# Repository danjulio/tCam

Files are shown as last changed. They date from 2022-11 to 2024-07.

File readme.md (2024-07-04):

## ESP32-based Thermal Imaging Cameras
tCam, tCam-Mini, tCam-POE and tCam-Eth are four cameras I designed around the ESP32 and Lepton 3.5.  They are designed to provide easy access to radiometric data from the Lepton.  Radiometric data is useful because it contains temperature information for each pixel in the camera's image allowing for all kinds of data analysis even if the image is stored to a file.

This repository was created on Nov 6, 2022 from the ESP32 section of my original [Lepton](https://github.com/danjulio/lepton) repository to reduce the size of the portion of that directory that most people are interested in.

### tCam
tCam is a full featured, battery powered camera with a local touchscreen display, local storage and a WiFi interface.  It is comprised of a [gCore]() and tCam-Mini.  A tCam kit can be purchased from Group Gets [here](https://store.groupgets.com/products/tcam-kit).

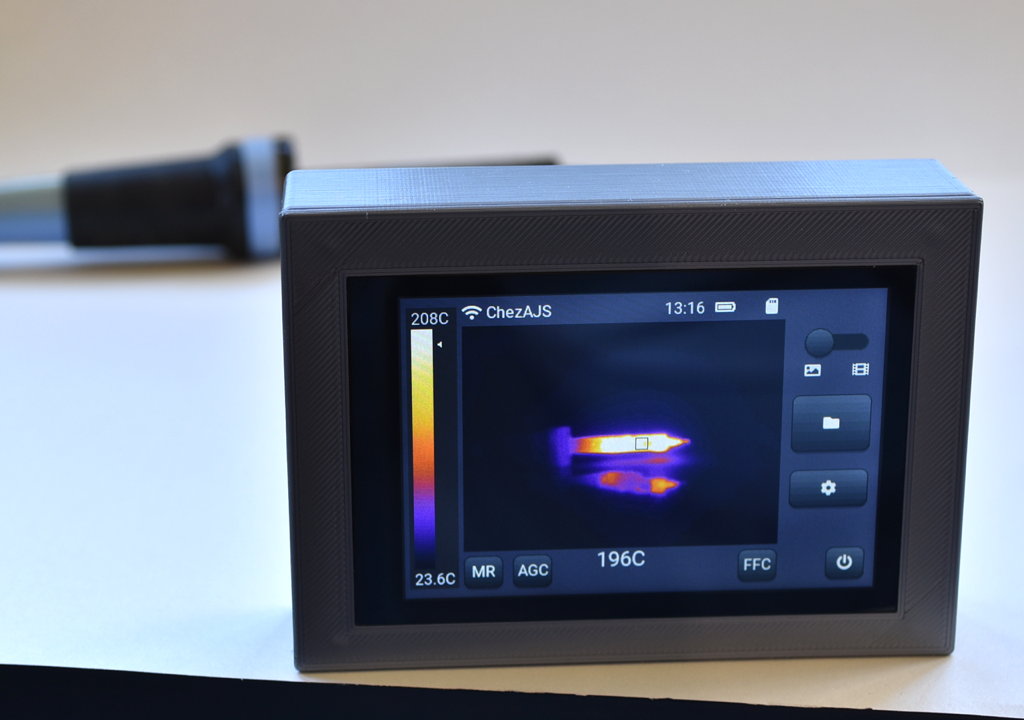
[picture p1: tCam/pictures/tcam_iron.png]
tCam


### tCam-Mini
tCam-Mini is a smaller camera designed for streaming and remote access.  It supports a Wifi or hardwired interface.  It can be built using development boards or a tested unit can be purchased from Group Gets [with built in antenna](https://store.groupgets.com/products/tcam-mini-rev4-wireless-streaming-thermal-camera-board) or [with an external antenna](https://store.groupgets.com/products/tcam-mini-rev4-external-antenna-wireless-streaming-thermal-camera-board).

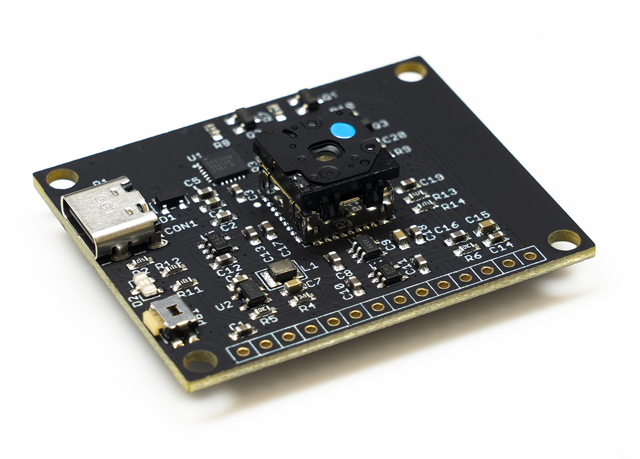
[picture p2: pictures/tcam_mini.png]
tCam-Mini

(Photo Credit: Matthew Navarro)

### tCam-POE
tCam-POE is a network only camera designed to work with hardwired POE connections (it also supports a Wifi connection).  At the moment, a grand total of six units have been built to validate the design (included here) or supply a custom order.

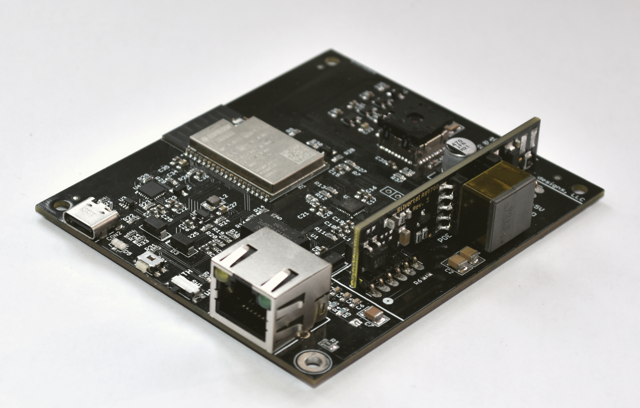
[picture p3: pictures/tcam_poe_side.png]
tCam-POE


### tCam-Eth
tCam-Eth is a ethernet connected camera designed to be incorporated with other electronics.  It was designed as part the [FireTIRS](https://github.com/jthompson2710/FireTIRS) project but is made available as an open source hardware design.

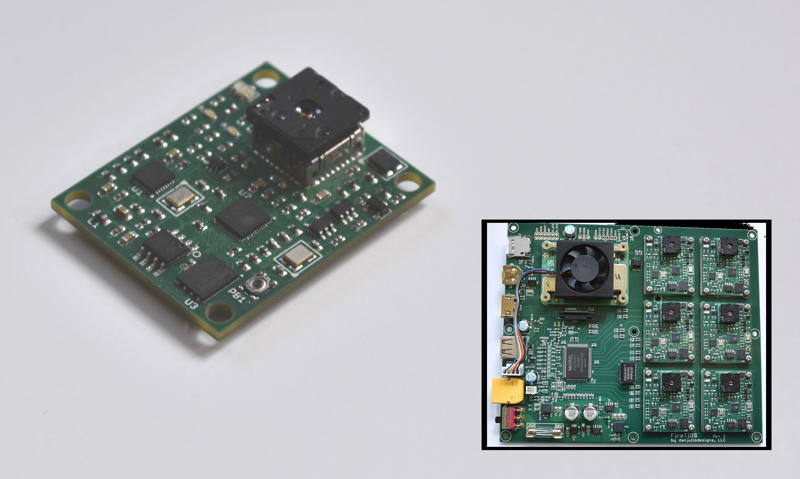
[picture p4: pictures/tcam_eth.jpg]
tCam-Eth


### Desktop Application
All three cameras share a common command set for remote access.  A companion Desktop computer application may be used to configure and access the cameras, download new firmware, as well as perform some analysis.

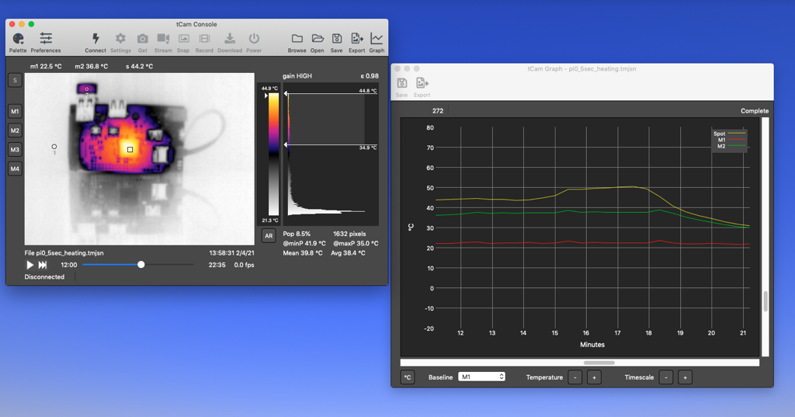
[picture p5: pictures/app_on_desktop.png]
Desktop Application


### Android Application
Connect, view and save images on an Android phone using the [Android App](https://play.google.com/store/apps/details?id=com.danjuliodesigns.tcamViewer) by Jim Turner.  The source may be found at the [repo](https://github.com/yaturner/tcamViewer-DanJulio).

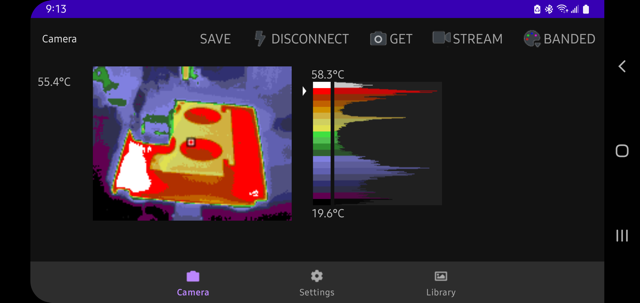
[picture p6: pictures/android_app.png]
Android App


### IOS Application
Connect, view and save images on an iPhone or iPad using the [IOS App](https://apps.apple.com/us/app/tcamview/id1610451813).  Documentation may be found on my [website](https://danjuliodesigns.com/products/tcam_app.html).

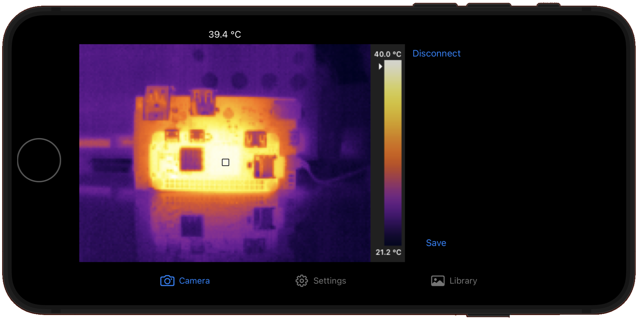
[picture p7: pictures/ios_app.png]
IOS App


### Web Server
A simple stand-alone server that can connect to multiple cameras, record images that meet certain criteria and display images from the cameras in a web browser.

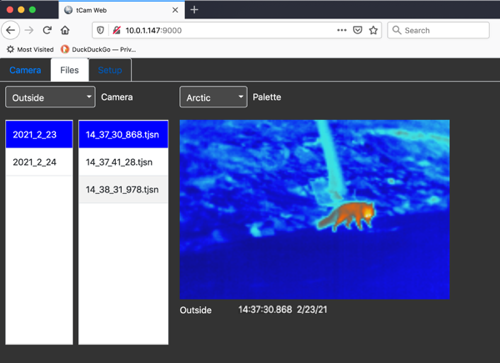
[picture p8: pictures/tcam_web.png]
Web Application


### Python Driver
A simple driver to allow access from python programs makes it easy to write your own software to access the cameras.  The python driver supports either a network connection to any camera, or a hardwired connection to tCam-Mini from a Raspberry Pi.

### R Driver
Bob Rudus wrote a R driver for tCam-Mini that can be found in his [github repository](https://github.com/hrbrmstr/tcam).

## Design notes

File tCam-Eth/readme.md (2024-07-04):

## tCam-Eth
tCam-Eth was developed for the [FireTIRS](https://github.com/jthompson2710/FireTIRS) project as a small ethernet connected thermal imaging camera.  It runs on 3.3V and exposes the TX and RX differential pairs from the ethernet PHY chip (it does not contain any magnetics), as well as a 3.3V logic serial interface.  It runs the tCam-Mini firmware, starting with version 3.0, and identifies as a tCam-POE device (configured for network operation).

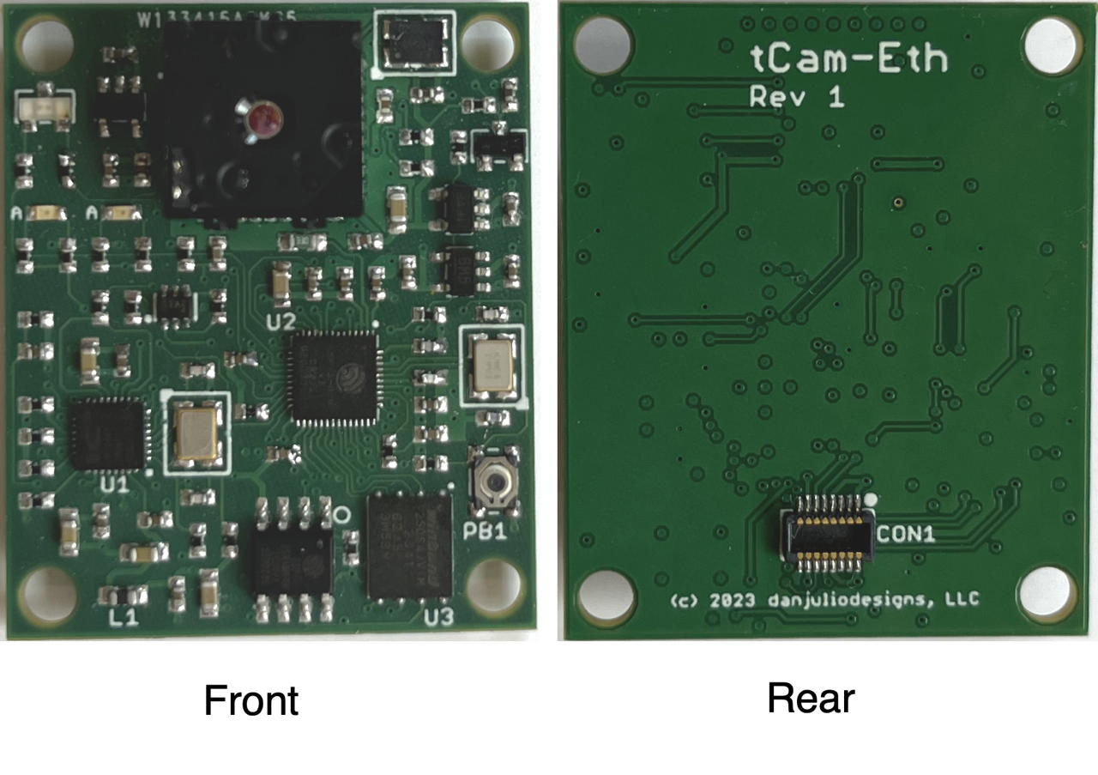
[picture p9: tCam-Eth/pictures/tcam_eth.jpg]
tCam-Eth Assembly


A baseboard containing a USB UART chip and Magjack RJ45 ethernet connector was also developed and is used for initial programming and test of tCam-Eth boards.

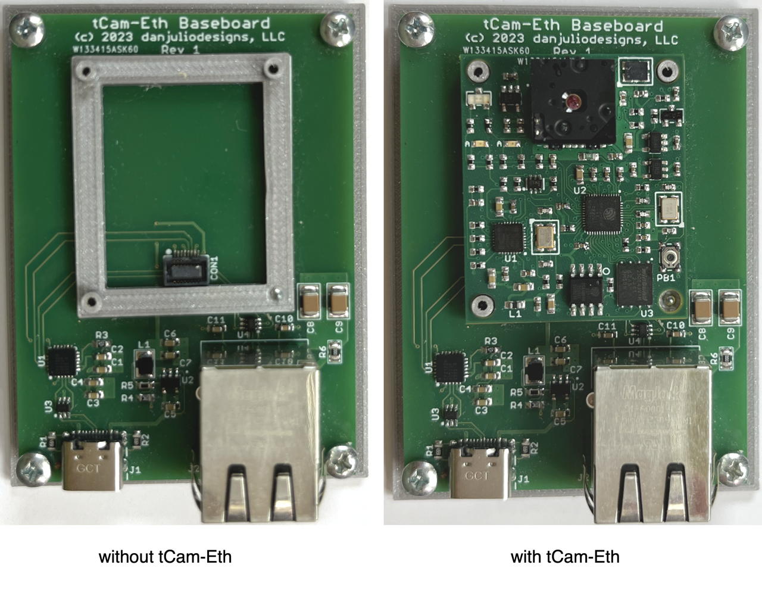
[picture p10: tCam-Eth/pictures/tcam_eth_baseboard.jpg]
tCam-Eth Baseboard Assembly


This directory contains the hardware design and documentation for both boards.

1. Eagle V7.7 design files.
2. Gerbers (including paste layer for stencils).
3. Bill-of-Material (BOM).
4. Additional electronics documentation such as printed schematics, reference designator drawings, load list, etc.
5. Supporting mechanical designs for spaces and base mounts.

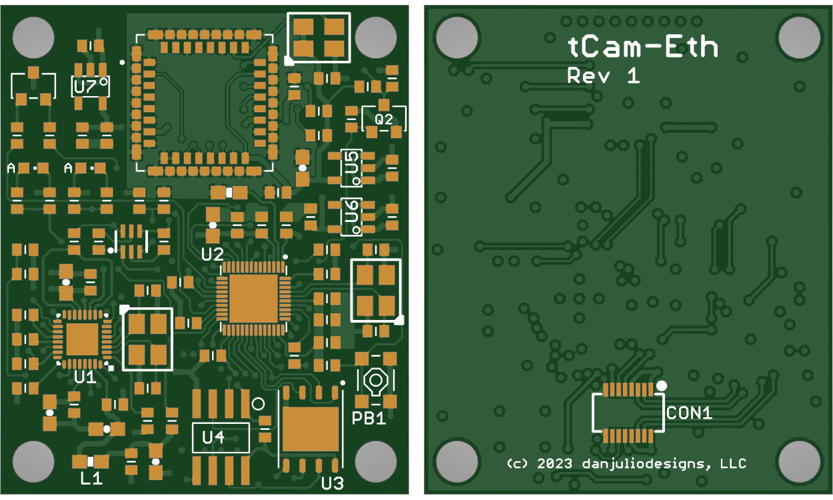
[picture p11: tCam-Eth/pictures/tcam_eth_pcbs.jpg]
tCam-Eth PCB Top


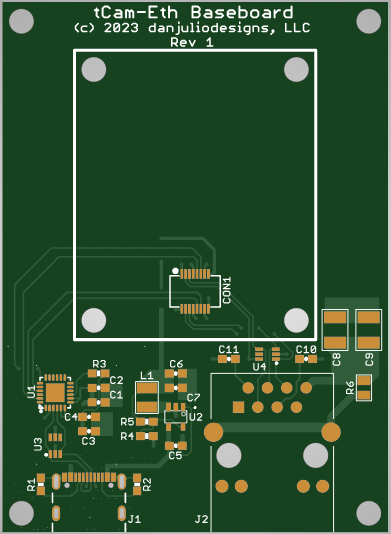
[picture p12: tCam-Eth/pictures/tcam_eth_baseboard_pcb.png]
tCam-Eth Baseboard PCB Component side


Please see the tCam-Mini directory for a detailed description of the command interface.

### Dimensions

tCam-Eth is 1.25 x 1.5" (31.75 x 38.10mm).

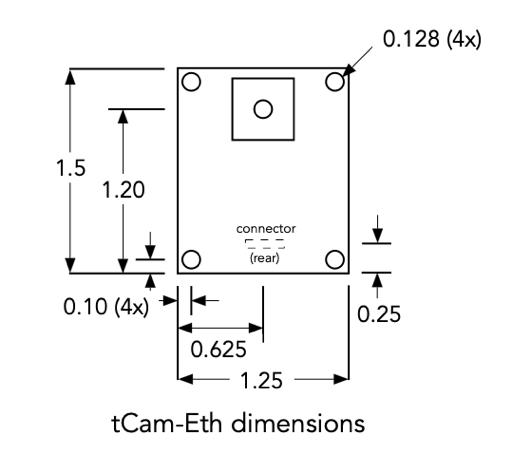
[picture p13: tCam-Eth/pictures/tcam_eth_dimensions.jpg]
tCam-Eth Dimensions


tCam-Eth Baseboard is 2 x 2.75" (50.8 x 69.85mm).

### Lepton Compatibility
tCam-Eth works with the following Lepton camera modules.

1. Lepton 3.0
2. Lepton 3.1R
3. Lepton 3.5

### Hardware Interfaces

#### tCam-Eth Hardware Interface
Connector CON1 (tCam-Eth PCB bottom) contains the following signals.

| Pin | Description |
| --- | --- |
| 1 | Ground |
| 2 | Ethernet TD+ (PHY output) |
| 3 | Ethernet TD- (PHY output) |
| 4 | Ground |
| 5 | Serial DTRN input (3.3V logic) |
| 6 | Serial RTSN input (3.3V logic) |
| 7 | Ground |
| 8 | +3.3V Power |
| 9 | +3.3V Power |
| 10 | Ground |
| 11 | Serial RX input (3.3V logic) |
| 12 | Serial TX output (3.3V logic) |
| 13 | Ground |
| 14 | Ethernet RX+ (PHY input) |
| 15 | Ethernet RX- (PHY input) |
| 16 | Ground |

The external 3.3V power supply must be regulated to +/- 5% and capable of supplying 500 mA (typical current consumption is < 200 mA).

#### tCam-Eth Baseboard Hardware Interfaces
Connector J1 is a USB-C connector used to provide power and serial communications.

Connector J2 is a RJ45 connector used to provide 10/100M bps ethernet communications.

### Operation
tCam-Eth is a command-based device.  It is designed for software running on another device to control it and receive responses and image data from it.  The command interface is described in the tCam-Mini firmware directory.

#### Ethernet Port
The ethernet port support an IEEE 803.2 10/100 Mbps ethernet interface.  tCam-Eth provides the direct TX and RX differential pairs from the on-board PHY chip.  It may be used in a direct connect fashion (as is done on the FireTIRS board) or with a traditional set of magnetics connected to an isolated RJ45 jack (as is done on the tCam-Eth Baseboard).

tCam-Eth can obtain a DHCP served address from a router on the network or may be configured with a static IP address.

#### Serial Port
tCam-Eth provides a 3.3V logic-level serial interface along with RTSN and DTRN flow-control inputs.  These are used to load firmware into the on-board ESP32 micro-controller (for example using the tCam-Eth Baseboard).  They may also be used to monitor the diagnostic serial output while the firmware is running.

#### Status Indicators
A dual-color (red/green) LED is used to communicate status (reference designator LED3).  Combinations of color and blinking patterns communicate various information.

| Status Indicator | Meaning |
| --- | --- |
| Off or Dim | Firmware did not start |
| Solid Red | Firmware is running: initializing and configuring the Lepton and Ethernet interface |
| Blinking Yellow | No ethernet network detected |
| Solid Yellow | Ethernet is connected and the camera has an IP address |
| Solid Green | Ethernet is connected and external software has connected via the socket interface |
| Fast Blink Yellow | Network Reset in progress |
| Alternating Red/Green | Over-the-air (network) FW update has been requested.  Press the button to initiate the update |
| Blinking Green | FW update in process (blinking my occur at irregular intervals as the Flash memory is written) |
| Series of Red Blinks | A fault has been detected.  The number of blinks indicate the fault type (see table below) |

| Fault Blinks | Meaning |
| --- | --- |
| 1 blink | ESP32 I2C or SPI peripheral initialization failed |
| 2 blinks | ESP32 Non-volatile storage or Network initialization failed |
| 3 blinks | ESP32 static memory buffer allocation failed (potential PSRAM issue) |
| 4 blinks | Lepton CCI communication failed (I2C interface) |
| 5 blinks | Lepton VoSPI communication failed (SPI interface) |
| 6 blinks | Internal network error occurred |
| 7 blinks | Lepton VoSPI synchronization cannot be achieved |
| 8 blinks | Over-the-air FW Update failed |

Additional start-up and fault information is available from the Serial interface.

A single-color yellow LED is used to communicate network Link/Activity (reference designator LED1).

A single-color green LED is used to communicate network 100 Mbit operation (reference designator LED2).

#### Network Reset Button
Pressing and holding the Network Reset Button for more than five seconds resets the network interface back to the default mode (requesting a DHCP served address).

Pressing the button quickly when an OTA FW update has been requested (LED alternating red/green) by the Desktop application initiates the update process.

#### mDNS Discovery
The cameras advertise themselves on the local network using mDNS (Bonjour) to make discovering their IPV4 addresses easier.

* Service Type: "\_tcam-socket._tcp."
* Host/Instance Name: Camera Name (e.g. "tCam-Mini-821F")
* TXT Records:
	1. "model": Camera model (always "tCam-POE")
	2. "interface": Communication interface (always "Ethernet")
	3. "version": Firmware version (e.g. "3.2")

### Mounting Hardware
Three supporting hardware pieces, designed using OpenSCAD, are designed to be 3D printed.  Both the OpenSCAD source and compiled STL files are included.

### Application spacer
The Application spacer is designed to mount tCam-Eth board to the application PCB via 4 M2x8mm screws, nuts and washers.  The cutout region aligns with the connector end of tCam-Eth.

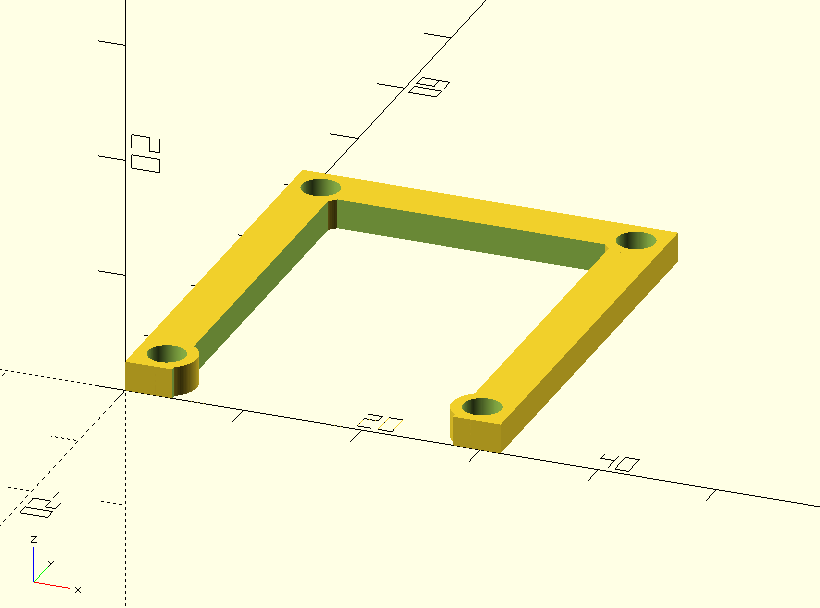
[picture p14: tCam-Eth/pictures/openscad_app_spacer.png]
Application spacer OpenSCAD design


### Baseboard spacer
The Baseboard spacer is designed to be mounted (carefully aligned) on the Baseboard using double-sticky tape or screws from the bottom.  It holds the tCam-Eth board in the correct position but makes it easy to insert and remove.

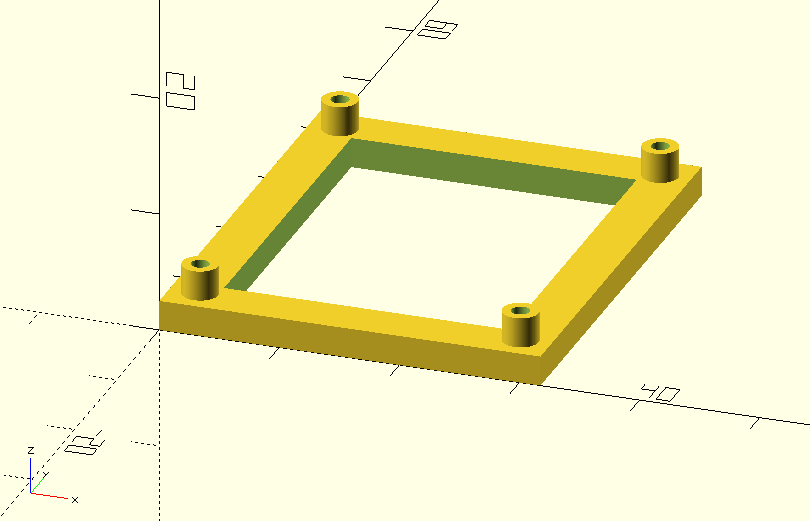
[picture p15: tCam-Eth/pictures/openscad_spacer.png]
Baseboard spacer OpenSCAD design


### Baseboard mount
The Baseboard mount is designed to hold the tCam-Eth Baseboard.  The Baseboard is screwed to the mount using #4, M3 or similar pointed screws.

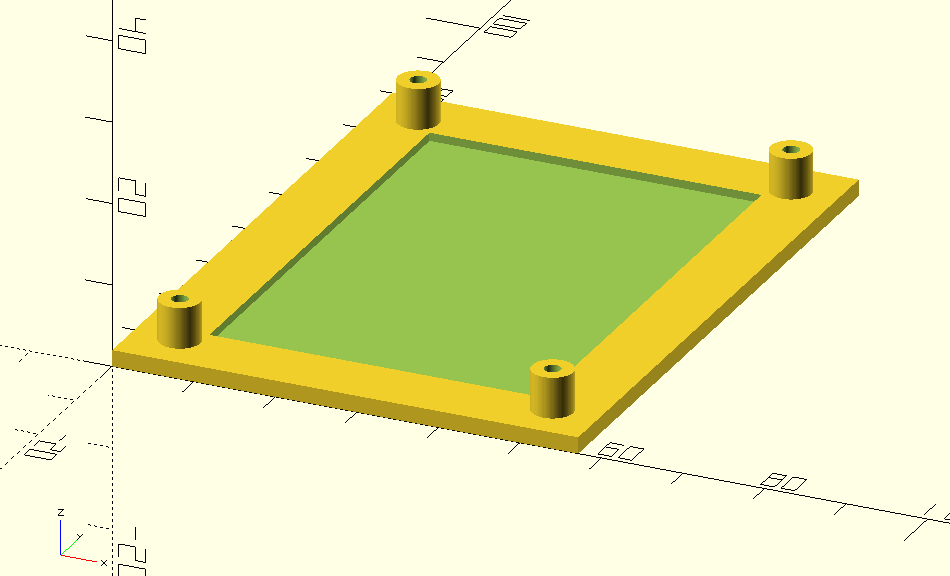
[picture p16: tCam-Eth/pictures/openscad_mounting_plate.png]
Baseboard mount OpenSCAD design


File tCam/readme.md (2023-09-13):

## tCam
tCam is a thermal imaging camera comprised of the hardware components [gCore](https://github.com/danjulio/gcore) and tCam-Mini, and the firmware in this directory.

tCam imaging a solder iron

### Firmware
The "Firmware" directory contains a V4.4.4 Espressif ESP32 IDF project for tCam. You should be able to build and load it into a camera using the IDF commands.  There are also a set of precompiled binaries in the "precompiled" sub-directory.

#### Initial firmware load
There are three ways to initially load the tCam firmware onto a gCore (which comes with different firmware loaded initially).

1. Use the ESP32 IDF ```idf.py``` tool to load the firmware if you are building it yourself.  This is described in the firmware directory.  If you know what you are doing you can also use this tool to load the precompiled binary images.
2. Use the Windows-only Espressif tool and instructions found in the "programming" directory in parallel to this one to load the precompiled binary images onto a gCore without having to build the project.
3. Use the multi-platform tCam Family Serial Updater utility I wrote also found in the "programming" directory. It automatically downloads the most current firmware binaries from my website and writes them to a gCore (it can also load tCamMini firmware into tCam-Mini or tCam-POE boards).  It runs on 64-bit  Linux x86, Mac OS X and Windows computers.  It's the easiest way.  Just select the serial port and hit program.

The tCam Family Serial Updater, precompiled firmware, and Windows-based programming application can also be downloaded individually from my [website](http://danjuliodesigns.com/products/tcam.html) as well if you don't want to clone this entire repository.

#### OTA firmware loads

Over-the-air (OTA) updates can be used to load new firmware using the Desktop application once the tCam firmware has been initially loaded on gCore.

#### tCam-Mini compatibility

The connected tCam-Mini should be running FW 3.1 or later.

### Hardware
The minimum hardware for tCam is a gCore, a Revision 4 PCB tCam-Mini, Li-Ion or LiPo battery and connecting wires or headers.  An optional micro-SD card can be used to locally store images or videos.  Depending on the enclosure it may be helpful to also connect an external push-button the the SW/GND terminals on gCore so that gCore's power button is easily accessible.  The power button serves double duty.  It is used to turn the camera on and once on it is used to take a picture or start/stop a video recording (holding it for longer than 5 seconds will turn off power).

The connections between gCore and tCam-Mini are shown below.  A jumper between the MODE connection and GND on tCam-Mini configures it to use the hardware interface.

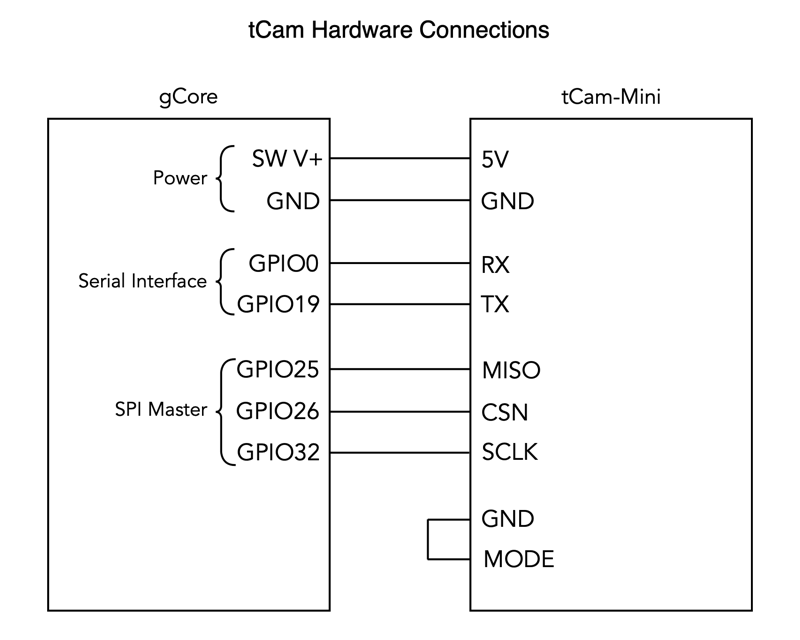
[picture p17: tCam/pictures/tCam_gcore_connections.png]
tCam wiring diagram


gCore's USB connector is used to charge the battery or power the camera from a mains connection.

The hardware interface on tCam-Mini Revision 4 was designed to mate directly with gCore GPIO pins as shown in the following images with the following headers.

1. 8-pin 0.1" (2.54mm) female header soldered on the gCore component side starting with the SW V+ connection. 
2. 10-pin 0.1" male header soldered on the ESP32 side of tCam-Mini in the Slave IF connections (the I2C expansion connections are unused).  I use 6.2 mm height pins.
3. 2-pin 0.1" jumper attached to the MODE and GND pins of the tCam-Mini header.

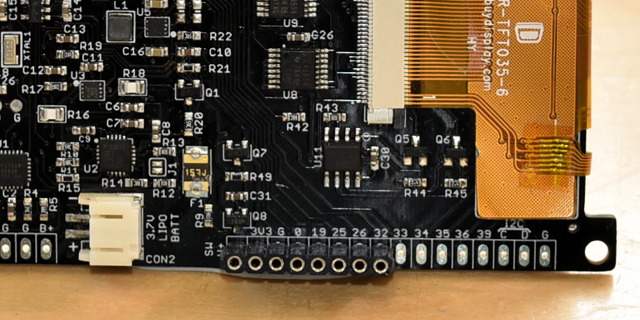
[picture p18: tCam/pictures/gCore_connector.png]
gCore connector


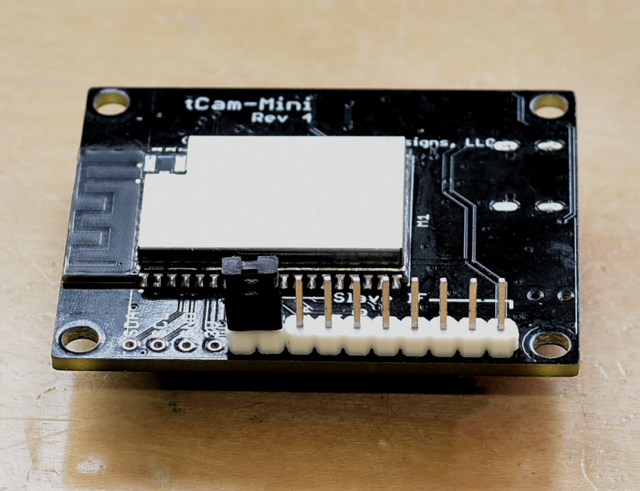
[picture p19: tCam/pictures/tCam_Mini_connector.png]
tCam-Mini connector


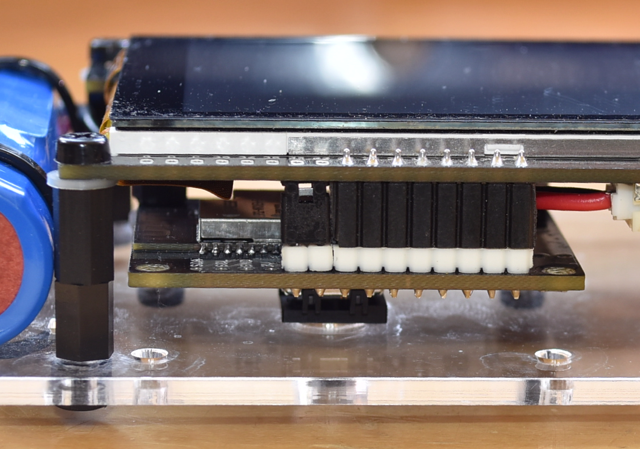
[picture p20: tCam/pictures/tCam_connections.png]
Boards connected


#### Important Notes

1. Never connect USB Power to tCam-Mini when it is attached to gCore.  Doing so will back-power gCore and will damage it and/or the battery.  Only connect USB power to gCore.
2. Be very careful with the tCam-Mini when soldering the header.  The Lepton is very fragile and it is easy to damage the shutter with too much pressure (I know...).  Probably best if you carefully remove it before soldering on the header and then carefully re-install it (making sure it is fully inserted into the socket) before installing tCam-Mini into the enclosure.
3. Remember to remove the jumper when removing tCam-Mini from gCore if you wish to use it with WiFi again and then re-install it before re-attaching to gCore (I forgot this all the time...).

### Enclosures
Two simple enclosure designs in included in this repository, one designed to be cut on a laser cutter and one designed to be 3D printed.

### Operation
tCam may be controlled locally using the graphics user interface or remotely using a command-based interface available via WiFi.  GUI operation is described below.  The command interface is described in the firmware directory.

#### gCore Power Button
The gCore power button provides multiple functions.

1. Power on
2. Shutter control (short press while camera is operating)
3. Hard power off (held longer than five seconds causes gCore to switch power off)

#### gCore Micro-SD Card
Images and video files can be stored, played back and retrieved by software over the WiFi interface.  Files are the same format (.tjsn and .tmjsn) as used by the Desktop and Mobile applications.  Filenames are created from the image timestamp and stored in directories created from the date portion of the timestamp.

#### gCore USB Connector
The gCore USB connector is used to provide power to the camera, charge the battery and as a programming/diagnostic interface for the tCam code running on gCore.

I advise closing the charge current jumper (J1) on gCore allowing 1A maximum charge current for LiPo batteries larger than 2000 mAh and leaving it open for smaller batteries.

Diagnostic information is output on the USB serial port at 115,200 baud.

#### gCore WiFi
tCam can act as either an Access Point (creating its own WiFi network) or a client (connecting to an existing WiFi network) or WiFi may be disabled.  It operates in the 2.4 GHz band.  The camera acts as an Access Point (AP) by default.  It selects an SSID based on a unique MAC ID in the ESP32 with the form "tCam-HHHH" where "HHHH" are the last four hexadecimal digits of the MAC ID.  There is no password by default.  When acting as an Access Point, each tCam always has the same default IPV4 address (192.168.4.1).

It can be reconfigured via the GUI or a command (for example, from the desktop application) to act as a WiFi Client (STAtion mode) and connect to an existing WiFi network.  When configured as a WiFi Client, it can either get a DHCP served address from the network's router or it can also be reconfigured to have a fixed (static) IPV4 address.  Using a static address makes it easier to connect to tCam because you don't have to find out what DHCP address the router gave it by logging into the router or using a utility like the Fing Android app or nmap on Linux.

Currently only one device can connect to the camera at a time.

Please see the set of instructions in the DesktopApp folder in this repository for connecting to tCam in either mode.

##### mDNS Discovery
tCam cameras advertise themselves on the local network using mDNS (Bonjour) to make discovering their IPV4 addresses easier.

* Service Type: "\_tcam-socket._tcp."
* Host/Instance Name: Camera Name (e.g. "tCam-198D")
* TXT Records:
	1. "model": Camera model (tCam returns "tCam")
	2. "interface": Communication interface (tCam returns "WiFi").
	3. "version": Firmware version (e.g. "1.0")

#### gCore NVRAM / NVFlash
tCam settings are stored in gCore's NVRAM and written to the NVFlash when the camera is switched off.

### Graphical User Interface
tCam displays several screens in order to view the stream coming from the attached tCam-Mini, configure the camera or browse stored images and videos.

#### Main Screen
The Main Screen is displayed when tCam is turned on.

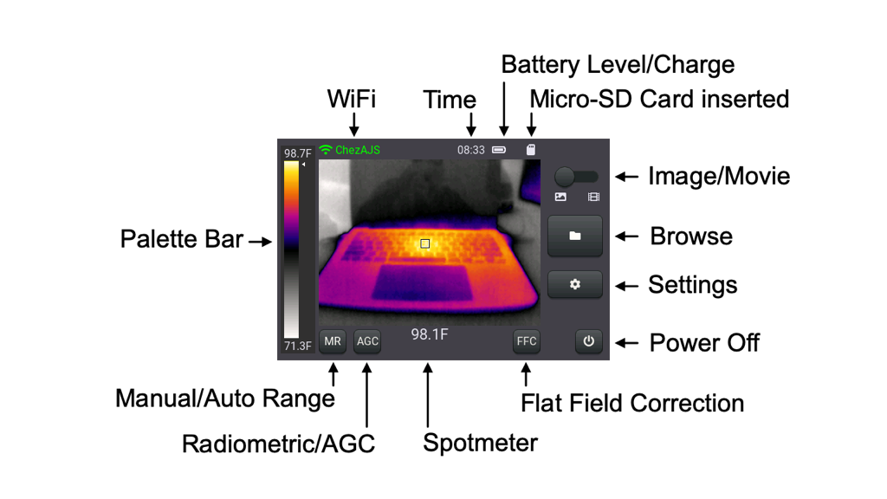
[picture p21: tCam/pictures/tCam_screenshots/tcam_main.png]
tCam Main Screen


| Control | Description |
|---|---|
| AGC/RAD | Toggles between Radiometric and AGC modes in the Lepton sensor. |
| Battery Level/Charge | A battery indicator shows the current charge level in 25% increments.  A charge indicator (not shown above) indicates when the battery is charging. |
| Browse | Displays last recorded image or movie on the Browse Screen. |
| FFC | Initiate a manual flat-field correction in the Lepton sensor. |
| Image/Movie | Toggles between recording image (.tjsn) files or movies (.tmjsn) to the Micro-SD card when Shutter button is pressed (or remote command issued). |
| Manual/Auto Range | Toggles between Manual Range and Automatic Range for image mapping to the selected palette.  Automatic Range maps the image to the palette using the minimum and maximum temperatures found in each image.  Manual Range allows establishing a set minimum and maximum temperature used to map the image to the palette.  This is helpful when recording to prevent colors from jumping all over the place or when imaging a scene with a range of temperatures you wish to exclude.  Manual Range is sometimes called Span Locking.  Clicking the MR button will set a manual range rounded up and down from the current image. |
| Micro-SD Card | The SD Card icon is shown when a Micro-SD card is inserted and the camera can record images or movies. |
| Palette Bar | Displays the current selected pseudo-color mapping palette.  Clicking either the top or bottom of the palette will select the next or previous palette in the set of palettes provided by tCam. The spotmeter temperature within the range is indicated by the marker to the right of the bar. For radiometric images the image minimum and maximum temperatures are shown at the bottom/top of the palette.  For AGC images the word "AGC" is displayed at the bottom.  If running a tCam-Mini with a Lepton 3.0 then the word "RAW" is displayed at the bottom of the bar. |
| Power Off | Turns the camera off (soft power off).  Use this instead of holding the power button for five seconds to ensure any changed settings are saved in NVFlash. |
| Settings | Displays the main Settings Screen. |
| Spotmeter | The spotmeter displays the temperature in a 2x2 pixel area of the image marked with the small square.  Tapping the spotmeter temperature will blank the spotmeter.  Tapping the image will relocate the spotmeter marker (and redisplay the spotmeter temperature if it has been blanked). |
| Time | The camera time (hours and minutes) is shown.  Important to set the time (the applications do it automatically) because it is used to timestamp images. |
| WiFi Status | The WiFi SSID is shown in white when WiFi is enabled (either the camera name for AP mode or the WiFi name for client/station mode).  The status turns green when a software program is connected to the camera. |

The spotmeter, minimum and maximum temperature points may be indicated by markers over the image.  The minimum and maximum temperature points may not be displayed when AGC is enabled.

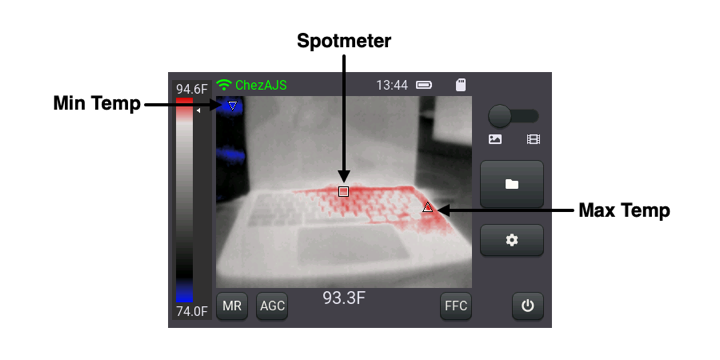
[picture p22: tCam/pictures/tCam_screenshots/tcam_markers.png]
tCam Image with spotmeter and min/max markers


The area under the spotmeter temperature is used to display temporary status messages including a new palette when one is selected or the filename of an image or video when the shutter button is pressed.  The message is displayed for about a second.

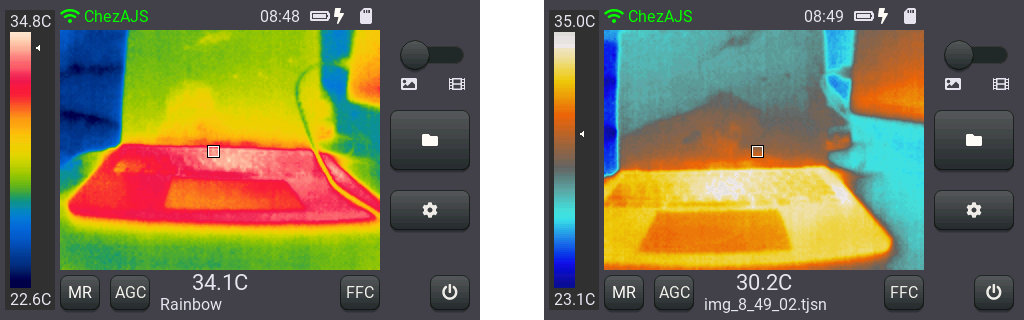
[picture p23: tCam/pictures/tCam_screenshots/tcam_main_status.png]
tCam Main Screen


#### Settings Screen
The Settings Screen is used to configure the camera.

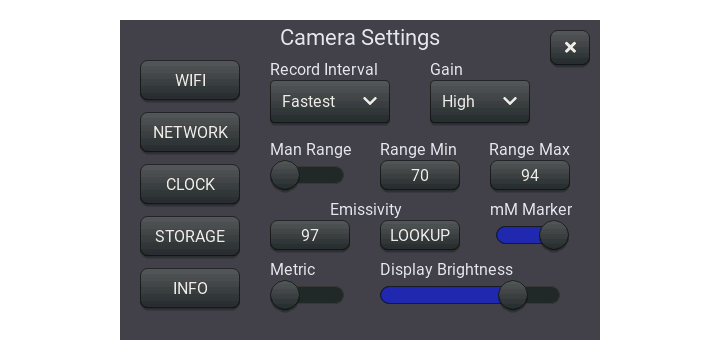
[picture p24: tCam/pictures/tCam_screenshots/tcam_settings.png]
tCam Settings Screen


| Control | Description |
| --- | --- |
| CLOCK | Displays the Clock Setup Screen. |
| Display Brightness | Sets the LCD backlight brightness. |
| Emissivity Value | Displays a numeric keypad screen to enter an emissivity value for the Lepton. |
| Emissivity LOOKUP | Displays the Emissivity Lookup Screen which contains a list of materials which can be selected to set an appropriate emissivity value. |
| Gain | Select the Lepton Gain (Auto, Low, High) using a drop-down menu. |
| INFO | Displays the Camera Information Screen. |
| Man Range | Enable or disable Manual Range. |
| Range Min | Displays a numeric keypad screen to enter a minimum temperature for Manual Range (in the current units). |
| Range Max | Displays a numeric keypad screen to enter a maximum temperature for Manual Range (in the current units). |
| mM Marker | Enable or disable Min/Max Temperature markers. |
| Metric | Toggles between Imperial and Metric units (°F or °C). |
| NETWORK | Displays the Network Setup Screen. |
| Record Interval | Select the rate to store images when recording a movie using a drop-down menu.  The rate can vary from the fastest (~8.8 FPS) to one image every five minutes. |
| STORAGE | Displays the Manage Storage Screen. |
| WIFI | Displays the WiFi Setup Screen. |
| X | Exit back to Main Screen |

Settings changed directly on this screen are applied (and saved) when the Exit button is pressed.

The numeric entry screens for Emissivity, Min and Max Range look like the following.

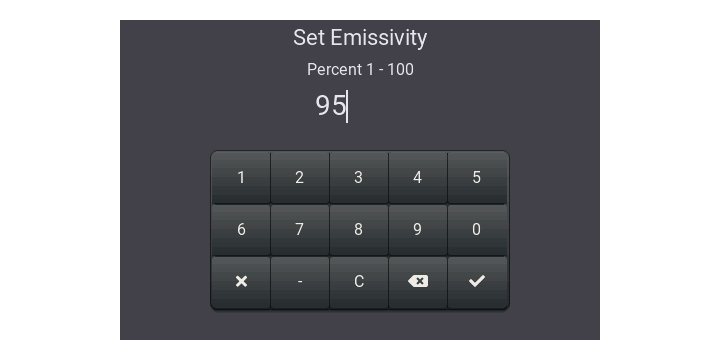
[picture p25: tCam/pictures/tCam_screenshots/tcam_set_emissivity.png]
tCam Set Emissivity Screen


The 'X' button returns to the previous screen without change.  The 'C' button clears the value.  The backspace button clears the last entered number.  The checkmark button saves the new setting and returns to the previous screen.

#### Browse Screen
The Browse Screen is used to view files on the Micro-SD card.  When displayed it shows the last recorded image or video.  The Browse Screen displaying an image file is shown below.  The Browse screen is displayed with the current palette and min/max marker settings.

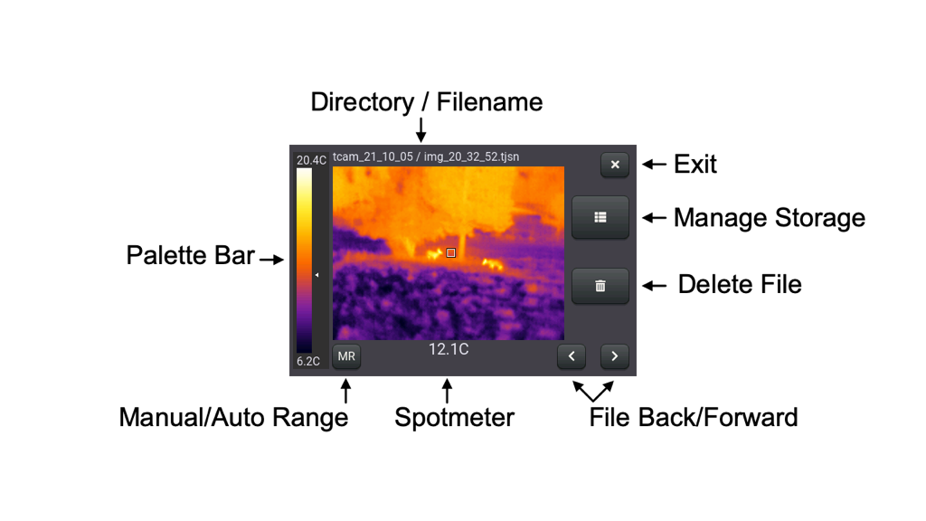
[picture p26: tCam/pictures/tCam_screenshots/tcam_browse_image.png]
tCam Browse Screen


| Control | Description |
|---|---|
| Delete File | Deletes the currently shown file.  A confirmation dialog box is displayed allowing you to cancel. |
| Directory / Filename | Displays the current image's directory (folder) and filename on the Micro-SD card. |
| File Back/Forward | Displays the previous or next file. |
| Manage Storage | Displays the Manage Storage Screen where directories and files can be seen. |
| Manual/Auto Range | As with the Main Screen, toggles between Manual Range and Automatic Range for image mapping to the selected palette.  Useful while viewing a movie to prevent changes in scene temperature range from radically changing the color mapping as the movie plays. |
| Palette Bar | As with the Main Screen, displays the current selected pseudo-color mapping palette.  Clicking either the top or bottom of the palette will select the next or previous palette in the set of palettes provided by tCam.  The current Main Screen palette is used when entering the Browse Screen. |
| Spotmeter | Displays the spotmeter value recorded in the current image.  The spotmeter location cannot be changed although tapping the spotmeter temperature readout will blank the spotmeter and touching the image will redisplay it. |
| X | Exit back to Main Screen |

An additional Play/Stop button and current timestamp is displayed when viewing a movie as shown below.

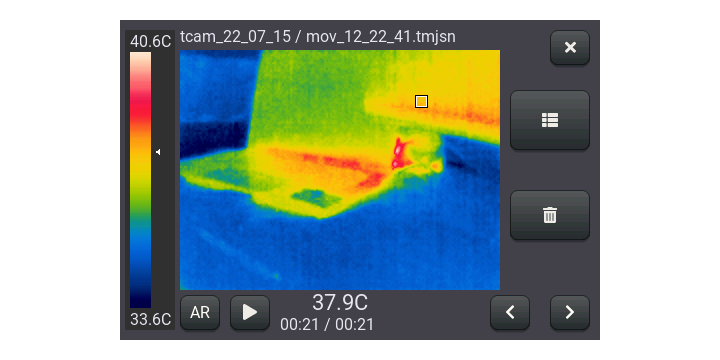
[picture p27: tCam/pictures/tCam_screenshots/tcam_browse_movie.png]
tCam Browse Movie


#### WiFi Setup Screen
The WiFi Setup Screen configures tCam's 2.4 GHz WiFi interface.  Touching the SSID or PW textfield allows changing that field using the keyboard.

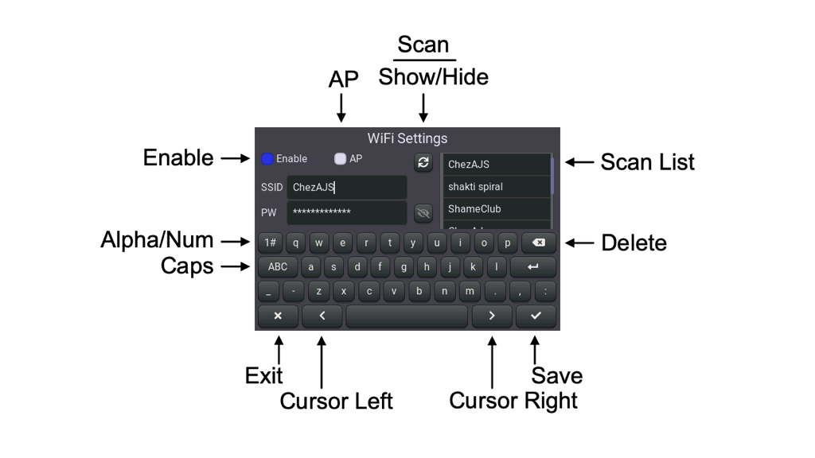
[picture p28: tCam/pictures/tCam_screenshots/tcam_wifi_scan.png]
tCam WiFi Setup Screen


| Control | Description |
|---|---|
| Alpha/Num | Toggle the keyboard between alphabetical or numeric/punctuation character sets. |
| AP | Configure the WiFi interface as an Access Point (AP) advertising its SSID as a WiFi network or as a client (STAtion mode) connecting to an existing WiFi network. |
| Caps | Toggle between alpha text in capital or lower-case mode. |
| Cursor Left/Right | Non-destructively move the cursor one position to the left or right in the selected text field. |
| Delete | Destructive backspace for the cursor in the selected SSID or PW text field. |
| Enable | Enable or disable the WiFi interface. |
| Exit | Discard any changes and return to the Settings Screen. |
| Scan | Start a scan for existing WiFi networks.  tCam displays a spinner above the Scan List while the scan is in progress and disconnects from any existing networks. Scan is only available when the camera is not in AP mode. |
| Scan List | Displays a scrollable list of SSIDs discovered during a scan.  Click an entry to load it into the SSID text field. |
| Show/Hide | Toggles visibility of the password text field. |
| Save | Save any changes and return to the Settings Screen. The WiFi subsystem is restarted with the new configuration. |

#### Network Setup Screen
The Network Setup Screen is used to configure a static IPV4 address when the WiFi is operating as a client to another network.  Decimal numbers (0-255) are entered into each of the four octets for the IP Address and Netmask.  When not enabled the camera will request a DHCP served address from the network router.

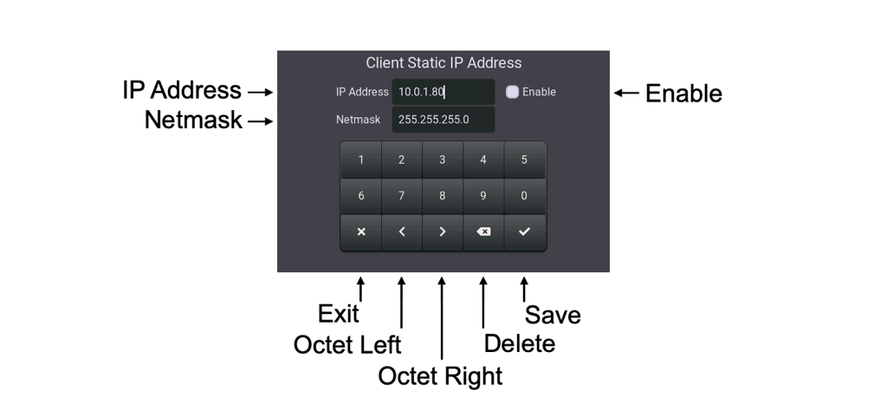
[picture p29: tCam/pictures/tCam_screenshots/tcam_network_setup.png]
tCam Network Setup Screen


| Control | Description |
|---|---|
| Delete | Destructive backspace for the cursor in the selected IP Address or Netmask text field. |
| Enable | Enable or disable a static IP address when operating in STAtion mode. |
| Exit | Discard any changes and return to the Settings Screen. |
| IP Address | The static IP address.  Make sure you pick a number outside the range the router might assign using DHCP. |
| Netmask | The network netmask.  Typically 255.255.255.0. |
| Octet Left/Right | Move the cursor to the previous or next octet. |
| Save | Save any changes and return to the Settings Screen. |

#### Clock Setup Screen
The Clock Setup Screen is used to manually set the Real Time clock.  The time and date are used to timestamp images and videos.  The numeric keypad is used to enter the time.  The current digit is highlighted.  The time is also automatically set by the Desktop and mobile apps.

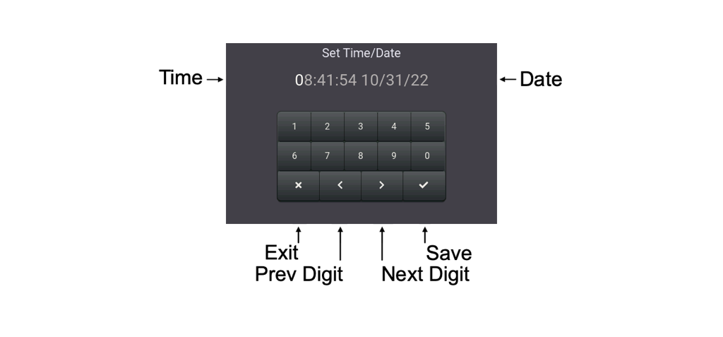
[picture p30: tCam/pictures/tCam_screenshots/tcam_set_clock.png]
tCam Clock Setup Screen


| Control | Description |
|---|---|
| Date | Camera date in the form MM:DD:YY where YY is a year in the 21st century. |
| Exit | Discard any changes and return to the Settings Screen. |
| Prev/Next Digit | Move the currently selected (highlighted) character back or forward one position. |
| Save | Save any changes and return to the Settings Screen. |
| Time | Camera time in the form HH:MM:SS where HH is in 24-hour format (0-23). |

#### Manage Storage Screen
The Manage Storage Screen lists folders and files and allows operations on those items.  The Screen displays all existing Folders.  Selecting a Folder displays the files in that folder.  Selecting a file allows that file to be viewed in the Browse Screen.

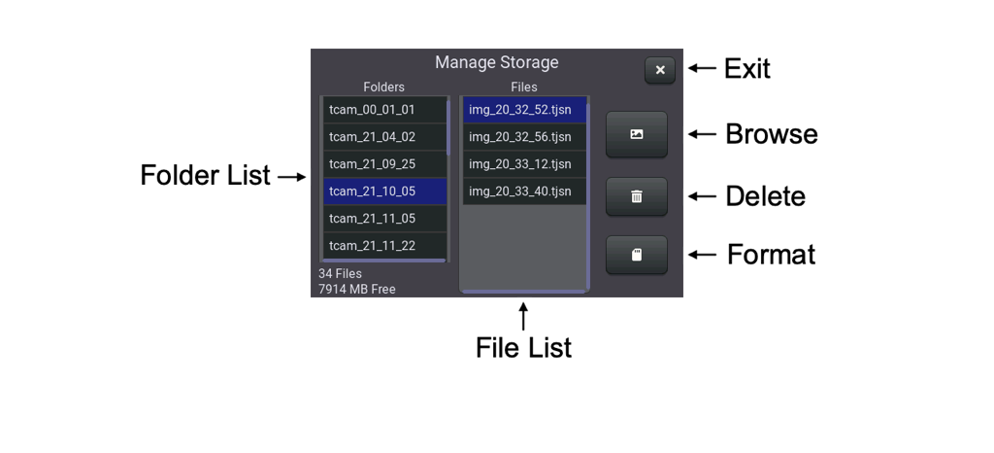
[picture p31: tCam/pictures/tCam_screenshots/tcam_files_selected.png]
tCam Manage Storage Screen


| Control | Description |
|---|---|
| Browse | Available when a file has been selected.  Displays the file in the Browse Screen. |
| Delete | Available when either a Folder or a File has been selected.  Deletes the entire Folder if only a Folder has been selected.  Deletes the file is it has been selected.  A confirmation dialog is displayed before the delete operation. |
| Exit | Returns to the Settings Screen. |
| File List | List of files in the selected Folder. |
| Folder List | List of folders on the Micro-SD card. |
| Format | Formats the Micro-SD card. A confirmation dialog is displayed before the format operation. |

#### Emissivity Lookup Screen
The Emissivity Lookup Screen displays a scrollable list of materials.  Selecting a material shows its emissivity value.  This can be saved and set as the camera's emissivity value by clicking the checkmark.  Clicking the X button exits the screen without saving the value.  The values were taken from a Fluke emissivity table and a Mikron emissivity list (but as you all know, emissivity is a complex thing).

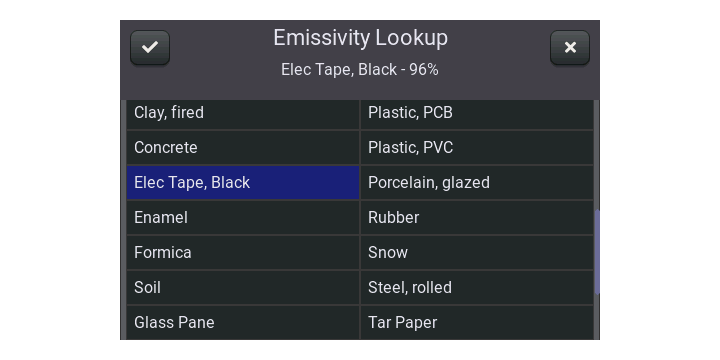
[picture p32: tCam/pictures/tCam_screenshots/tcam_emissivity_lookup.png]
tCam Emissivity Lookup Screen


#### Camera Information Screen
The Camera Information Screen displays version and some operating information about the camera.  The information on this screen is one thing I'm gonna ask for if you email me with issues :-)

tCam Information Screen

It can also be used to reset the camera to factory default values by tapping on the "Camera Information" title five times quickly.  A dialog box allows you to cancel.

tCam Factory Reset Confirmation

#### Firmware Update Confirmation
An OTA firmware update displays the following confirmation.  If confirmed then the camera shows a progress bar followed by a reboot when the new firmware has been successfully downloaded.

tCam Firmware Update Confirmation

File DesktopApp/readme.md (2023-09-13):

## tCam Desktop Application

This repository contains the companion desktop application for the tCam cameras.  It communicates with the cameras via a network connection using their json packet command set.  It provides functionality to control the cameras, download and display data from them and analyze the radiometric data.

* Get a current image.
* Stream images from a connected camera at various rates.
* Control remote picture and video recording and download images from the camera's local storage (tCam only).
* Save and load radiometric image files.
* Save and load radiometric video (stream) files.
* Export radiometric data as a common format image file.
* Export radiometric video files as mp4 movies (Mac only).
* Graph temperature at up to five points from a stream or video file.
* Update camera firmware (tCam-Mini requires FW 2.0 and beyond).
* Discover cameras on the local network (requires tCam-Mini FW 3.0 and beyond)

The application is developed using the [xojo](https://www.xojo.com) development environment.  64-bit binary images are provided for Mac OS X, Windows and x86 Linux systems.  A 32-bit binary image is provided for Raspbian or other ARM7HF Linux SBCs.  Download the zip file for your platform.  The application can be run directly from the unzipped directory by double clicking the application binary icon.

Note: Zip files for each application platform can be downloaded directly from my [website](http://danjuliodesigns.com/products/tcam_mini.html) as well if you don't want to clone this entire repository.

#### Version History
The latest version release notes are shown here.  Please see the ```release_notes.pdf``` file for notes from previous versions.

Version 3.2.0

1.	Min/Max Markers for radiometric cameras (may be included in graphs)
2. Export mp4 video [Mac platform only] from tmjsn files
3. Fixed bugs in export picture that would misplace markers for image size other than 320x240 pixels
4. Reformat export picture format to include marker temperatures
5. Improved rendering performance

#### Platform Caveats

1. The Mac version should now be signed and is delivered as a Universal installer package.  Let me know if you have any trouble.
2. You may need to make the Linux application file executable.
3. You may also have to authorize the application on the Windows platform since I don't yet package it for distribution in their online stores.
4. Windows users may need to install support for Bonjour (mDNS) using the ```bonjoursdksetup.exe``` installer from Apple found here.
5. Different Linux desktop systems render the toolbar differently and all toolbar items aren't visible since Linux renders the text next to the icon instead of beneath it.  You can make the window wider to expose some important controls like Stream that has sub-menus or you can use the pull-down menus at the top of the window.
6. Linux users may need to install ```libwebkit2gtk``` to view the built-in documentation.
7. The Raspberry Pi versions basically require a Pi 4 to display a stream at the full rate.  On slower Pi models the application may not be able to keep up and the controls may become unresponsive when streaming at the full ~9 FPS rate.

An advance apology - I develop on my Mac and do quick tests on Windows 7 and 10, and Ubuntu, Kubuntu and Raspbian.  Although Xojo provides pretty good cross-platform compatibility for OS X and Windows, sometimes there are issues with Linux.  If you find some other issue, please let me know and I'll try to fix it.

### Main Window
Main Window

Main window operation is described below.

### Preferences
Preferences Window

The preferences window is used to configure the application.  Preferences are stored on the computer and loaded each time the application starts.

* Camera IP Address - Set the camera's IP address.  Clicking the refresh button sets the computer's current network IP4 address with the lowest octet set to "1".  If the camera is acting as an AP then this address will be the camera address "192.168.4.1".  If the camera and computer are both connected to an external AP then replace the lowest octet with the address associated with the camera.
* Discover - Displays the Camera Discovery window which is used to display the IP addresses of cameras on the same network (tCam-Mini cameras must be running FW 3.0 and beyond).
* Manual Range - Allows setting a specific manual temperature range for the display of radiometric images.
* Display Units - Allows setting the unit display used throughout the main window.
* Stream Rate - Allows setting the requested stream rate from the camera when streaming is enabled (fastest possible rate down to one image every five minutes)
* Update Camera Clock - Causes the application to set the camera's built-in clock to the current computer time on each connection.  The clock is used to timestamp images.
* Scale Display using Bilinear interpolation - Uses an algorithm that results in a slightly smoother image as it is increased from the camera's native 160x120 pixel resolution.  De-selecting this uses a much faster algorithm that will work better on slower computers and when resizing the image at the cost of some smoothness.
* Export Resolution - Sets the size of an exported image (160x120 pixels to 640x480 pixels) and specifies if only the image or the image plus additional information is rendered to the exported file.
* Download Folder - Sets the default folder for downloaded/saved images.
* Automatically check for updates - Selecting this enables the program to check for an updated version every time it is launched.  It is always possible to check for an update using the ```Applications->Check for updates...``` menu item if this is de-elected.  No information is transmitted during the check.

### Connecting to an Ethernet Camera
The tCam-POE camera using its Ethernet interface has either a DHCP-served or statically assigned IPV4 address.  This address is entered into the application preference's Camera IP Address field.  A statically assigned address may be set using the Settings button as described below (Camera Settings Window).

### Connecting to a WiFi Camera
The tCam cameras operate in one of two WiFi modes.  By default they act as an Access Point (AP) and create their own WiFi network with the SSID "tCam-XXXX" or "tCam-Mini-XXXX" where XXXX are four hexadecimal digits.  This makes it easy to connect to a camera right away.  Once connected the camera may be reconfigured using the application to connect to an existing WiFi network, either getting a DHCP served IPV4 address from the network's router or with a statically assigned IPV4 address.  This makes it possible for the computer running the application to talk to both the camera and the internet at large.

#### Connecting to a camera as Access Point
Configure the computer to connect to the camera's SSID.  The camera always has a IPV4 address of "192.168.4.1" when it is acting as an Access Point so this number should be entered into the application preference's Camera IP Address field (this is the application's default value).  Press the Connect button after configuring or verifying the preference IP address field.

#### Configuring the camera to connect to another WiFi network
Once connected the application can be used to reconfigure the camera to connect to an existing WiFi network using the Settings button as described below (Camera Settings Window).  The camera may be configured to either get a DHCP served IPV4 address from the router or given a static IPV4 address on the network.

#### Connecting to a camera connected to another WiFi network
Connecting to a camera on an existing WiFi network requires the camera's IPV4 address to be entered into the application preference's Camera IP Address field before pressing Connect.  For cameras running firmware prior to version 3.0, it may be necessary to log into the WiFi router or use a utility program (for example Fing on Android or nmap on Linux) to obtain the camera's IPV4 address if it has been assigned automatically using DHCP.

#### Discovering Cameras
tCam-Mini cameras running version 3.0 firmware or later, and all tCam and tCam-POE cameras implement mDNS (bonjour) for discovery.  The Discover Cameras window displays all cameras on the local network.  Selecting a camera and clicking Apply sets the Camera IP Address with the IP Address of the selected camera.

Discovery Window

### Application Operation
The application is oriented around radiometric image files.  It always displays the last image it processed.  This may be a static image loaded from a file or taken by an attached camera.  It may also be a series of images from a video file or streamed from the camera.  Each image is displayed using a selected Palette to provide a false color image.  The 16-bit radiometric data is linearly scaled to 8-bits and the selected palette used to generate 24-bit RGB pixel colors.  When the camera is configured into AGC mode the 8-bit data from the camera is used directly with the selected palette.

Note that while the application is designed primarily for use with radiometric image files, it is also capable of displaying images taken when the camera's Lepton sensor has been configured into AGC mode.  In this case, since the data from the camera no longer contains radiometric information, several functions (such as radiometric markers or histogram analysis) are not available.

#### Camera Controls
Camera controls are available when the application is connected to a camera.  The main camera controls are displayed at the top of the main window.  These controls and additional controls are displayed under the ```Camera``` pull-down menu.

* Connect - Toggles the connection state with the camera.  The connection state is shown in the Connection Status area.  When first connected, and then periodically, the application requests the camera status and displays it in the Camera Status area.
* Settings - Requests the current Lepton configuration and WiFi setup from the camera and displays the settings window. 
* Get - Get a single image from the camera.
* Stream - Start (or Stop) the camera streaming images at the rate set in the Preferences Window.  The stream may optionally be stored to a video file.  Clicking the Stream button brings up a submenu.
	* Stream - Only display the stream.
	* Record - Select a video file to record the stream into and display the stream.
	* Stop - End a stream (close the video file if recording).
* Snap - Take a picture and store it in the camera's local storage (tCam only).  Equivalent to pressing the shutter button with the camera set to Image mode.
* Record - Start or stop the camera recording a stream in its local storage (tCam only).  Equivalent to pressing the shutter button with the camera set to Video mode.
* Download - Download a selected set of image or video files from the camera's local storage (tCam only).
* Power - Switch the camera off (tCam only).
* Check for new Firmware - Checks to see if a newer version of the firmware for the connected camera is available to download from ```danjuliodesigns.com```.
* Update Firmware - Initiate a FW update process with cameras that can support it.
* Camera Info - Display a pop-up (shown below) with information about the currently connected camera.

Camera Information Window

#### Camera Settings Window
The Camera Settings Window allows configuring the camera operation.  Items with the associated "Update Camera" checkbox set will be updated in the camera if Apply is pressed.

##### Configuration Tab

Camera Configuration Window

Configuration items affect the Lepton's operation.

* AGC Button - Selects between Radiometric operation or the Lepton's AGC mode which uses a built-in algorithm to improve visual image quality at the expense of outputting radiometric data.  When AGC is selected the output data is 8-bits/pixel designed to be displayed through the color palette with improved visual characteristics and is useful to see differences in temperature in an image.
* Gain Pulldown - Selects the Lepton's Gain mode.  High gain is useful for images with similar temperatures.  Low gain is useful for images with widely varying and high temperatures (for example when looking at fire).  Automatic gain mode allows the Lepton to switch from High to Low gain as necessary based on the image.
* Emissivity - Sets the Lepton's applied emissivity and is a value of 1-100%.  Should be set based on the characteristics of the materials being imaged.  Some useful materials are listed in the scroll-box.  Selecting one of them automatically updates the emissivity value.

##### WiFi / Network Tab

Camera Network Window

The WiFi / Network tab configures the camera network interface.

##### Ethernet Interface

For cameras using an Ethernet interface (tCam-POE configured to use Ethernet) the tab displays Network items.  Network items include the camera name and if a static IP should be set.

* Camera Name - Configure the name of the camera as displayed in the Discover Cameras Window.
* Camera Client Static Address - Selecting this checkbox and filling in the associated IPV4 address field allows configuring the camera with a static IPV4 address.  The address must be on the same network and should not be in a range the network's router might assign automatically using DHCP.  De-selecting the checkbox will enable the camera to request a DHCP served IPV4 address from the router.
* Netmask - The netmask to use when using a static IPV4 address.  Usually this will be "255.255.255.0".

##### WiFi Interface

For cameras using WiFi (tCam, tCam-Mini and tCam-POE configured to use WiFi) the tab displays WiFi items.  WiFi items include whether the camera is acting as an Access Point (AP) or connecting to an AP (Client mode), the associated SSID and password and if a static IP should be set (in Client mode only - the camera always has the IP address of 192.168.4.1 in AP mode).

* Camera is Access Point checkbox - Configure the camera's Wifi Mode as either Access Point (it creates a Wifi Network) or Client (it connects to another Wifi Network).
* SSID - The Wifi Network SSID.  This is the name of the WiFi Network the camera will create if it is in AP mode or the name of the WiFi Network it will attempt to connect too in Client mode.  The maximum length is 32 characters.
* Password - The Wifi Network WPA password.  This is the password that is necessary to connect to the camera's WiFi Network if it is in AP mode or the password it will use to connect the another WiFi Network in Client mode.  Leave the field blank if there is no password, otherwise the password must be between 8 - 32 characters long.
* Camera Client Static Address - Selecting this checkbox and filling in the associated IPV4 address field allows configuring the camera with a static IPV4 address.  This only applies to the camera when it is operating in Client mode.  The address must be on the client network and should not be in a range the network's router might assign automatically using DHCP.  De-selecting the checkbox will enable the camera to request a DHCP served IPV4 address from the router.
* Netmask - The netmask to use when using a static IPV4 address.  Usually this will be "255.255.255.0".

The application will be disconnected after changes to the Wifi / Network configuration are made.  The application Camera IP Address field preference may need to be updated to reconnect.

#### Download Window
Selecting ```Download``` queries the connected camera for all files stored in its local storage.  The files and their parent directories are displayed in the download window.

Download Window

The window allows selecting either entire folders for download or individual files within a folder for download to the destination parent folder.  Click the associated Download checkbox next to either the folder name or file name and click ```Download``` to start downloading files.  Selecting the ```Delete after download``` checkbox will delete the file or folder on the camera after it is downloaded.

#### Range/Palette Display
The Range/Palette display shows the currently selected palette with a marker showing the spotmeter temperature location within the range of temperatures.  It also displays the minimum and maximum temperatures used to scale the image when the Lepton is operating in Radiometric output mode.  These temperatures are simply the minimum and maximum temperature in the image's radiometric data when Auto Range Selection is enabled.  They are the manual temperature range (set by the user in the Preferences window or automatically when the AR button is pressed) when Manual Range Selection is enabled.

#### Image Management
Image Management controls are available based on the type of operation occurring or image being displayed.

* Browse - Allows opening a directory (Folder) of image and video files and displays forward and backward buttons in the Current Activity area.
* Open - Allows opening a single image or video file.
* Save - Allows saving the current image in a file.
* Export - Allows saving the current image as a jpeg, png or tiff image, with or without additional metadata rendered to the image.  On the Mac platform an additional option of mp4 video is available when the current activity is displaying a tmjsn video file.  Note that exporting a video can take some time.
* Graph - Allows graphing either a stream or video file.  At least one of the spotmeter or four radiometric markers must be enabled to graph.

An example of a 320x240 pixel exported image (with metadata) is shown below.  The spotmeter temperature is displayed in the center.  The enabled Marker 1 temperature is displayed to the left.

Exported Image

#### Image Palette
A pull-down menu allowing selection between a set of false color maps.  Different palettes are useful in visualizing various attributes of an image.  For example the ```Rainbow HC``` palette, with its rapidly changing colors is good for showing temperature gradients while the ```Ironblack``` palette is good for emphasizing only the hotter areas in a scene.

#### Spot/Marker Temps
Displays the current enabled SpotMeter ("s") or Radiometric Marker temperatures ("m1" - "m4").

The SpotMeter temperature is taken from the telemetry data in the last image.  It is based on a 4-pixel average.

The Radiometric Marker temperatures are computed based on the Radiometric data in the last image.  They are also computed using a 4-pixel average.

#### Spotmeter Select
Clicking the Spotmeter Select button enables setting the spot meter position in the Lepton by clicking on a location in the image.  Note that changing the spotmeter position causes a command to be sent to the camera setting the location.  However the spotmeter display in the image and the temperature displayed above are not changed until a new image is loaded from the camera.

#### Min/Max Enable
Clicking the Min/Max Enable button displays the current minimum and maximum temperature points as markers on the image.  The minimum temperature is indicated by a lower-case 'm' character.  The maximum temperature is indicated by a upper-case 'M' character. 

#### Radiometric Marker Selects
The Radiometric Markers are only enabled if the displayed image contains radiometric data (they are disabled if the image was generated by the Lepton while AGC is enabled).

Clicking on a Radiometric Marker Select button enables setting the associated marker position in the displayed image.  The marker is displayed immediately since it is calculating the temperature at the location based on the existing image radiometric data.

Double clicking a Radiometric Marker Select button disables the marker if it is currently displayed.

#### Flat Field Correction
Clicking on the FFC button causes the connected camera to initiate a Lepton flat field correction.

#### Current Activity
The Current Activity area displays the source of the last loaded image and its timestamp.  It also displays a pair of forward and backward buttons when browsing a folder.

Browse Controls

#### Video Playback
The Video Playback area displays controls and timestamp information when a video file has been opened.  It also displays the frames-per-second of a playing video or stream.

A play/pause button, denoted by a single right-facing triangle, controls video playback.  A position slider allows setting the video position.

Video files with a frame-rate of below 1 frame-per-second cause a second fast forward button, denoted by a double right-facing triangle, to appear.  Pressing this button plays the video at a fixed rate of one frame-per-second instead of the video's normal rate (which could be as slow as one frame every five minutes!).

Video Fast Forward

#### Connection Status
Connection Status shows the current connection state, either Connected or Disconnected.  While connected the application periodically sends a request for status.  If the camera does not respond with a status response the application will assume the camera has been disconnected.

#### Camera Status
Information from the camera status responses are displayed in the Camera Status area including the camera name, and optionally battery level and charge status for tCam.

#### Auto/Manual Range Selection
The Auto/Manual Range Selection button toggles between Automatic and Manual Range modes when the Lepton is configured in Radiometric mode (the button is disabled if AGC is enabled).

In Automatic Range mode the minimum and maximum temperatures present in each image are used to linearly scale the radiometric data.

Manual Range mode uses a preset minimum and maximum temperature to scale the radiometric data.  This mode is useful to eliminate radical image changes while streaming or playing back a video and the scene dynamic range changes from image to image resulting in very different false color mappings.  Typically a manual range is set to be slightly greater than the largest expected scene range.

The Range mode can also be controlled via Preferences.

When the Auto/Manual Range Selection button is used to enter Manual mode, the minimum and maximum temperatures are set by rounding the existing scene minimum temperature down to next whole number value and the existing scene maximum temperature up to the next whole number value.

#### Lepton Configuration
Displays the Lepton's gain and emissivity settings for the current image.

The gain setting is either HIGH or LOW.  When the camera's Lepton is allowed to automatically select the gain setting (via the Camera Settings) then it will use a High gain setting for scenes with a low dynamic range (-10°C to 140°C) for improved accuracy and resolution.  It will switch to Low gain setting for scenes with a higher dynamic range.

The emissivity setting is a percent, from 1-100, that the Lepton uses to improve accuracy when computing the radiometric temperature of each pixel.  It should be set to match the emissivity of objects in the scene.

#### Histogram Analysis
The Histogram Analysis area displays a histogram showing the relative number of pixels for each of the 256 values (bins) that result from the linear transformation of the radiometric data or are direct from the camera when AGC is enabled.

A pair of markers can be dragged onto the histogram.  The markers display the temperature of the bin they are over when the image contains radiometric data.

Additional information is displayed about the region between the two markers when both are dragged onto the display.

* Population - Percent (and number) of pixels out of the Lepton's 19200 total pixels between the markers.
* @minP (radiometric data only) - The temperature of the bin with the least number of pixels in the region between the two markers.
* @maxP (radiometric data only) - The temperature of the bin with the highest number of pixels in the region between the two markers.
* Mean (radiometric data only) - The mean temperature in the region between the two markers.
* Average (radiometric data only) - The average temperature in the region between the two markers.

### Graphing
Temperature data from a streaming session or video file may be graphed over time for further analysis.  If enabled the spotmeter temperature is included in the graph.  Any enabled Radiometric Markers (radiometric data only) are also included allowing a total of up to five locations in the image to be plotted.

Graph Window Identified

To graph from a stream

1. Start streaming at the desire rate.
2. Select Spot and Radiometric Marker positions.
3. Click Graph to start plotting data.
4. Stop streaming to complete the graph.

To graph from a video file

1. Open the video file.
2. Select any additional Radiometric Marker positions (the spotmeter location is set in the file's image data).
3. Click Graph to plot the data.

Multiple graph windows may be opened.  The data may be saved in a text file or an image of the graph exported once the graph is complete.

#### Save
Saves the temperature data in a text file comprised of one or more temperature values following a timestamp, separated by spaces with one set per line.

	<timestamp> <spot> <m1> <m2> <m3> <m4> <min> <max> <CR><LF>

* \<timestamp\> is the number of milliseconds from the start of Unix Epoch time (Thursday, January 1, 1970 12:00:00 AM GMT).
* \<spot\> is the spotmeter temperature (°C) if available or the character "-" if not available.
* \<m1\> - \<m4\> are the Radiometric Marker temperatures (°C) if available or the character "-" if not available.
* \<min\>, \<max\> are the Minimum and Maximum temperatures (°C) if available or the characters "- -" if not available.
* \<CR\>\<LR\> are the Carriage Return and Linefeed characters.

#### Export
Saves the contents of the graph window as a jpg, png or tiff formatted file.

Selecting "Copy" from the Graph Window Edit pull-down menu copies the contents of the graph window to the computer's clipboard.

#### Complete
The graph is marked Complete when all data has been plotted.  This occurs when streaming is stopped or after all video file data is processed.  No further data will be added to the graph.

#### Graph Controls
Graph Controls control how the data is displayed.

* Units Button - Toggles unit display between °C and °F.
* Baseline - Allows selecting one of the traces to be used as a Baseline temperature when displaying sample data (see below).
* Temperature - Controls the zoom factor of the temperature axis.  The graph displays a total temperature range of 500°C (900°F).  The temperature zoom factor allows display of temperature data from 0.5°C (1°F) to 30°C (50°F) per horizontal rule line.
* Timescale - Controls the zoom factor of the time axis.  The time zoom factor allows display of time data from 1 second to 30 minutes per vertical rule line.

The position of the data graphed is controlled by the horizontal and vertical sliders.  It may also be controlled, when the cursor is over the graph, by horizontal and vertical mouse controls.

#### Viewing Sample Data
Positioning the cursor over the graph displays the sample points on each trace.  Positioning the cursor over a sample point displays the sample data in the Sample Information area.  Sample data includes the sample source, its time relative to the start of the graph, the sample's original timestamp and its temperature.

Sample Information

#### Using a Baseline
Selecting a baseline allows comparing temperatures on traces with the temperature on the baseline trace.  This is often useful for comparing a temperature of something with the temperature of an object with a precisely known temperature for improved accuracy.

In the image below the temperature of a point on the M2 trace is compared with the temperature of the point on the Spotmeter trace.

Sample Information with Baseline

### Application Menu Items
All functions available through controls on the Main Window are also available from the pull-down menus at the top of the window (or OS X main menu bar).

The ```Application``` menu item contains two items not accessible elsewhere that provide additional functionality.

1. CCI Access - Provides direct access to the Lepton Command and Control interface.
2. Log Window - Displays a log of program status and transmitted and received packets.
3. Check for updates - Checks to see if a newer version of the application is available to download from ```danjuliodesigns.com```.

#### CCI Access
The CCI Access window allows direct access to the Lepton's I2C interface as described in the Flir Lepton Software Interface Description Document.  It allows access to the Lepton CCI registers and Block Data Buffer 0 for data lengths greater than 16 DWORDs.

CCI Access

You should be familiar with the Lepton CCI Interface.  It is possible to misconfigure and/or crash the Lepton or tCam camera using this interface.

Operation is straight-forward.  The Command, Length and Data fields correspond directly with the associated Lepton registers.  The first sixteen Data values are associated with Data 0 - 15 for Length's of 16 DWORDs or less.  The up to 512 Data values are associated with Block Data Buffer 0 for Length's of 16 DWORDs or more.

To read the Lepton configure the Command and Length and click ```READ```.  The Data fields are updated.  The Last Status field is updated with the STATUS register value after the read.

To write the Lepton configure the Command, Length and Data values and click ```WRITE```.  The Last Status field is updated with the STATUS register value after the write.

To run a command sequence configure the Command value and click ```RUN```.  The Last Status field is updated with the STATUS register value after the run command.

The ```LOAD``` and ```SAVE``` buttons save or load values to or from a simple text file with one value per line.  The file layout is as follows.

```
	Command
	Length
	Data 0
	...
	Data <Length - 1>
```

#### Log Window
The Log Window displays connection/disconnection status messages and logs the transmitted and received json packets to the camera.  It can be useful to understand the packet contents.

Log Window

It provides a simple set of controls.

* Enable - Enable or disable logging.
* Shorten Json - Shortens long json strings (helpful when displaying image and FW update packets.
* Filter Status - Filters out the ```get_status``` and ```status``` response packets which are sent periodically while the application is connected to the camera to verify connectivity.
* Auto Scroll - Configures the window to automatically scroll when text reaches the bottom.
* Clear - Clears all text.

#### Check for Updates

Updates for either the application or firmware are displayed in the Update Available window.  It displays a description of the changes in the new version. Clicking ```Download``` will download a zip file with the new application (for the current platform) or firmware (for the connected camera).

Update Available Window

### Help Menu Items
The ```Help``` menu items contains the following selections.

1. About tcam - Displays version and copyright information.  Click in the window to dismiss.
2. Documentation - Displays documentation like this readme file in a window.

### File Formats
The application supports two native file formats.

* Image files (ending with the .tjsn suffix) - An image file is simply the json text from the camera's image json packet.
* Movie (video) files (ending with the .tmjsn suffix) - A movie file consists of multiple image json text strings, one for each camera image json packet followed by a special "video_info" json text string.  Each json text string is separated by a character with the value 0x03 (the same as the END\_OF\_JSON delimiter used when an image is sent over a network interface).

The "video_info" json text string contains the starting and ending timestamps and number of frames.  It is used by the application to validate the file and also determine if it should show the "Fast Forward" control for videos with long delays between frames.

```
{
	"video_info": {
		"end_date": "2/2/21",
		"end_time": "21:53:10.8",
		"num_frames" 143,
		"start_date": "2/2/21",
		"start_time": "21:52:46.8",
		"version": 1
	}
}
```

Example files are found in the "sample_files" subdirectory here.

### Firmware Updates
The ```Update Firmware``` menu selection is available for cameras that support over-the-air FW updates.  Selecting it opens a file selection dialog box.  Open a FW binary file appropriate for the camera.

* tCam-Mini / tCam-POE - Open a ```tCamMini.bin``` binary file.
* tCam - Open a ```tCam.bin``` binary file.

An error message is displayed if the selected file is not the appropriate binary file for the connected camera.  A warning message is displayed if the selected file has a version that is equal to or less than the version the camera is currently running.

Once a binary file has been loaded the camera will indicate that a firmware update has been requested.  The user must perform an action on the camera to initiate the update.

* tCam-Mini / tCam-POE - LED alternating green/red blinking pattern.  Press the Wifi Reset button to initiate the update.
* tCam - Pop-up message appears on the LCD.  Select ```Confirm``` to initiate the update.

A progress bar is displayed in a dialogue box during the firmware update.  The camera will reboot once the firmware update is completed successfully.  An error message is displayed if the update is unsuccessful.

### A Note about AGC
This application is designed primarily for use with the Camera's Lepton outputting radiometric data because that data allow analysis of scene temperature, even from a stored image or video file.  A linear transformation is performed on the data to generate a visual image.  This image may not be as good, visually, as an image generated when the Lepton AGC is enabled so this mode is also supported for the cases where the user prefers a better image at the expense of being able to access the temperature of each pixel.  The Spotmeter is still functional in AGC mode so the temperature at one point can still be displayed.

Read the Flir Lepton 3.5 datasheet for a better description of AGC mode (and why Flir is clearly so proud of it...).

### A Note about the Lepton 3.0
Since the Lepton 3.0 does not support Radiometric data output the application suppresses all temperature related controls and displays.

### Fin

If you've read all the way down here you must be somewhat serious about this program that I've put a lot of work into.  It represents the functionality I find useful in a thermal imaging camera and I hope you do too.  Try it, let me know what you think and what you think I could do better.  I might be able to add your suggestion.

I am also available for hire to modify the application for custom applications.

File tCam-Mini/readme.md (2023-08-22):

## tCam-Mini
tCam-Mini was created using code from the tCam project and ended up being finished first.  It is a simple device, hardware-wise, consisting of an ESP32 WROVER module, USB UART for programming and debug, Lepton 3.0, 3.1R or 3.5 and supporting voltage regulators and oscillator.

tCam-Mini Front and Back

(image courtesy of Group Gets)

Revision 4 of the PCB, along with FW 2.0 and beyond, introduces a new hardware expansion port that can be used by an external micro-controller or single-board computer to communicate with tCam-Mini directly instead of using WiFi.  It also has an I2C expansion port that is currently unused, a USB-C connector and surface-mount LED.

### Firmware
The "Firmware" directory contains a V4.4.4 Espressif ESP32 IDF project for tCam-Mini. You should be able to build and load it into a camera using the IDF commands.  There are also a set of precompiled binaries in the "precompiled" sub-directory.  You can use the Espressif tool and instructions found in the "programming" directory in parallel to this one to load those into a camera without having to build the project.  You can also use the tCam Family Serial Updater tool to load current files from my website.

The precompiled firmware and Windows-based programming application can be downloaded directly from my [website](http://danjuliodesigns.com/products/tcam_mini.html) as well if you don't want to clone this entire repository.  The tCam Family Serial Updater tool can also be [downloaded](https://danjuliodesigns.com/products/tcam.html).

Cameras running FW 2.0 and beyond can also use the over-the-air update capability in the Desktop application to load new firmware files.

This firmware also provides support for an ethernet interface using the built-in ESP32 MAC and an external PHY chip implemented with the tCam-POE PCB.  A GPIO pin is pulled low to indicate the firmware is running on the tCam-POE PCB.

### Hardware
The "Hardware" directory contains PCB and stencil Gerber files, a BOM and a schematic PDF.  These can be used to build a tCam-Mini on the PCB I designed.  Of course you can also buy a pre-assembled unit from [Group Gets](https://store.groupgets.com/products/tcam-mini) with or without the Lepton.  See below for instructions on building one from commonly available development boards.

Note: My interests are in radiometric thermography so I have focused primarily on the Lepton 3.5.  The Lepton 3.0 is supported starting with FW 2.0.  It should be possible for someone to modify my firmware source to work with the Lepton 2 and 2.5 models by modifying the task that reads the lepton (probably easiest to modify the code that reads the data and then just pixel-double it before handing it off to other tasks).  I will be happy to include a link to anyone else's clone of my code that supports these older Leptons.

### Enclosures
Three simple enclosure designs in included in this repository, One designed to be cut on a laser cutter and two designed to be 3D printed.

Github user [zharijs](https://github.com/zharijs) created a set of fantastic 3D printed enclosure designs, with and without GoPro™ mounts, that you can find in his [repo](https://github.com/zharijs/Enclosures/tree/main/tCam%20enclosure). He helpfully includes a BOM for extra hardware you'll need too.  Honestly, his enclosures are better than mine!

Zharijs Enclosure Body

### Operation
tCam-Mini is a command-based device.  It is designed for software running on another device to control it and receive responses and image data from it.  The software communicates with tCam-Mini via one of two ways depending on the polarity of the Mode input at boot.

1. Mode bit left disconnected (pulled high) configures communication via WiFi using a socket interface with commands, responses and images encoded as json packets.  Data is not encrypted so appropriate care should be taken.
2. Mode bit low (grounded) configures communication via the Hardware Interface using a serial interface and a slave SPI interface.  Commands and responses are sent as json packets over the serial interface.  A new "image_ready" packet indicates that the controller can read an image from the SPI interface.

The command interface is described in the firmware directory.

#### USB Port
The USB Port provides a USB Serial interface supporting automatic ESP32 reset and boot-mode entry for programming.  It is also used for serial logging output by the ESP32 firmware (115,200 baud).

#### Status Indicator
A dual-color (red/green) LED is used to communicate status.  Combinations of color and blinking patterns communicate various information.

| Status Indicator | Meaning |
| --- | --- |
| Off or Dim | Firmware did not start |
| Solid Red | Firmware is running: initializing and configuring the Lepton and WiFi (when configured to use WiFi) |
| Blinking Yellow | WiFi AP Mode : No client connected to camera's WiFi |
|  | WiFi Client Mode : Not connected to an AP |
| Solid Yellow | WiFi AP Mode : Client connected to camera's WiFi |
|  | WiFi Client Mode : Connected to an AP |
| Solid Green | Wifi Mode : WiFi is connected and external software has connected via the socket interface |
|  | Hardware Interface Mode : Camera is ready for operation |
| Fast Blink Yellow | WiFi Reset in progress |
| Alternating Red/Green | Over-the-air FW update has been requested.  Press the button to initiate the update |
| Blinking Green | FW update in process (blinking my occur at irregular intervals as the Flash memory is written) |
| Series of Red Blinks | A fault has been detected.  The number of blinks indicate the fault type (see table below) |

| Fault Blinks | Meaning |
| --- | --- |
| 1 blink | ESP32 I2C or SPI peripheral initialization failed |
| 2 blinks | ESP32 Non-volatile storage or WiFi initialization failed |
| 3 blinks | ESP32 static memory buffer allocation failed (potential PSRAM issue) |
| 4 blinks | Lepton CCI communication failed (I2C interface) |
| 5 blinks | Lepton VoSPI communication failed (SPI interface) |
| 6 blinks | Internal network error occurred |
| 7 blinks | Lepton VoSPI synchronization cannot be achieved |
| 8 blinks | Over-the-air FW Update failed |

Additional start-up and fault information is available from the USB Serial interface.

#### WiFi
tCam-Mini can act as either an Access Point (creating its own WiFi network) or a client (connecting to an existing WiFi network).  WiFi is enabled when the Mode input is high (left floating) when tCam-Mini boots and operates in the 2.4 GHz band.  The camera acts as an Access Point (AP) by default.  It selects an SSID based on a unique MAC ID in the ESP32 with the form "tCam-Mini-HHHH" where "HHHH" are the last four hexadecimal digits of the MAC ID.  There is no password by default.  When acting as an Access Point, each tCam-Mini always has the same default IPV4 address (192.168.4.1).

It can be reconfigured via a command (for example, from the desktop application) to act as a WiFi Client (STAtion mode) and connect to an existing WiFi network.  When configured as a WiFi Client, it can either get a DHCP served address from the network's router or it can also be reconfigured to have a fixed (static) IPV4 address.  Using a static address makes it easier to connect to tCam-Mini because you don't have to find out what DHCP address the router gave it.

Currently only one device can connect to the camera at a time.

Please see the set of instructions in the DesktopApp folder in this repository for connecting to tCam-Mini in either mode.

#### WiFi Reset Button
Pressing and holding the WiFi Reset Button for more than five seconds resets the WiFi interface back to the default AP mode.  The status indicator will blink a pattern indicating the reset has occurred (see below).

Pressing the button quickly when an OTA FW update has been requested (LED alternating red/green) by the Desktop application initiates the update process.

#### Hardware Interface
The hardware interface is enabled when the Mode input is low (grounded) when tCam-Mini boots.

tCam-Mini Hardware Interface

The serial port (running at 230,400 baud) is used to send and receive commands and responses as described below.  Instead of sending an "image" response over the relatively slow serial port, the firmware sends an "image_ready" response to notify software running on the external system that it can read the image from the slave SPI port using a master SPI peripheral.

The slave SPI port is partially handled by a driver running on the ESP32.  For this reason the highest supported clock rate is 8 MHz.  Too fast and the ESP32 slave SPI driver can't keep up.  I found success running the interface at 7 MHz.

#### mDNS Discovery
The cameras advertise themselves on the local network using mDNS (Bonjour) starting with firmware revision 3.0 to make discovering their IPV4 addresses easier.

* Service Type: "\_tcam-socket._tcp."
* Host/Instance Name: Camera Name (e.g. "tCam-Mini-87E9")
* TXT Records:
	1. "model": Camera model (e.g. "tCam", "tCam-Mini", "tCam-POE")
	2. "interface": Communication interface (e.g. "Ethernet", "WiFi")
	3. "version": Firmware version (e.g. "3.0")

### Previous version
tCam-Mini Front and Back

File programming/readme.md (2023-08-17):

# tCam/tCamMini Firmware Serial Upload
There are four ways to load firmware into tCam.

1. Using the Espressif build process after compiling the firmware (or by using the Espressif ```idf.py``` command with the precompiled binaries).
2. Using a windows-only download tool from Espressif to load the pre-compiled firmware from this repository.
3. Using the tCam Family Serial Updater tool that runs on Linux, Mac and Windows and downloads the current firmware from my website.
4. Using the Desktop application and the over-the-air (OTA) capability in tCam-Mini (FW Revision 2.0 and beyond) and all tCam FW revisions.

Options 2 and 3 are discussed here.

## Using the tCam Family Serial Updater tool

### Install the tool
Download the appropriate zip file for your platform from my [website](http://danjuliodesigns.com/products/tcam.html).  Look for the section called tCam Family Serial Updater.  Unzip it in a known location.

### Start the tool

1. Linux : Run the ```tcam_serial_programmer``` executable file.  It is possible you may need to give it executable permissions (```chmod +x tcam_serial_programmer```).
2. OS X : Double click the icon.  Although the file is signed, OS X security might complain and you'll have to go to the Security & Privacy Preference panel to allow it to run.
3. Windows : Double click the file ```tcam_serial_programmer.exe``` in the folder that is created when by the unzipping process.  Windows security may ask you if you want to run it.

Your computer will need to have internet access for the program to work.

### Programming
Plug the board (gCore, tCam-Mini, tCam-POE) into a USB port on your computer.  gCore needs to be powered on by pressing the power button.

Your computer should enumerate a serial port associated with the board.  You'll need to find this and select it from the pull-down on the utility.  On Linux this might be "/dev/ttyUSB0".  On OS X it might be something like "/dev/tty.usbserial-XXXXX" where "XXXXX" is a unique number for the port.  And on Windows it will be a "COM" port (use the Device Manager if necessary to find the COM port associated with a Silicon Labs CP2102N USB UART chip).

Press "Program".  You should see the program executing the steps shown below.  The entire process should require less than a minute.  The board will reboot and should be running the new firmware after the programming is complete.

tCam Family Serial Updater tool

### Note about serial device driver
You may need to install the Silicon Labs USB Serial device driver on your computer if, after plugging in and turning on gCore, you don't see its associated serial port.  You should be able to find the driver for the CP210X at the Silicon Labs website ([here](https://www.silabs.com/developers/usb-to-uart-bridge-vcp-drivers?tab=downloads) at the time of this comment).

## Using the Espressif download tool
This option requires a Microsoft Windows computer.

### Install the tool
Download the `flash_download_tools_v3.9.3.zip` file to a Windows computer.  Unzip it in a known location.  It will unzip a directory named `flash_download_tools_v3.9.3`.  You will execute the ```flash_download_tools_v3.9.3``` binary from within that directory.

### Download firmware files
The firmware is comprised of four binary files which are found in the specific camera firmware/precompiled directories.

tCam files:

```
	firmware/precompiled/bootloader.bin
	firmware/precompiled/ota_data_initial.bin
	firmware/precompiled/tCam.bin
	firmware/precompiled/partition-table.bin
```

tCam-Mini files:

```
	firmware/precompiled/bootloader.bin
	firmware/precompiled/ota_data_initial.bin
	firmware/precompiled/tCamMini.bin
	firmware/precompiled/partition-table.bin
```

Download the four binary files from this repository to a known location.  All are required by the Espressif download tool and are loaded at the following locations in flash memory.

| File | Location |
| --- | --- |
| bootloader.bin | 0x1000 |
| partition-table.bin | 0x8000 |
| ota\_data_initial.bin | 0xd000 |
| tCam.bin / tCamMini.bin | 0x10000 |

### Connect Camera
Connect the camera to the Windows Computer to allow it to load a device driver for the camera's Silicon Labs USB-Serial chip.  tCam must be switched on for the USB-Serial chip to be visible.  After a few minutes the computer should load a driver and associate a COM port with the camera.  Make a note of this port.  You can find it in the Windows Device Manager.

### Start the tool
Double-click the ```flash_download_tools_v3.9.3``` binary from within the installation directory.

A shell window will appear and then after a few seconds a selection window will appear.

Espressif Tool Selection

Click the `ESP32 Download Tool` button.  The ESP32 Download Tool program runs and displays a new window.

#### Programmer Setup

Espressif ESP32 Download Tool

1. Load the four firmware files from the location you stored them by clicking on the `...` buttons as shown above under the `SPIDownload` tab.  Select the appropriate tCam or tCamMini file depending on your camera (tCam shown in the image above).
2. Set the location in ESP32 memory for each file as shown above by clicking in the text fields to the right of each filename.
3. Configure the programming parameters in the `SpiFlashConfig` area.  Select SPI SPEED: 40 MHz, SPI MODE: DIO.
4. Select the COM port associated with the camera.
5. Set a fast baud rate of 921600 baud to reduce programming time.

#### Programming

1. Make sure the camera is on (tCam-Mini is on whenever connected to USB).  It will boot up but this does not matter (the programming software will reset it).
2. Press `START` to initiate programming.  A green progress bar will progress along the bottom of the window.  Programming should take 15-20 seconds.  The program will display `FINISH` upon a successful programming.
3. Reboot the camera.  For tCam turn the camera off by holding the power button for more than five seconds and then turn it back on by pressing the power button again.  For tCam-Mini, disconnect the camera and then reconnect it.  The camera should boot into the new firmware.

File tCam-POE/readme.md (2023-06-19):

## tCam-POE
tCam-POE was created by extending the tCam-Mini base code to support an ethernet connection using the ESP32 ethernet interface and an external PHY chip.  It is essentially a tCam-Mini extended with the PHY chip, ethernet magnetics and connector, and support for a common footprint IEEE802.3af POE 5V converter module.

tCam-POE with two different POE modules

### Firmware
tCam-POE runs the same firmware as tCam-Mini starting with the version 3.0 release. The firmware identifies the type of hardware platform it is running on by detecting a GPIO pin pulled low on the tCam-POE PCB.  The pin is pulled high by an ESP32 internal pull-up on the tCam-Mini boards.

Please see the tCam-Mini Firmware section for a full description of the firmware functionality and command set.

### Hardware
The "Hardware" directory contains PCB and stencil Gerber files, a BOM and a schematic PDF.  These can be used to build a tCam-POE on the PCB I designed.  It is possible to build this camera using the Espressif ESP32 POE development board and a Lepton breakout board.  See the firmware ```system_config.h``` file for the GPIO assignments to use when connecting the breakout board and configuring the camera. 

### Operation
tCam-Mini is a command-based device.  It is designed for software running on another device to control it and receive responses and image data from it.  The software communicates with tCam-Mini via one of two ways determined by the position of switch SW1 at power on (as the ESP32 boots).

1. ETH position enables the ethernet interface.
2. WIFI position enables the Wifi interface.

The command interface is described in the tCam-Mini firmware directory.

#### Ethernet Port
The ethernet port support an IEEE 803.2 10/100 Mbps ethernet interface.  An optional IEEE802.3af compliant isolated DC-DC converter may be installed enabling power-over-ethernet functionality. Without the DC-DC converter, the board must be powered via the USB port.

#### USB Port
The USB C Port provides a USB Serial interface supporting automatic ESP32 reset and boot-mode entry for programming.  It is also used for serial logging output by the ESP32 firmware (115,200 baud).

#### Status Indicator
A dual-color (red/green) LED is used to communicate status.  Combinations of color and blinking patterns communicate various information.

| Status Indicator | Meaning |
| --- | --- |
| Off or Dim | Firmware did not start |
| Solid Red | Firmware is running: initializing and configuring the Lepton and Ethernet or WiFi interfaces |
| Blinking Yellow | Ethernet Mode : No ethernet network detected |
|  | WiFi AP Mode : No client connected to camera's WiFi |
|  | WiFi Client Mode : Not connected to an AP |
| Solid Yellow | Ethernet Mode : Ethernet is connected and the camera has an IP address |
|  | WiFi AP Mode : Client connected to camera's WiFi |
|  | WiFi Client Mode : Connected to an AP |
| Solid Green | Ethernet Mode : Ethernet is connected and external software has connected via the socket interface |
|  | Wifi Mode : WiFi is connected and external software has connected via the socket interface |
| Fast Blink Yellow | Network Reset in progress |
| Alternating Red/Green | Over-the-air FW update has been requested.  Press the button to initiate the update |
| Blinking Green | FW update in process (blinking my occur at irregular intervals as the Flash memory is written) |
| Series of Red Blinks | A fault has been detected.  The number of blinks indicate the fault type (see table below) |

| Fault Blinks | Meaning |
| --- | --- |
| 1 blink | ESP32 I2C or SPI peripheral initialization failed |
| 2 blinks | ESP32 Non-volatile storage or Network initialization failed |
| 3 blinks | ESP32 static memory buffer allocation failed (potential PSRAM issue) |
| 4 blinks | Lepton CCI communication failed (I2C interface) |
| 5 blinks | Lepton VoSPI communication failed (SPI interface) |
| 6 blinks | Internal network error occurred |
| 7 blinks | Lepton VoSPI synchronization cannot be achieved |
| 8 blinks | Over-the-air FW Update failed |

Additional start-up and fault information is available from the USB Serial interface.

#### Ethernet
tCam-POE can obtain a DHCP served address from a router on the network or may be configured with a static IP address.

#### WiFi
tCam-POE can act as either an Access Point (creating its own WiFi network) or a client (connecting to an existing WiFi network).  It operates in the 2.4 GHz band. The camera acts as an Access Point (AP) by default.  It selects an SSID based on a unique MAC ID in the ESP32 with the form "tCam-Mini-HHHH" where "HHHH" are the last four hexadecimal digits of the MAC ID.  There is no password by default.  When acting as an Access Point, each tCam-POE always has the same default IPV4 address (192.168.4.1).

It can be reconfigured via a command (for example, from the desktop application) to act as a WiFi Client (STAtion mode) and connect to an existing WiFi network.  When configured as a WiFi Client, it can either get a DHCP served address from the network's router or it can also be reconfigured to have a fixed (static) IPV4 address.  Using a static address makes it easier to connect to tCam-POE because you don't have to find out what DHCP address the router gave it.

Currently only one device can connect to the camera at a time.

#### Network Reset Button
Pressing and holding the Network Reset Button for more than five seconds resets the network interface back to the default mode.  For ethernet mode this means the camera will request a DHCP served address.  For Wifi mode this means the camera will act as Access Point.  The status indicator will blink a pattern indicating the reset has occurred (see below).

Pressing the button quickly when an OTA FW update has been requested (LED alternating red/green) by the Desktop application initiates the update process.

#### mDNS Discovery
The cameras advertise themselves on the local network using mDNS (Bonjour) starting with firmware revision 3.0 to make discovering their IPV4 addresses easier.

* Service Type: "\_tcam-socket._tcp."
* Host/Instance Name: Camera Name (e.g. "tCam-Mini-87E9")
* TXT Records:
	1. "model": Camera model (e.g. "tCam", "tCam-Mini", "tCam-POE")
	2. "interface": Communication interface (e.g. "Ethernet", "WiFi")
	3. "version": Firmware version (e.g. "3.0")

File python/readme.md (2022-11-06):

## tCam-Mini Python Driver
Todd LaWall (bitreaper) wrote a python 3 driver to allow access to tCam and tCam-Mini from python programs.  The driver supports accessing tCam and tCam-Mini via the network socket interface and also supports accessing tCam-Mini via the hardware Slave Interface on a Raspberry Pi.

### tcam.py
The ```tcam.py``` file contains an object ```TCam``` used to connect to and communicate with a camera.  It manages the network socket or direct hardware connection and provides an API for sending commands to the camera and for receiving responses back from the camera.  It uses three queues to handle the asynchronous nature of the interface.  A command queue is used for outgoing commands to the camera.  Responses from the camera are pushed into two incoming queues.  Image responses are stored in a special image queue.  All other responses are stored in a response queue.  The API hides queue operation.  API operations are single threaded and do not return until a response is returned or a timeout expires.  All response packets are presented as a python dictionary built from the json response string.

### ioctl\_numbers.py
The ```ioctl_numbers.py``` includes helpers for use when communicating with tCam-Mini via the hardware interface.  It must be included with ```tcamp.py```.

#### Network Usage
Include the TCam object from ```tcam.py``` file in your program.

	from tcam import TCam

Create a reference.

	cam = TCam()

Open a connection to the camera.

	cam.connect(<ip_address>)

where ```<ip_address>``` is the camera's IP address as a string.  The connect method returns a response indicating of the connection was successful or not.

	{"status": "timeout"}
	{"status": "connected"}

#### Hardware Interface Usage
See below for a diagram showing how to connect the tCam-Mini hardware Slave Interface to the Raspberry Pi default serial and SPI ports.

Use the Raspberry Pi Configuration tool to enable the serial interface (make sure the console on that port is disabled) and the SPI port.  Increase the maximum SPI transfer the Pi can perform by editing the ```/boot/cmdline.txt``` file and add the following string to the end of the line in that file.  Reboot the Pi after making this change.

	spidev.bufsiz=65536
	
Include the TCam object from ```tcam.py``` file in your program.

	from tcam import TCam

Create a reference.

	cam = TCam(is_hw=True)

Open a connection to the camera using the default serial (```/dev/serial0```) and SPI master (```/dev/spidev0.0```).

	cam.connect()

To use alternate Pi hardware, specify the device files in the connect method.

	cam.connect(spiFile='/dev/spidev0.1', serialFile='/dev/serial1')
	
### Common API
A common API is used to access and control the attached camera.

Many API calls take an optional timeout value which specify the number of seconds to wait for a response when using the socket interface.  By default the timeout value is 10 seconds.

#### start\_stream(self, delay\_msec=0, num\_frames=0, timeout=None)

	rsp = cam.start_stream()

Sends a ```stream_on``` command to the attached camera.

| Argument | Description |
| --- | --- |
| delay_msec | Delay, in mSec, between frames.  A value of 0 specifies fastest stream.  Non-zero values should be greater than 250 mSec. |
| num_frames | Number of frames to send.  A value of 0 specifies to stream until stopped. |

Returns the ```cam_info``` json response to the command, typically 

	{"cam_info":{"info_value":1,"info_string":"stream_on success"}}

#### stop\_stream(self, timeout=None)

	rsp = cam.stop_stream()

Sends a ```stream_off``` command to the attached camera.

Returns the ```cam_info``` json response to the command.

#### get\_image(self, timeout=None)

	img = cam.get_image()

Sends a ```get_image``` command to the attached camera.

Returns the ```image``` json response.  See the demo code for examples how to process the response into an image using the radiometric and telemetry data.

#### get\_frame(self)

	img = cam.get_frame()

Used to get images from the internal queue when streaming.

Returns an ```image``` json response or None if there are no images available.

#### frame\_count(self)

	num = cam.frame_count()

Returns the number of pending images in the internal queue.  Useful while streaming to determine if there are images to process.

#### run\_ffc(self, timeout=None)
	
	rsp = cam.run_ffc()

Sends a ```run_ffc``` command to the attached camera to initiate a Flat Field Correction.

Returns the ```cam_info``` json response to the command.

#### get\_status(self, timeout=None)

	rsp = cam.get_status()

Sends a ```get_status``` command to the attached camera.

Returns the ```status``` json response.  For example

	{"status":{"Camera":"tCam-Mini-87E9","Model":262402,"Version":"3.0","Time":"9:55:48.149","Date":"8/7/22"}}

#### set\_time(self, hour=None, minute=None, second=None, dow=None, day=None, month=None, year=None, timeout=None)

	rsp = cam.set_time(9, 45, 00, 1, 7, 8, 52)

Sends a ```set_time``` command to the attached camera.  The above example sets the time 09:45:00 on Sunday Aug 7, 2022.

| Argument | Description |
| --- | --- |
| hour | Hour 0 - 23 |
| minute | Minute 0 - 59 |
| second | Second 0 - 59 |
| dow | Day of Week starting with Sunday 1-7 |
| day | Day of Month 1-28 to 1-31 depending |
| month | Month 1-12 |
| year | Year offset from 1970 |

All arguments are required.

Returns the ```cam_info``` json response to the command.

#### get\_config(self, timeout=None)

	rsp = cam.get_config()

Sends a ```get_config``` command to the attached camera.

Returns the ```config``` json response.  For example

	{"config":{"agc_enabled":0,"emissivity":98,"gain_mode":2}}

#### set\_config(self, agc\_enabled=1, emissivity=98, gain\_mode=2, timeout=None)

	rsp = cam.set_config(0, 96, 0)

Sends a ```set_config``` command to the attached camera.  The above example sets AGC off, the emissivity to 96% and gain mode too High.

| Argument | Description |
| --- | --- |
| agc_enabled | Lepton AGC Mode: 1: Enabled, 0: Disabled (Radiometric output) |
| emissivity | Lepton Emissivity: 1 - 100 (integer percent) |
| gain_mode | Lepton Gain Mode: 0: High, 1: Low, 2: Auto |

All arguments are required.

Returns the ```cam_info``` json response to the command.

#### set\_config\_agc(self, agc\_enabled=1, timeout=None)

	rsp = cam.set_config_agc(0)

Sends a ```set_config``` command to the attached camera with only the agc_enabled argument.  The above example sets AGC off.

| Argument | Description |
| --- | --- |
| agc_enabled | Lepton AGC Mode: 1: Enabled, 0: Disabled (Radiometric output) |

Returns the ```cam_info``` json response to the command.

#### set\_config\_emissivity(self, emissivity=98, timeout=None)

	rsp = cam.set_config_emissivity(96)

Sends a ```set_config``` command to the attached camera with only the emissivity argument.  The above example sets the emissivity to 96%.

| Argument | Description |
| --- | --- |
| emissivity | Lepton Emissivity: 1 - 100 (integer percent) |

Returns the ```cam_info``` json response to the command.

#### set\_config\_gain\_mode(self, gain\_mode=2, timeout=None)

	rsp = cam.set_config(0)

Sends a ```set_config``` command to the attached camera with only the gain_mode argument.  The above example sets the gain mode too High.

| Argument | Description |
| --- | --- |
| gain_mode | Lepton Gain Mode: 0: High, 1: Low, 2: Auto |

Returns the ```cam_info``` json response to the command.

#### get\_lep\_cci(self, command=0x4ECC, length=4, timeout=None)

	cci_data = cam.get_lep_cci(0x4EBC, 8)

Sends a ```get_lep_cci``` command to the attached camera.  The above example gets the RAD Flux Linear Parameters.  The command default arguments get the RAD Spotmeter Region of Interest (ROI).

| Argument | Description |
| --- | --- |
| command | 16-bit Lepton COMMAND register value.  Issuing RAD commands requires setting the OEM Bit (Bit 14, value = 0x4000) in the command word in addition to setting the rest of the command word bits. |
| length | Number of 16-bit words to read (1-512) |

All arguments are required.

Returns the ```cci_reg``` json response to the command.  The example will return

	{"command":20156,"length":8,"status":63750,"data":"BQAAADA3MjYtMDEAAAAAAA=="}}

Refer to the Flir document "Software Interface Description Document (IDD)" Document Number: 110-0144-04 Rev 200 for a complete description of the CCI interface including commands, command lengths and data format.

#### set\_lep\_cci(self, command, data, timeout=None)

	reg_array = array.array('H', [20, 20, 21, 21])
	enc_data = reg_array.tobytes()
	rsp = cam.set_lep_cci(0x4ECD, enc_data)

Sends a ```set_lep_cci``` command to the attached camera.  The above example sets the spot meter region of interest to (20, 20) - (21, 21).

| Argument | Description |
| --- | --- |
| command | 16-bit Lepton COMMAND register value.  Issuing RAD commands requires setting the OEM Bit (Bit 14, value = 0x4000) in the command word in addition to setting the rest of the command word bits. |
| data | Data to write to the camera.  Must be a multiple of 16-bit words. |

All arguments are required.

Returns the ```cci_reg``` json response to the command.  The example will return

	{"cci_reg":{"command":20173,"length":0,"status":6}}

Take care using this command. It is possible to crash the Lepton or tCam camera (a power-cycle should restore normal operation).

#### set\_spotmeter(self, c1=79, c2=80, r1=59, r2=60, timeout=None)

	rsp = cam.set_spotmeter(90, 92, 70, 72)

Sends a ```set_spotmeter``` command to the attached camera.  The above example sets the spot meter region of interest to (90, 70) - (92, 72).

| Argument | Description |
| --- | --- |
| c1 | Spotmeter column 1: Left X-axis spotmeter box coordinate (0-159) |
| c2 | Spotmeter column 2: Right X-axis spotmeter box coordinate (0-159) |
| r1 | Spotmeter row 1: Top Y-axis spotmeter box coordinate (0-119) |
| r2 | Spotmeter row 2: Bottom Y-axis spotmeter box coordinate (0-119) |

All arguments are required.

Returns the ```cam_info``` json response to the command.

#### get\_wifi(self, timeout=None)

	rsp = cam.get_wifi()

Sends a ```get_wifi``` command to the attached camera.

Returns the ```wifi``` response.  For example

	{"wifi":{"ap_ssid":"tCam-Mini-289B","sta_ssid":"","flags":15,"ap_ip_addr":"192.168.4.1","sta_ip_addr":"192.168.4.2","sta_netmask":"255.255.255.0","cur_ip_addr":"10.0.1.123"}}

#### set\_wifi\_ap(self, ap\_ssid, ap\_pw, timeout=None)

	cam.set_wifi_ap("AP_SSID", "AP_PASSWORD")

Sends a ```set_wifi``` command to the attached camera to configure it as an Access Point with the specified SSID and password.

| Argument | Description |
| --- | --- |
| ap_ssid | Access Point SSID (1-32 characters).  Also becomes the camera name. |
| ap_pw | Access Point WPA password (8-32 characters). |

All arguments are required.

There is no return value.  You must call ```cam.disconnect()``` following this call since the camera will have disconnected the socket.

#### set\_wifi\_sta(self, sta\_ssid, sta\_pw, is\_static=False, sta\_ip\_addr="192.168.0.2", sta\_ip\_netmask="255.255.255.0", timeout=None)

	cam.set_wifi_sta("STA_SSID", "STA_PW")

Sends a ```set_wifi``` command to the attached camera to configure it as a client to an existing WiFi network obtaining a DHCP-served IP address.

	cam.set_wifi_sta("TA_SSID", "STA_PW", True, "10.0.1.73", "255.255.255.0")

Sends a ```set_wifi``` command to the attached camera to configure it as a client to an existing WiFi network with the specified static IP address.

| Argument | Description |
| --- | --- |
| sta_ssid | Existing WiFi network SSID (1-32 characters) |
| sta_pw | Existing WiFi network password (8-32 characters) |
| is_static | Set True to configure a static IP address, False for a DHCP-served address |
| sta_ip_addr | Static IP address string |
| sta_ip_netmask | Static IP address netmask string |

Only ```sta_ssid``` and ```sta_pw``` are required. 

There is no return value.  You must call ```cam.disconnect()``` following this call since the camera will have disconnected the socket.

#### set\_static\_ip(self, is\_static=False, sta\_ip\_addr="192.168.0.2", sta\_ip\_netmask="255.255.255.0", timeout=None)

	cam.set_static_ip()
	
Sends a ```set_wifi``` command to the attached camera to configure it to receive a DHCP-served IP address.

	cam.set_static_ip(True, "10.0.1.73", "255.255.255.0")
	
Sends a ```set_wifi``` command to the attached camera to configure it with a static IP address (10.0.1.73 in this example).

| Argument | Description |
| --- | --- |
| is_static | Set True to configure a static IP address, False for a DHCP-served address |
| sta_ip_addr | Static IP address string |
| sta_ip_netmask | Static IP address netmask string |

This command should only be run for a WiFi connected camera in STA mode or for an ethernet connected tCam-POE.  It will have no effect for a WiFi connected camera acting as an Access Point.

There is no return value.  You must call ```cam.disconnect()``` following this call since the camera will have disconnected the socket.

#### disconnect(self)

	cam.disconnect()
	
Disconnect the driver from the camera.

#### shutdown(self)

	cam.shutdown()
	
Shut down the driver before finishing your program to close the socket or hardware connection and terminate an internal manager thread.

### Demos
The ```examples``` directory contains several example python programs using the TCam driver.

The example programs take command line arguments.  Look at the source code for example-specific arguments but all socket examples allow specifying the camera IP address as shown.  By default the TCam driver attempts to connect to the default tCam-as-AP address of ```192.168.4.1```.

	disp_image.py -i 10.0.1.71

Some of the demo programs like ```disp_file.py``` and ```dump_image.py``` must be run in the same directory as the ```palettes``` directory.

The ```streamtest_hw.py``` program demonstrates how to use the driver with the hardware interface on a Raspberry Pi.  A tCam-Mini must be connected as shown below.

### tCam-Mini Hardware Interface Connections

tCam-Mini with Pi 3

The tCam-Mini hardware Slave Interface is enabled on power-up when the tCam-Mini detects a jumper from the MODE pin to GND.  Seven wires interface the Slave Interface to the Pi and provide power as shown below.  Be sure to make all the connections before applying power to the Pi.

tCam-Mini Wiring Diagram

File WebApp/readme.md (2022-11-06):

## Simple tCam Web Server

This repository contains a simple web server application for the tCam cameras.  It communicates with one or more cameras via a network connection and acts as web server for viewing images and configuring the system.

tcam_web architecture

It can display an image from a camera or be configured to record images that meet certain detection criteria.  To do this it enables the cameras into streaming mode and analyzes the images it receives.  Right now the detection criteria are very simple.  It will record an image if at least certain percentage of pixels are within a specified temperature range. The image file format is the same as used by the tcam desktop application (containing he image json packet from the camera).

The detection criteria, along with some parameters limiting how many images can be stored based on a detection event, the streaming interval and camera configuration may be setup through the web interface.

tcam_web image view

The application is developed using the [xojo](https://www.xojo.com) development environment.  Sixty-four bit binary images are provided for Mac OS X, Windows and x86 Linux systems.  A 32-bit binary image is provided for Raspbian.  Download the zip file for your platform.  The application can be run directly from the unzipped directory by double clicking the application binary icon but is primarily designed to be executed from a command line or shell program.

#### Platform Caveats

1. You may need to make the Linux application file executable.
2. You will have to authorize the application to operate through the built-in firewall on OS X or Windows platforms.  Normally those systems will prompt you when the application is started.
3. I haven't tested beyond a handful of cameras and web sessions but the application is probably fairly limited in how many cameras and concurrent web sessions it can support.
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

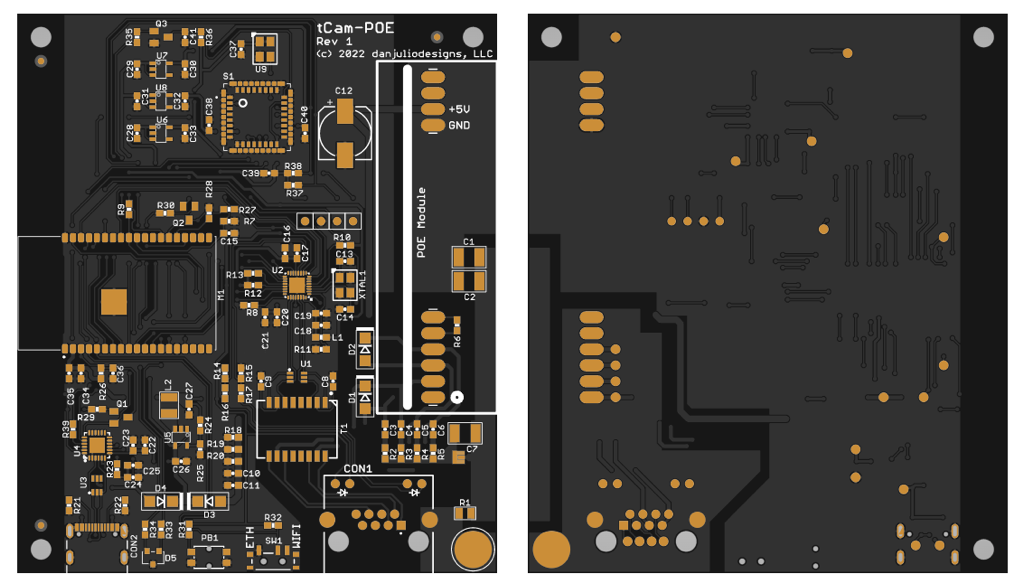
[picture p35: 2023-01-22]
tCam-POE/hardware/pictures/tcam_poe_pcb_r1_render.png

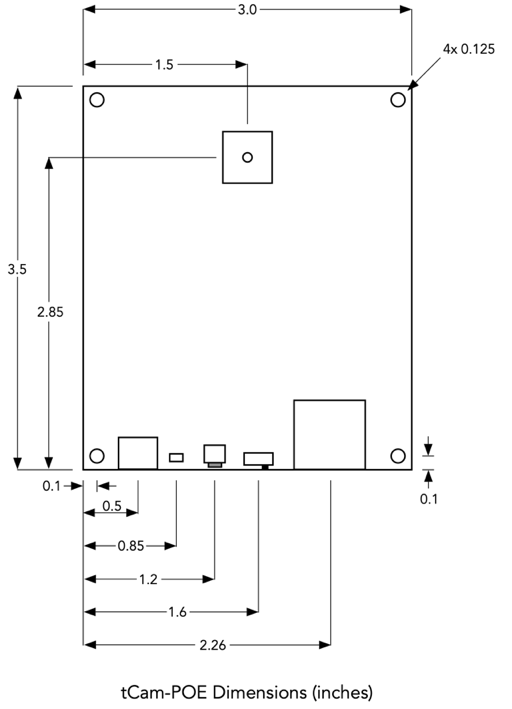
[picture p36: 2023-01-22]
tCam-POE/hardware/pictures/tcam_poe_dimensions.png

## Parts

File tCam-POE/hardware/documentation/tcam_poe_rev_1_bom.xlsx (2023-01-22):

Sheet: tCam-POE Rev 1 PCB
tCam-POE Rev 1 PCB Specifications
Material | FR4
Layers | 2
Thickness | 1.6 mm
Copper Thickness | 1 oz
Soldermask | Black
Silkscreen | White
Finish | LF HASL
Outer Dimensions | 88.9 x 76.2mm (3.5 x 3”)
Drills | 375

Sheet: tCam-POE Rev 1 BOM
tCam-POE Rev 1 PCB Assembly BOM
Line No | Qty | Ref Desg | Part Number | Manuf | Package/Type | Desc | Distributor Part Number | Alternate Part | Notes
1 | 2 | C1, C2 | 202S41W472KV4E | Johanson Dielectrics | SMT/1210 | Multilayer Ceramic Capacitors MLCC - SMD/SMT 2Kvolts 4700pF 10% X7R | Mouser 605-202S41W472KV4E | Kemet C1210C472KGRACTU | May substitute with equal or better
2 | 4 | C3, C4, C5, C6 | CL10B103KC8NHNC | Samsung Electro-Mechanics | SMT/0603 | Multilayer Ceramic Capacitors MLCC - SMD/SMT 10nF+/-10% 100V X7R | Mouser 187-CL10B103KC8NHNC | Murata Electronics GCM188R72A103KA37D | May substitute with equal or better
3 | 1 | C7 | C1210C102KGRACTU | Kemet | SMT/1210 | Multilayer Ceramic Capacitors MLCC - SMD/SMT 2kV 1000pF X7R 1210 10% | Mouser 80-C1210C102KGR | Johanson Dielectrics 202S41W102KV4E | May substitute with equal or better
4 | 14 | C8, C9, C15, C17, C19, C20, C23, C25, C35, C37, C38, C39, C40, C41 | EMK107B7104KAHT | Taiyo Yuden | SMT/0603 | Multilayer Ceramic Capacitors MLCC - SMD/SMT 0603 16VDC 0.1uF 10% X7R AEC-Q200 | Mouser 963-EMK107B7104KAHT | Samsung Electro-Mechanics CL10B104KO8NNWC | May substitute with equal or better
5 | 8 | C10, C11, C16, C18, C21, C22, C24, C26 | JMK107ABJ106KA-T | Taiyo Yuden | SMT/0603 | Multilayer Ceramic Capacitors MLCC - SMD/SMT 0603 6.3VDC 10uF 10% X5R | Mouser 963-JMK107ABJ106KA-T | Samsung Electro-Mechanics CL10A106KQ8NNNC | May substitute with equal or better
6 | 1 | C12 | EDH477M6R3A9MAA | Kemet | SMT | Aluminum Electrolytic Capacitors - SMD 6.3V 470uF 20% 8mm diameter | Mouser 80-EDH477M6R3A9MAA | United Chemi-Con EMVE6R3ADA471MHA0G, Nichicon UWT0J471MNL1GS , Kemet EDH477M6R3A9MAA | May substitute with equal or better
7 | 2 | C13, C14 | CL10C200JB8NNNC | Samsung Electro-Mechanics | SMT/0603 | Multilayer Ceramic Capacitors MLCC - SMD/SMT 20pF+/-5% 50V C0G | Mouser 187-CL10C200JB8NNNC | Walsin 0603N200J500CT | May substitute with equal or better
8 | 3 | C27, C33, C34 | GRM188R60J226MEA0D | Murata | SMT/0603 | Multilayer Ceramic Capacitors MLCC - SMD/SMT 22UF 6.3V 20% 0603 | Mouser 81-GRM188R60J226ME0D | TDK C1608X5R0J226M080AC | May substitute with equal or better
9 | 6 | C28, C29, C30, C31, C32, C36 | TMK107B7105KA-T | Taiyo Yuden | SMT/0603 | Multilayer Ceramic Capacitors MLCC - SMD/SMT 0603 25VDC 1uF 10% X7R | Mouser 963-TMK107B7105KA-T | TDK CGA3E1X7R1E105K080AC | May substitute with equal or better
10 | 1 | CON1 | 615008137421 | Wurth Elektronik | TH | Modular Connectors / Ethernet Connectors WR-MJ Feml Shld Hztl 8P8C Tab Up LED&EMI | Newark 19P1286 (Mouser 710-615008137421) | Pulse Electronics E5J88-14L0D2-L, TE Connectivity 2-406549-1 | May substitute with equal or better
11 | 1 | CON2 | USB4105-GF-A | Global Connector Technology (GCT) | SMT | USB Connectors USB Type C,2.0, Rec,SMT, 0.95mmTH Shell Stakes,G/F,RA,Top Mnt,T&R | Mouser 640-USB4105-GF-A | GCT USB4105-GF-A-120 | May substitute with equal or better
12 | 2 | D1, D2 | SMAJ58CA | Littlefuse | SMT/SMA | ESD Suppressors / TVS Diodes 400W 58V Clamp 93.6V 5% Bi-Directional | Mouser 576-SMAJ58CA | Panjit P4SMAJ58CA_R1_00001, Microchip SMAJ58CAe3/TR13, Yageo SMAJ58CA/TR13, Diodes SMAJ58CA-13-F | May substitute with equal or better
13 | 2 | D3, D4 | SS12_R1_00001 | Panjit | SMT/SMA | Schottky Diodes & Rectifiers 20V Schottky 1A | Mouser 241-SS12_R1_00001 | Diodes B120AF-13, Vishay B120-E3/5AT | May substitute with equal or better
14 | 1 | D5 | AM23ESGW | Kingbright | SMT/SOT23-3 | Standard LEDs - SMD Red/Green Diffused, Common Cathode | Mouser 604-AM23ESGW
15 | 1 | L1 | MFBM1V1608-101-R | Bussmann / Eaton | SMT/0603 | Ferrite Beads Multi H Cur, Impedance 100Ohm 2.5A SMT | Mouser 704-MFBM1V1608-101-R | Bourns MH1608-101Y, TDK MPZ1608Y101BTA00 | May substitute with equal or better
16 | 1 | L2 | MBMK2520T2R2M | Taiyo Yuden | SMT/1008 | Fixed Inductors 0805 2.2uH 159mOhms +/-20% 1250mA | Mouser 963-MBMK2520T2R2M | Murata LQM2HPN2R2MGSL, TDK MLP2520S2R2MT0S1 | May substitute with equal or better
17 | 1 | M1 | ESP32-WROVER-E-N8R8 | Espressif | SMT | WiFi Modules - 802.11 SMD Module ESP32-WROVER-E, ESP32-D0WD-V3, 3.3V 64Mbit PSRAM, 8 MB SPI flash, PCB Antenna | Mouser 356-ESP32WRVE26464PC
18 | 1 | PB1 | 436351045816 | Wurth Elektronik | SMT | Tactile Switches Tact Switch SMT 1.65mm White Act. | Mouser 710-436351045816 | Wurth Elektronik 434331045822 | May substitute with equal or better
19 | 3 | Q1, Q2, Q3 | MMBT3904,215 | Nexperia | SMT/SOT23-3 | Bipolar Transistors - BJT 40V NPN SS Trans 60Vceo 6Vebo 200mA | Mouser 771-MMBT3904T/R | Nexperia Panjit PMBT3904,235, MMBT3904_R1_00001, Diodes MMBT3904-7-F | May substitute with equal or better
20 | 1 | R1 | RK73Z2ATTD | KOA Speer | SMT/0805 | Thick Film Resistors - SMD 0 Ohms 125mW (1/8 W) | Mouser 660-RK73Z2ATTD | Yageo AC0805FR-070RL, Vishay/Dale CRCW08050000Z0EAC | May substitute with equal or better
21 | 5 | R2, R3, R4, R5, R27 | RK73H1JTTDD75R0F | KOA Speer | SMT/0603 | Thick Film Resistors - SMD 1/10W 75 Ohms 0603 1% | Mouser 660-RK73H1JTTDD75R0F | Vishay/Dale CRCW060375R0FKEA, Panasonic ERJ-3EKF75R0V | May substitute with equal or better
22 | 10 | R7, R9, R25, R26, R29, R30, R31, R32, R35, R36 | RC0603FR-0710KL | Yageo | SMT/0603 | Thick Film Resistors - SMD 10 kOhms 100mW 0603 1% | Mouser 603-RC0603FR-0710KL | Panasonic ERJ-3EKF1002V | May substitute with equal or better
23 | 1 | R8 | RC0603FR-076K19L | Yageo | SMT/0603 | Thick Film Resistors - SMD 6.19 kOhms 100 mW 0603 1% | Mouser 603-RC0603FR-076K19L | Panasonic ERJ-3EKF619V | May substitute with equal or better
24 | 13 | R10, R11, R12, R13, R14, R15, R21, R22, R23, R28, R37, R38, R39 | RC0603FR-075K1L | Yageo | SMT/0603 | Thick Film Resistors - SMD 5.1 kOhms 100mW 0603 1% | Mouser 603-RC0603FR-075K1L | Panasonic ERJ-3EKF5101V | May substitute with equal or better
25 | 7 | R16, R17, R18, R19, R20, R33, R34 | RC0603FR-07330RL | Yageo | SMT/0603 | Thick Film Resistors - SMD 330 Ohms 100mW 0603 1% | Mouser 603-RC0603FR-07330RL | Panasonic ERJ-3EKF3300V | May substitute with equal or better
26 | 1 | R24 | RC0603FR-0745K3L | Yageo | SMT/0603 | Thick Film Resistors - SMD 45.3K Ohms 100 mW 0603 1% | Mouser 603-RC0603FR-0745K3L | Panasonic ERJ-3EKF4532V | May substitute with equal or better
27 | 1 | S1 | 105028-1001 | Molex | SMT | IC & Component Sockets 8.5*8.5 AUTO FOCUS C AMERA SOCKET ASSY | Mouser 538-105028-1001
28 | 1 | SW1 | PCM12SMTR | C&K | SMT | Slide Switches 0.3A SPDT ON-ON | Mouser 611-PCM12SMTR | Alps Alpine SSSS810701 | May substitute with equal or better
29 | 1 | T1 | SM13126PEL | Bourns | SMT | Audio Transformers / Signal Transformers LAN 10/100 BASE-T XFMR | Mouser 652-SM13126PEL | Link-PP LP2019ANL, Suotek S16-2019 | May substitute with equal or better
30 | 2 | U1, U3 | SP3002-04JTG | Littlefuse | SMT/SC70-3 | ESD Suppressors / TVS Diodes 4 channels 1.1pF 15kV | Mouser SP3002-04JTG | Littlefuse SP3001-04JTG, On Semi CM1213A-04S7 | May substitute with equal or better
31 | 1 | U2 | IP101GR | IC Plus Corp | SMT/QFN32 | Single Port 10/100 MII/RMII/TP/Fiber Fast Ethernet Transceiver | See Notes | IC Plus Corp IP101GRI | Search octopart.com for IP101GR (Also possibly available from Ali Express)
32 | 1 | U4 | CP2102N-A02-GQFN24 | Silicon Laboratories | SMT/QFN24 | USB Interface IC USBXpress - USB to UART Bridge QFN24 | Mouser 634-CP2102NA02GQFN24
33 | 1 | U5 | TLV62568DBVR | Texas Instruments | SMT/SOT23-5 | Switching Voltage Regulators | Mouser 595-TLV62568DBVR | Diodes Incorporated AP3418KTR-G1 | Search octopart.com for foreign distribution
34 | 1 | U6 | TLV75530PDBVR | Texas Instruments | SMT/SOT23-5 | LDO Voltage Regulators 3V 500-mA low-IQ small-size low-dropout (LDO) regulator | Mouser 595-TLV75530PDBVR | MaxLinear SPX3819M5-L-3-0/TR, On Semi NCP161ASN300T1G | May substitute with equal or better
35 | 1 | U7 | MIC5365-2.8YD5-TR | Microchip | SMT/SOT23-5 | LDO Voltage Regulators Ultra Small Single 2.8V 150mA LDO | Mouser 998-MIC5365-2.8YD5TR | Microchip MIC5317-2.8YM5-TR, Texas Instruments TLV74128PDBVR | May substitute with equal or better
36 | 1 | U8 | MIC5365-1.2YD5-TR | Microchip | SMT/SOT23-5 | LDO Voltage Regulators Ultra Small Single 1.2V 150mA LDO | Mouser 998-MIC5365-1.2YD5TR | Microchip MIC5317-1.2YM5-TR, Texas Instruments TLV71312PDBVR | May substitute with equal or better
37 | 1 | U9 | DSC1001CI1-025.0000 | Microchip | SMT/3225 | Standard Clock Oscillators 3225 pkg -40-85C 50ppm 025.0000MHz | Mouser 998-1001CI1-025.0000 | ECS ECS-3225MVLC-250-BN-TR, Kyocera/AVX KC3225Z25.0000C1GX00, ECS ECS-3225MV-250-BN-TR3 | May substitute with equal or better
38 | 1 | XTAL1 | ECS-250-20-33-TR3 | ECS | SMT/3225 | Crystals 25MHz,CL 20,TOL +/-50 ppm,STAB +/-50 ppm,-20 +70 C,ESR 40Ohm | Mouser 520-250-20-33-TR3 | CTS Electronic Components 403C35E25M00000 | May substitute with equal or better
39 | 1 | POE Module | WC-PD13C050S | Winchen Electronics | TH | DC-DC Converter module, POE IEEE802.3AF 13W 5V | See Notes | Ring&Tone RT9460-5V, Ring&Tone RT9400-5V, Silvertel AG9705-2BR | Search octopart.com. WC-PD13C050S available from Adafruit

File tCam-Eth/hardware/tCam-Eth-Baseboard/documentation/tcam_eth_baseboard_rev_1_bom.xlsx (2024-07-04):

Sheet: tCam-Eth Baseboard Rev 1 PCB
tCam-Eth Baseboard Rev 1 PCB Specifications
Material | FR4
Layers | 2
Thickness | 1.6 mm
Copper Thickness | 1 oz
Soldermask | Green
Silkscreen | White
Finish | LF HASL
Outer Dimensions | 50.8 x 69.85mm (2.0 x 2.75”)
Drills | 74

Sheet: tCam-Eth Baseboard Rev 1 BOM
tCam-Eth Baseboard Rev 1 PCB Assembly BOM
Line No | Qty | Ref Desg | Part Number | Manuf | Package/Type | Desc | Distributor Part Number | Alternate Part | Notes
1 | 5 | C1, C3, C5, C6, C7 | JMK107ABJ106KA-T | Taiyo Yuden | SMT/0603 | Multilayer Ceramic Capacitors MLCC - SMD/SMT 0603 6.3VDC 10uF 10% X5R | Mouser 963-JMK107ABJ106KA-T | Samsung Electro-Mechanics CL10A106KQ8NNNC, Murata GRM188R60J106KE47J | May substitute with equal or better
2 | 4 | C2, C4, C10, C11 | EMK107B7104KAHT | Taiyo Yuden | SMT/0603 | Multilayer Ceramic Capacitors MLCC - SMD/SMT 0603 16VDC 0.1uF 10% X7R AEC-Q200 | Mouser 963-EMK107B7104KAHT | Samsung Electro-Mechanics CL10B104KO8NNWC | May substitute with equal or better
3 | 2 | C8, C9 | 202S41W472KV4E | Johanson Dielectrics | SMT/1210 | Multilayer Ceramic Capacitors MLCC - SMD/SMT 2Kvolts 4700pF 10% X7R | Mouser 605-202S41W472KV4E | Kemet C1210C472KGRACTU | May substitute with equal or better
4 | 1 | CON1 | 54102-0164 | Molex | SMT | Board to Board & Mezzanine Connectors 0.5 BtB Rec Hsg Assy ssy 16Ckt EmbsTp Pkg | Mouser 538-54102-0164
5 | 1 | J1 | USB4105-GF-A | Global Connector Technology (GCT) | SMT | USB Connectors USB Type C,2.0, Rec,SMT, 0.95mmTH Shell Stakes,G/F,RA,Top Mnt,T&R | Mouser 640-USB4105-GF-A | GCT USB4105-GF-A-120 | May substitute with equal or better
6 | 1 | J2 | SI-60001-F | Bel Magnetic Solutions | TH | Modular Connectors / Ethernet Connectors RJ45 Connector | Mouser 530-SI-60001-F | Abracon ARJM11A1-009-AB-EW2 or ARJM11A1-009-NN-EW2 | May substitute with equal or better
7 | 1 | L1 | MBMK2520T2R2M | Taiyo Yuden | SMT/1008 | Fixed Inductors 0805 2.2uH 159mOhms +/-20% 1250mA | Mouser 963-MBMK2520T2R2M | Murata LQM2HPN2R2MGSL, TDK MLP2520S2R2MT0S1, Bourns SRP2510A-2R2M | May substitute with equal or better
8 | 3 | R1, R2, R3 | RC0603FR-075K1L | Yageo | SMT/0603 | Thick Film Resistors - SMD 5.1 kOhms 100mW 0603 1% | Mouser 603-RC0603FR-075K1L | Panasonic ERJ-3EKF5101V | May substitute with equal or better
9 | 1 | R4 | RC0603FR-0710KL | Yageo | SMT/0603 | Thick Film Resistors - SMD 10 kOhms 100mW 0603 1% | Mouser 603-RC0603FR-0710KL | Panasonic ERJ-3EKF1002V | May substitute with equal or better
10 | 1 | R5 | RC0603FR-0745K3L | Yageo | SMT/0603 | Thick Film Resistors - SMD 45.3K Ohms 100 mW 0603 1% | Mouser 603-RC0603FR-0745K3L | Panasonic ERJ-3EKF4532V | May substitute with equal or better
11 | 1 | R6 | RK73Z2ATTD | KOA Speer | SMT/0805 | Thick Film Resistors - SMD 0 Ohms 125mW (1/8 W) | Mouser 660-RK73Z2ATTD | Yageo AC0805FR-070RL, Vishay/Dale CRCW08050000Z0EAC | May substitute with equal or better
12 | 1 | U1 | CP2102N-A02-GQFN24 | Silicon Laboratories | SMT/QFN24 | USB Interface IC USBXpress - USB to UART Bridge QFN24 | Mouser 634-CP2102NA02GQFN24
13 | 1 | U2 | TLV62568DBVR | Texas Instruments | SMT/SOT23-5 | Switching Voltage Regulators | Mouser 595-TLV62568DBVR | Diodes Incorporated AP3418KTR-G1 | Search octopart.com for foreign distribution
14 | 2 | U3, U4 | SP3002-04JTG | Littlefuse | SMT/SC70-3 | ESD Suppressors / TVS Diodes 4 channels 1.1pF 15kV | Mouser SP3002-04JTG | Littlefuse SP3001-04JTG, On Semi CM1213A-04S7 | May substitute with equal or better

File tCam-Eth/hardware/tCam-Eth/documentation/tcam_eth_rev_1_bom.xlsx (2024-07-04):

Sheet: tCam-Eth Rev 1 PCB
tCam-Eth Rev 1 PCB Specifications
Material | FR4
Layers | 4 | See the file “4_layer_pcb_stackup.pdf”
Thickness | 1.6 mm
Copper Thickness | 1 oz
Soldermask | Black
Silkscreen | White
Finish | LF HASL or ENIG
Outer Dimensions | 31.75 x 38.1mm (1.25 x 1.5”)
Drills | 167

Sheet: tCam-Eth Rev 1 Top BOM
tCam-Eth Rev 1 PCB Top Assembly BOM
Line No | Qty | Ref Desg | Part Number | Manuf | Package/Type | Desc | Distributor Part Number | Notes
1 | 3 | C1, C12, C26 | GRM188R60J226MEA0D | Murata | SMT/0603 | Multilayer Ceramic Capacitors MLCC - SMD/SMT 22 uF 6.3 VDC 20% 0603 X5R | Mouser 81-GRM188R60J226ME0D | May substitute with equal or better
2 | 14 | C2, C4, C5, C7, C8, C14, C16, C19, C20, C31, C32, C33, C34, C35 | C0402C104K9RACTU | KEMET | SMT/0402 | Multilayer Ceramic Capacitors MLCC - SMD/SMT 6.3V 0.1uF X7R 0402 10% | Mouser 80-C0402C104K9R | May substitute with equal or better
3 | 3 | C3, C6, C9 | GRM188R60J106KE47J | Murata | SMT/0603 | Multilayer Ceramic Capacitors MLCC - SMD/SMT 10 uF 6.3 VDC 10% 0603 X5R | Mouser 81-GRM188R60J106KE7J | May substitute with equal or better
4 | 2 | C10, C11 | GCM1555C1H330FA16J | Murata | SMT/0402 | Multilayer Ceramic Capacitors MLCC - SMD/SMT 33 pF 50 VDC 1% 0402 C0G (NP0) AEC-Q200 | Mouser 81-GCM1555C1H330FA6J | May substitute with equal or better
5 | 9 | C13, C15, C18, C24, C25, C27, C28, C29, C30 | GRM155R70J105KA12J | Murata | SMT/0402 | Multilayer Ceramic Capacitors MLCC - SMD/SMT 1 uF 6.3 VDC 10% 0402 X7R | Mouser 81-GRM155R70J105KA2J | May substitute with equal or better
6 | 1 | C17 | C0402C101K4GACTU | KEMET | SMT/0402 | Multilayer Ceramic Capacitors MLCC - SMD/SMT 16V 100pF C0G 0402 10% | Mouser 80-C0402C101K4G | May substitute with equal or better
7 | 1 | C21 | C0402C103K8RAC7411 | KEMET | SMT/0402 | Multilayer Ceramic Capacitors MLCC - SMD/SMT 10V 0.01uF X7R 0402 10% | Mouser 80-C0402C103K8RLR | May substitute with equal or better
8 | 2 | C22, C23 | 0402N100D500CT | Walsin | SMT/0402 | Multilayer Ceramic Capacitors MLCC - SMD/SMT 0402 MLCC NPO 10 pF, +/- 0.5pF 50 V T&R GP | Mouser 791-0402N100D500CT | May substitute with equal or better
9 | 1 | J1 | 105028-1001 | Molex | SMT | IC & Component Sockets 8.5*8.5 AUTO FOCUS C AMERA SOCKET ASSY | Mouser 538-105028-1001
10 | 1 | L1 | MFBM1V1608-101-R | Bussmann / Eaton | SMT/0603 | Ferrite Beads Multi H Cur, Impedance 100Ohm 2.5A SMT | Mouser 704-MFBM1V1608-101-R | May substitute with equal or better
11 | 1 | LED1 | 150060YS55040 | Wurth Elektronik | SMT/0603 | Standard LEDs - SMD WL-SMCD SMD MonoChip 0603 Yllw 591nm | Mouser 710-150060YS55040 | May substitute with equal or better
12 | 1 | LED2 | 150060VS55040 | Wurth Elektronik | SMT/0603 | Standard LEDs - SMD WL-SMCD SMD MonoChip 0603 BrtGrn 575nm | Mouser 710-150060VS55040 | May substitute with equal or better
13 | 1 | LED3 | AM23ESGW | Kingbright | SMT/SOT23-3 | Standard LEDs - SMD Red/Green Diffused, Common Cathode | Mouser 604-AM23ESGW | May substitute with equal or better
14 | 1 | PB1 | KMT221NGHFLFS | C&K Switches | SMT | Tactile Switches .5V 1.6N SPST NO SMT Top Actuated | Mouser 611-KMT221NGHFLFS | May substitute with equal or better
15 | 1 | Q1 | MMDT3904_R1_00001 | Panjit | SMT/SOT363 | Bipolar Transistors - BJT DUALNPNGENERALPURPOSESWITCHINGTRANSISTOR VCE40V IC200mA SOT-363 | Mouser 241-MMDT3904R100001 | May substitute with equal or better
16 | 1 | Q2 | NX7002AKVL | Nexperia | SMT/SOT23-3 | MOSFET NX7002AK/SOT23/TO-236AB | Mouser 771-NX7002AKVL | May substitute with equal or better
17 | 10 | R1, R3, R6, R7, R8, R10, R15, R17, R25, R26 | ERJ-2RKF5101X | Panasonic | SMT/0402 | Thick Film Resistors - SMD 0402 5.1Kohms 1% AEC-Q200 | Mouser 667-ERJ-2RKF5101X | May substitute with equal or better
18 | 9 | R2, R5, R13, R16, R20, R21, R23, R24, R27 | ERJ-2RKF1002X | Panasonic | SMT/0402 | Thick Film Resistors - SMD 0402 10Kohms 1% AEC-Q200 | Mouser 667-ERJ-2RKF1002X | May substitute with equal or better
19 | 1 | R4 | ERJ-2RKF6191X | Panasonic | SMT/0402 | Thick Film Resistors - SMD 0402 6.19Kohms 1% AEC-Q200 | Mouser 667-ERJ-2RKF6191X | May substitute with equal or better
20 | 4 | R9, R11, R18, R19 | ERJ-2RKF3300X | Panasonic | SMT/0402 | Thick Film Resistors - SMD 0402 330ohms 1% AEC-Q200 | Mouser 667-ERJ-2RKF3300X | May substitute with equal or better
21 | 1 | R12 | SG73P1JTTD33R0F | KOA Speer | SMT/0603 | Thick Film Resistors - SMD 0.33W 33ohm 1% AEC-Q200 | Mouser 660-SG73P1JTTD33R0F | May substitute with equal or better
22 | 1 | R14 | ERJ-2RKF4990X | Panasonic | SMT/0402 | Thick Film Resistors - SMD 0402 499ohms 1% AEC-Q200 | Mouser 667-ERJ-2RKF4990X | May substitute with equal or better
23 | 1 | R22 | ERJ-2RKF75R0X | Panasonic | SMT/0402 | Thick Film Resistors - SMD 0402 75.0ohms 1% Tol AEC-Q200 | Mouser 667-ERJ-2RKF75R0X | May substitute with equal or better
24 | 1 | U1 | IP101GR | IC Plus Corp | SMT/QFN32 | Single Port 10/100 MII/RMII/TP/Fiber Fast Ethernet Transceiver | LCSC C5454490
25 | 1 | U2 | ESP32-D0WD-V3 | Espressif | SMT/QFN48 | RF System on a Chip - SoC SMD IC WiFi Dual Core BT Combo | Mouser 356-ESP32-D0WD-V3
26 | 1 | U3 | W25Q64JVZPIM | Winbond | SMT/SON8 | NOR Flash spiFlash, 3V, 64M-bit, 4Kb Uniform Sector, DTR | Mouser 454-W25Q64JVZPIM
27 | 1 | U4 | 4677 | Adafruit | SMT/SO8 | Adafruit Accessories Generic 64 Mbit Serial Pseudo SRAM - PSRAM - 3.3V 133 MHz | Mouser 485-4677 | May substitute with equal or better
28 | 1 | U5 | TLV75530PDBVR | Texas Instruments | SMT/SOT23-5 | LDO Voltage Regulators 3V 500-mA low-IQ small-size low-dropout (LDO) regulator | Mouser 595-TLV75530PDBVR | May substitute with equal or better
29 | 1 | U6 | MIC5365-2.8YD5-TR | Microchip | SMT/SOT23-5 | LDO Voltage Regulators Ultra Small Single 2.8V 150mA LDO | Mouser 998-MIC5365-2.8YD5TR | May substitute with equal or better
30 | 1 | U7 | MIC5365-1.2YD5-TR | Microchip | SMT/SOT23-5 | LDO Voltage Regulators Ultra Small Single 1.2V 150mA LDO | Mouser 998-MIC5365-1.2YD5TR | May substitute with equal or better
31 | 1 | U8 | DSC1001CI1-025.0000 | Microchip | SMT/3225 | Standard Clock Oscillators 3225 pkg -40-85C 50ppm 025.0000MHz | Mouser 998-1001CI1-025.0000 | May substitute with equal or better
32 | 1 | XTAL1 | ECS-250-20-33-TR3 | ECS | SMT/3225 | Crystals 25MHz,CL 20,TOL +/-50 ppm,STAB +/-50 ppm,-20 +70 C,ESR 40Ohm | Mouser 520-250-20-33-TR3 | May substitute with equal or better
33 | 1 | XTAL2 | ECS-400-10-33B-CKM-TR | ECS | SMT/3225 | Crystals 40MHz 10ppm 10pF -20C +70C | Mouser 520-400-10-33B-CKMT | May substitute with equal or better

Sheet: tCam-Eth Rev 1 Btm BOM
tCam-Eth Rev 1 PCB Bottom Assembly BOM
Line No | Qty | Ref Desg | Part Number | Manuf | Package/Type | Desc | Distributor Part Number | Notes
1 | 1 | CON1 | 500334-0160 | Molex | SMT | Board to Board & Mezzanine Connectors 0.5 BtB Plg Assy 16C ssy 16Ckt EmbsTp Pkg | Mouser 538-500334-0160

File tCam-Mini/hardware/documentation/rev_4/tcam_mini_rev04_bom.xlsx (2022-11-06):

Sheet: tCam-Mini - Rev 04 - Top PCB As
tCam-Mini PCB Assembly - Top Side - Rev 04
Line No | Qty | Ref Desg | Part Number | Manuf | Package/Type | Desc | Distributor Part Number | Notes
1 | 4 | C1, C2, C4, C6 | JMK107BJ475KA-T | Taiyo Yuden | SMD/0603 | Multilayer Ceramic Capacitors MLCC - 6.3VDC 4.7uF 10% X5R | Mouser 963-JMK107BJ475KA-T | May substitute equal or better
2 | 8 | C3, C5, C14, C17, C18, C19, C20, C21 | EMK107B7104KAHT | Taiyo Yuden | SMD/0603 | Multilayer Ceramic Capacitors MLCC - 16VDC 0.1uF 10% X7R | Mouser 963-EMK107B7104KAHT | May substitute equal or better
3 | 3 | C7, C9, C15 | GRM188R60J226MEA0D | Murata | SMD/0603 | Multilayer Ceramic Capacitors MLCC - SMD/SMT 0603 22uF 6.3volts | Mouser 81-GRM188R60J226ME0D | May substitute equal or better
4 | 6 | C8, C10, C11, C12, C13, C16 | TMK107B7105KA-T | Taiyo Yuden | SMD/0603 | Multilayer Ceramic Capacitors MLCC - 25VDC 1uF 10% X7R | Mouser 963-TMK107B7105KA-T | May substitute equal or better
5 | 1 | CON1 | USB4105-GF-A | Global Connector Technology | SMD | USB Connectors USB Type C,2.0, Rec,SMT,TH Shell Stakes,G/F,RA,Top Mnt | Mouser 640-USB4105-GF-A | May substitute equal or better
6 | 1 | D1 | SP0503BAHTG | Littlefuse | SMD/SOT-143-4 | ESD Suppressors / TVS Diodes | Mouser 576-SP0503BAHTG
7 | 1 | D2 | AM23ESGW | Kingbright | SMT/SOT23 | Standard LEDs - SMD Red/Green Diffused, Common Cathode | Mouser 604-AM23ESGW
7 | 1 | L1 | MBMK2520T2R2M | Taiyo Yuden | SMD/0805 | Fixed Inductors 0805 2.2uH 159mOhms +/-20% 1250mA | Mouser 963-MBMK2520T2R2M | May substitute equal or better
8 | 1 | PB1 | 436351045816 | Wurth Elektronik | SMD | Tactile Switches Tact Switch SMT 1.65mm White Act. | Mouser 710-436351045816 | May substitute equal or better
9 | 3 | Q1, Q2, Q3 | MMBT3904-7-F | Diodes Incorporated | SMD/SOT23-3 | Bipolar Transistors - BJT 40V NPN SS Trans 60Vceo 6Vebo 200mA | Mouser 621-MMBT3904-F | May substitute equal or better
10 | 4 | R1, R2, R13, R14 | RC0603FR-075K1L | Yageo | SMD/0603 | Thick Film Resistors - SMD 5.1 kOhms 100mW 0603 1% | Mouser 603-RC0603FR-075K1L | May substitute equal or better
10 | 1 | R3 | RC0603FR-071KL | Yageo | SMD/0603 | Thick Film Resistors - SMD 1K OHM 1% | Mouser 603-RC0603FR-071KL | May substitute equal or better
11 | 1 | R4 | RC0603FR-0745K3L | Yageo | SMD/0603 | Thick Film Resistors - SMD 45.3K OHM 1% | Mouser 603-RC0603FR-0745K3L | May substitute equal or better
12 | 6 | R5, R6, R7, R8, R9, R10 | RC0603FR-0710KL | Yageo | SMD/0603 | Thick Film Resistors - SMD 10K OHM 1% | Mouser 603-RC0603FR-0710KL | May substitute equal or better
13 | 2 | R11, R12 | RC0603FR-07330RL | Yageo | SMD/0603 | Thick Film Resistors - SMD 330 OHM 1% | Mouser 603-RC0603FR-07330RL | May substitute equal or better
14 | 1 | S1 | 105028-1001 | Molex | SMD | IC & Component Sockets 8.5*8.5 AUTO FOCUS C AMERA SOCKET ASSY | Mouser 538-105028-1001
15 | 1 | U1 | CP2102N-A02-GQFN24R | Silicon Laboratories | SMD/QFN24 | USB Interface IC USBXpress - USB to UART Bridge | Mouser 634-CP2102NA02QFN24R
16 | 1 | U2 | TLV62568DBVR | Texas Instruments | SMD/SOT23-5 | Switching Voltage Regulators | Mouser 595-TLV62568DBVR
17 | 1 | U3 | TLV75530PDBVR | Texas Instruments | SMD/SOT23-5 | LDO Voltage Regulators 500-mA low-IQ small-size low-dropout (LDO) regulator | Mouser 595-TLV75530PDBVR | May substitute equal or better
18 | 1 | U4 | MIC5365-2.8YD5-TR | Microchip | SMD/SOT23-5 | LDO Voltage Regulators Ultra Small Single 150mA LDO | Mouser 998-MIC5365-2.8YD5TR | May substitute equal or better
19 | 1 | U5 | MIC5365-1.2YD5-TR | Microchip | SMD/SOT23-5 | LDO Voltage Regulators Ultra Small Single 150mA LDO | Mouser 998-MIC5365-1.2YD5TR | May substitute equal or better
20 | 1 | U6 | DSC1001CI1-025.0000 | Microchip | SMD/3225 | Standard Clock Oscillators 3225 pkg -40-85C 50ppm 025.0000MHz | Mouser 998-1001CI1-025.0000 | May substitute equal or better
21 | 1 | PCB |  |  |  | 2-layer FR-4, 1.6mm, 1 oz copper, ENIG finish, Black solder mask, White Silkscreen (rev 4) |  | Panelization at discretion of CM
22 | 1 |  | 500-0771-01 | Flir |  | Thermal Image Sensor 160Hx120V | Group Gets Lepton 3.5 or DigiKey 500-0771-01-ND | Installed in S1 after PCB Assy

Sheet: tCam-Mini - Rev 04 - Bot PCB As
tCam-Mini PCB Assembly - Bottom Side - Rev 04
Line No | Qty | Ref Desg | Part Number | Manuf | Package/Type | Desc | Distributor Part Number | Notes
1 | 1 | M1 | ESP32-WROVER-E(M213EH6464PH3Q0) | Espressif | SMD | WiFi Modules (802.11) SMD Module ESP32-WROVER-E, ESP32-D0WD-V3, 3.3V 64Mbit PSRAM, 8 MB SPI flash, PCB Antenna | Mouser 356-ESP32WRVE26464PC | Use this part if you desire a built-in antenna
2 | 1 | M1 | ESP32-WROVER-IE(M213EH6464UH3Q0) | Espressif | SMD | WiFi Modules (802.11) SMD Module ESP32-WROVER-IE, ESP32-D0WD-V3, 3.3V 64Mbit PSRAM, 8 MB SPI flash, IPEX connector | Mouser 356-ESP32WRVIE6464UC | Use this part if you desire an external antenna
3 | 1 |  | 080-0001 | Laird Connectivity | Cable | RF Cable assembly U.FL to RP-SMA Bulkhead cable 105 mm | Mouser 741-080-0001 | User this part if you desire an external antenna
4 | 1 |  | RN-SMA-S-RP | Microchip | Antenna | Antenna 2.4 GHz 1” Stubby Rev Pol SMA | Mouser 765-RN-SMA-S-RP | Use this part if you desire an external antenna

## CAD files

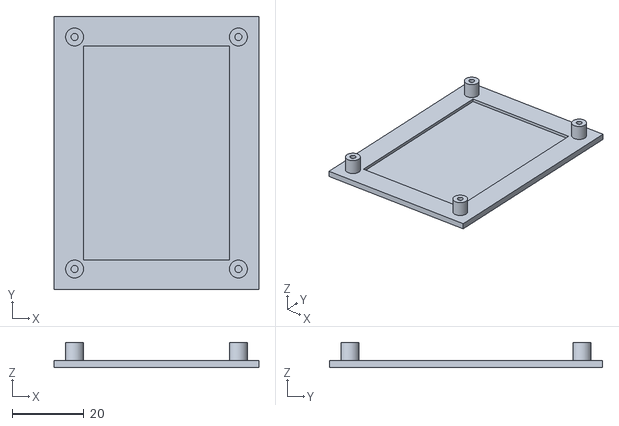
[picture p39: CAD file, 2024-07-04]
tCam-Eth/hardware/tCam-Eth-Baseboard/mounting_plate/tcam_eth_baseboard_base.stl
57.1 x 76.2 x 7.00

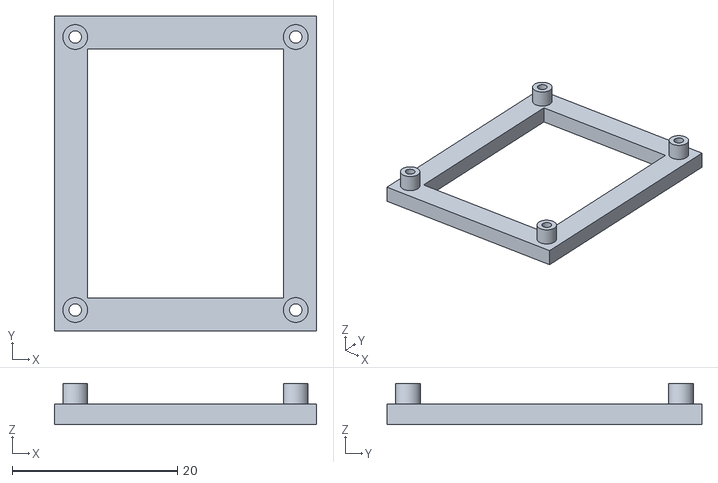
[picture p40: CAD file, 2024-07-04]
tCam-Eth/hardware/tCam-Eth-Baseboard/spacer/tcam_eth_base_mount.stl
31.8 x 38.1 x 5.00

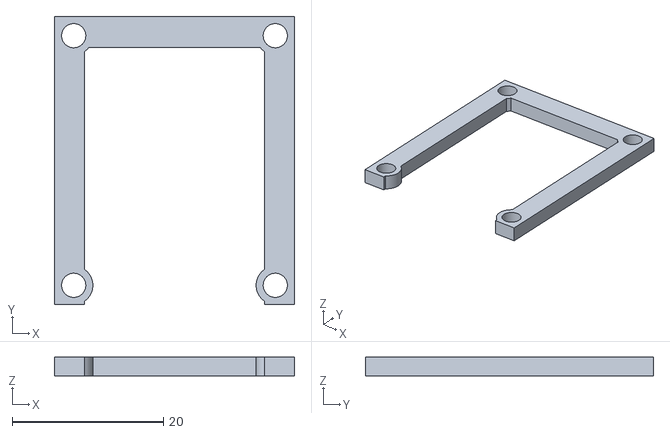
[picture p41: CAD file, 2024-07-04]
tCam-Eth/hardware/tCam-Eth/spacer/tcam_eth_mount.stl
31.8 x 38.1 x 2.50

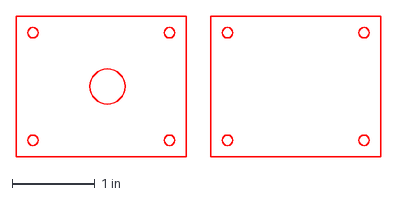
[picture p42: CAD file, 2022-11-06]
tCam-Mini/enclosure/laser/tcam_mini_cutout.dxf
4.40 x 1.70 in

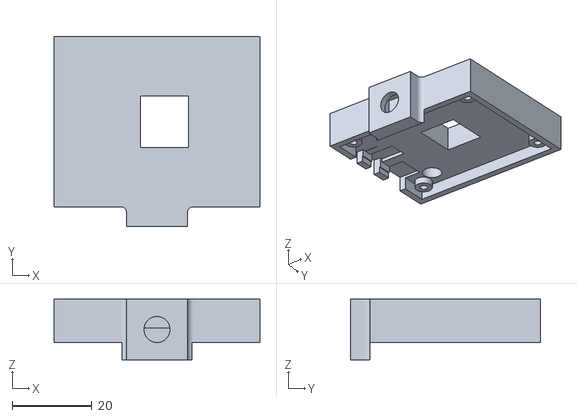
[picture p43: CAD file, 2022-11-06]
tCam-Mini/enclosure/zeke_gustafson/Enclosure Front.stl
51.6 x 47.7 x 15.2

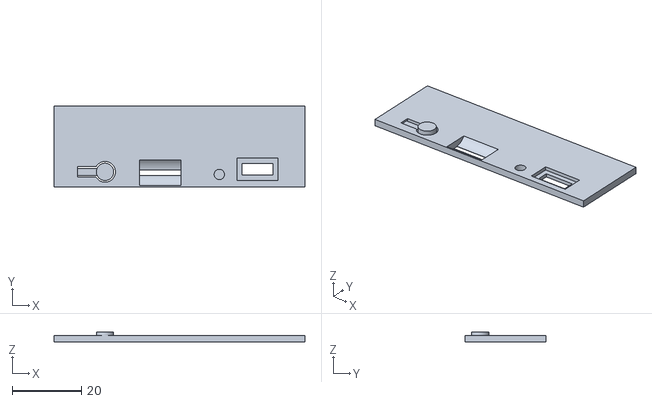
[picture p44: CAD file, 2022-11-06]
tCam/enclosure/tcam_fdm/tcam_flat_batt_io.stl
72.5 x 23.4 x 3.00

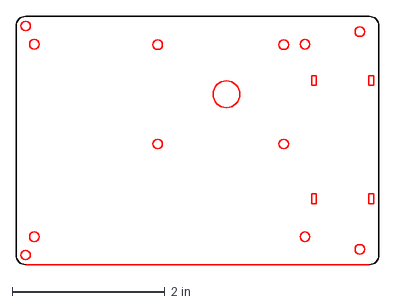
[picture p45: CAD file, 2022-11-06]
tCam/enclosure/tcam_laser/tcam_laser_rear.dxf
4.75 x 3.25 in

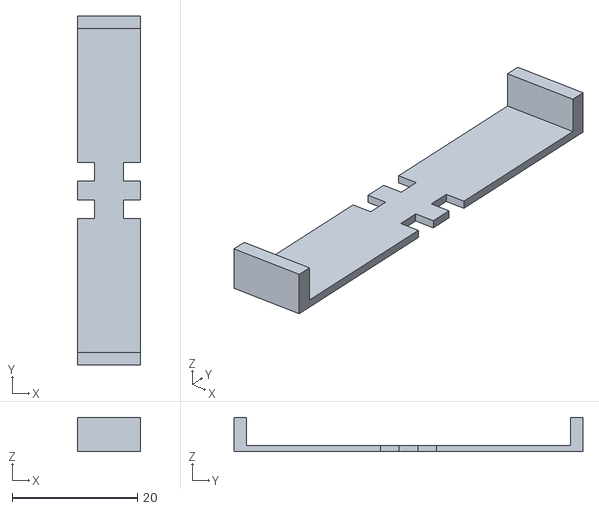
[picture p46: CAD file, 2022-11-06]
tCam-Mini/enclosure/tcam_mini_basic/tcam_mini_basic/tcam_mini_gp_mount_h.stl
10.0 x 55.7 x 5.50

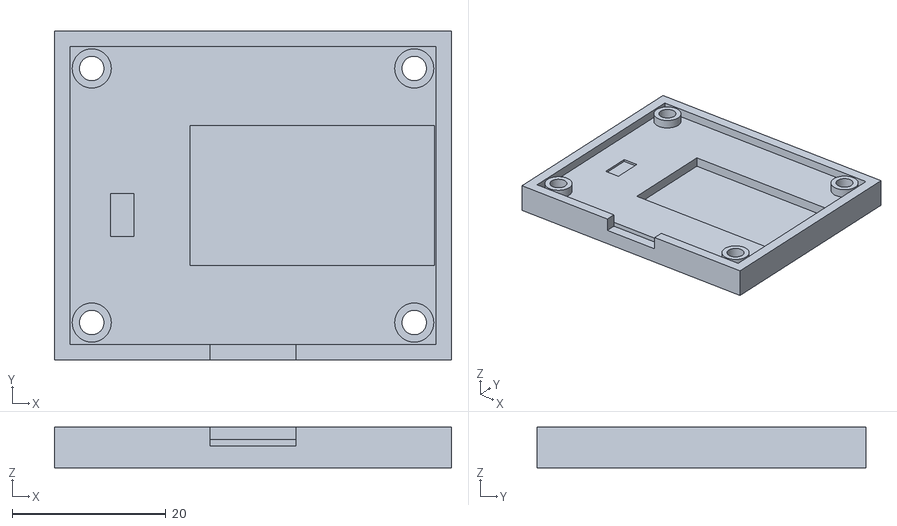
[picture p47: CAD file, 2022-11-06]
tCam-Mini/enclosure/zeke_gustafson/Enclosure Back.stl
51.6 x 42.7 x 5.30

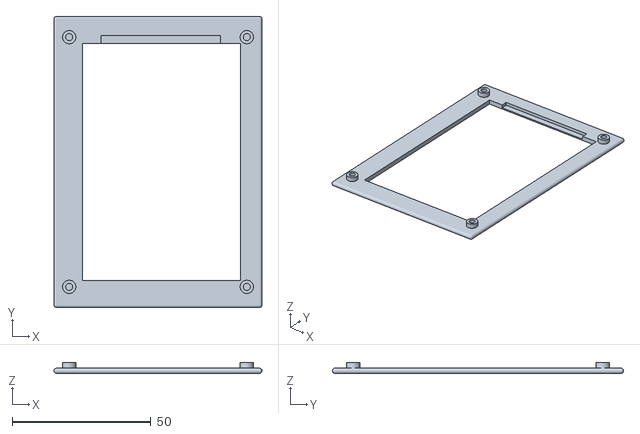
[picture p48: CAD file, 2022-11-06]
tCam/enclosure/tcam_fdm/tcam_flat_batt_bezel.stl
75.0 x 105.0 x 3.98

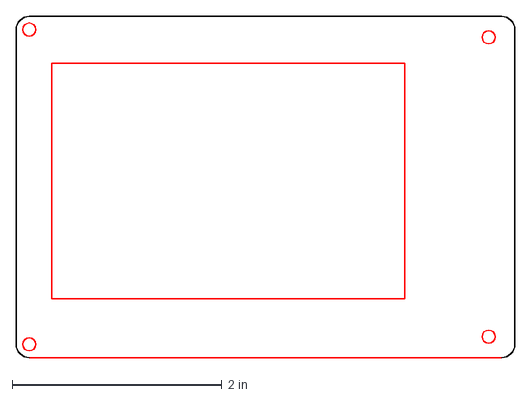
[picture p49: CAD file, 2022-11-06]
tCam/enclosure/tcam_laser/tcam_laser_front.dxf
4.75 x 3.25 in

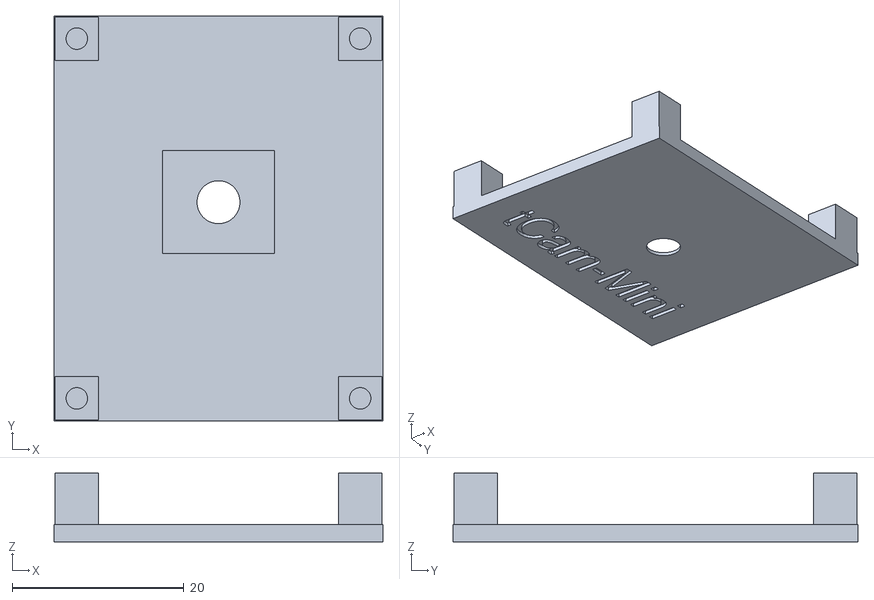
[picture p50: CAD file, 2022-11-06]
tCam-Mini/enclosure/tcam_mini_basic/tcam_mini_basic/tcam_mini_bezel.stl
38.3 x 47.2 x 8.00

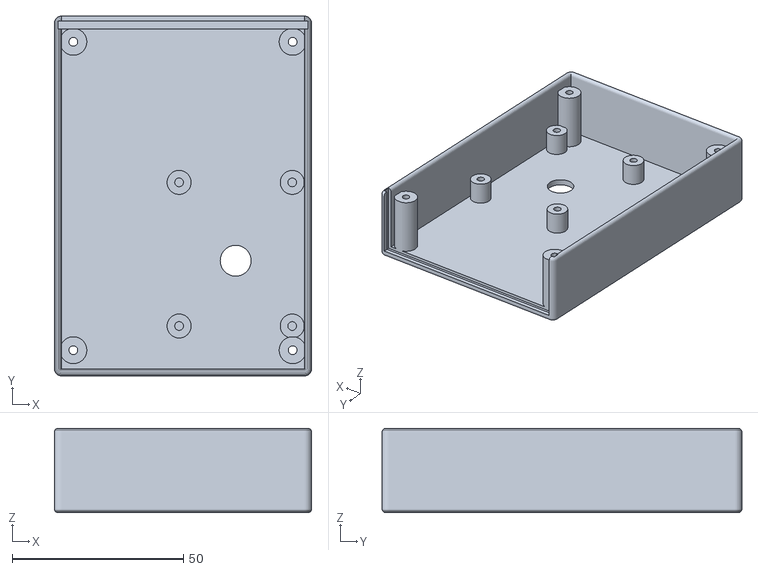
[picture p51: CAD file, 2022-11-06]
tCam/enclosure/tcam_fdm/tcam_flat_batt_base.stl
75.0 x 105.0 x 24.6

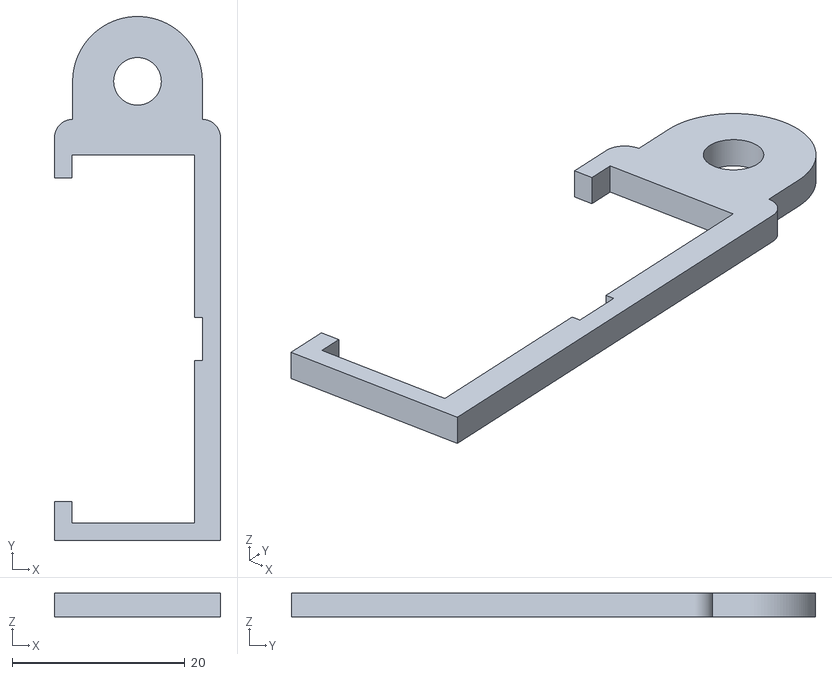
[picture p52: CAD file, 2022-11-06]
tCam-Mini/enclosure/tcam_mini_basic/tcam_mini_basic/tcam_mini_gp_mount_v.stl
19.2 x 60.6 x 2.75

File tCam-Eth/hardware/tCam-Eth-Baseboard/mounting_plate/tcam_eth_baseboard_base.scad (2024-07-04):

//
// tCam-Eth baseboard base
//

// Baseboard dimensions
bb_w = 2.0 * 25.4;
bb_l = 2.75 * 25.4;
bb_mnt_offset_x = 0.1 * 25.4;
bb_mnt_offset_y = 0.1 * 25.4;
bb_mnt_delta_x = bb_w - (2 * bb_mnt_offset_x);
bb_mnt_delta_y = bb_l - (2 * bb_mnt_offset_y);

// Outer dimensions
base_w = bb_w + (0.25 * 25.4);
base_l = bb_l + (0.25 * 25.4);
base_h = 2.0;
base_mnt_x0 = ((base_w - bb_w) / 2) + bb_mnt_offset_x;
base_mnt_y0 = ((base_l - bb_l) / 2) + bb_mnt_offset_y;

// Mount post (above base plate)
base_mnt_d = 5;
base_mnt_h = 5;

// Mount post screw hole diameter (should be smaller than the screw)
base_mnt_screw_hole_d = 2.0;


module mnt_post(x, y)
{
    translate([x, y, base_h - 0.1]) {
        difference() {
            cylinder(d = base_mnt_d, h = base_mnt_h + 0.1, $fn=120);
            
            cylinder(d = base_mnt_screw_hole_d, h = base_mnt_h + 0.2, $fn=120);
        }
    }
}



union()
{
    // Base plate with some cutout in the middle to reduce print time
    difference() {
        cube([base_w, base_l, base_h]);
        
        translate([base_mnt_x0 + base_mnt_d/2, base_mnt_y0 + base_mnt_d/2, 1]) {
            cube([bb_mnt_delta_x - base_mnt_d, bb_mnt_delta_y - base_mnt_d, base_h]);
        }
    }
    
    mnt_post(base_mnt_x0, base_mnt_y0);
    mnt_post(base_mnt_x0 + bb_mnt_delta_x, base_mnt_y0);
    mnt_post(base_mnt_x0, base_mnt_y0 + bb_mnt_delta_y);
    mnt_post(base_mnt_x0 + bb_mnt_delta_x, base_mnt_y0 + bb_mnt_delta_y);
}

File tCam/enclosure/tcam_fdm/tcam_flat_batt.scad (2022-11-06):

//
// Standalone enclosure for a tCam with gCore, tCam-Mini and a flat battery.
//
// Copyright 2022 (c) Dan Julio
//
// Apologies as I'm not a mechanical engineer and this is a bit of a hack...  But
// it gets the job done.
//
// Dimensions are mm.
//
// Version 1.0 - Initial release
//
// standalone_enclosure is free software: you can redistribute it and/or modify
// it under the terms of the GNU General Public License as published by
// the Free Software Foundation, either version 3 of the License, or
// (at your option) any later version.
//
// standalone_enclosure is distributed in the hope that it will be useful,
// but WITHOUT ANY WARRANTY; without even the implied warranty of
// MERCHANTABILITY or FITNESS FOR A PARTICULAR PURPOSE.  See the
// GNU General Public License for more details.
//
// You should have received a copy of the GNU General Public License
// along with standalone_enclosure.  If not, see <https://www.gnu.org/licenses/>.
//
//
use <openscad_libraries/smooth_prim.scad>
use <openscad_libraries/gcore.scad>

//
// Render control
//   1 - Draw Base for STL export
//   2 - Draw IO Assembly for STL export
//   3 - Draw Bezel for STL export
//   4 - Draw Base and IO Assembly for debug
//   5 - Draw all parts for debug
render_mode = 3;

//
// Definitions
//

// Mounting screw dimensions - 4/40 x 0.25"
screw_length = 6.35;
screw_diameter = 2.8;
screw_head_diameter = 5.6;

// gCore PCB Dimensions (taken from gCore)
gcore_width = 69;
gcore_depth = 95;
gcore_height = 1.6;
gcore_lcd_width = 56.5;
gcore_lcd_depth = 85;
gcore_lcd_height = 4;
gcore_lcd_offset_x = 7.5;
gcore_lcd_offset_y = 5;
gcore_mnt_hole_d = 2.8;
gcore_mnt_hole_inset = 2.5;

// tCam-Mini hole dimensions
mini_height = 1.6;
mini_x1_from_gcore_x1 = 30.86 ;
mini_y1_from_gcore_y1 = 7.06;
mini_x_delta = 33.02;
mini_y_delta = 41.91;
mini_lep_from_gcore_x1 = 47.37;
mini_lep_from_gcore_y1 = 26.11;
mini_standoff_h = 7.4;
mini_lep_hole_d = 9;

// Base Dimensions
top_wall_thickness = 2;
wall_thickness = 2;
encl_open_space_height = 10 + 1.6 + 7 + 0.4;
encl_offset_x = 3;
encl_offset_y = 5;

encl_width = gcore_width + 2*encl_offset_x;
encl_depth = gcore_depth + 2*encl_offset_y;
encl_height = encl_open_space_height + gcore_height + wall_thickness + (gcore_lcd_height - top_wall_thickness);

// Base Mounting posts
encl_mnt_hole_d = screw_diameter - 0.25;
encl_mnt_screw_d = screw_head_diameter + 0.25;
encl_mnt_base_d = encl_mnt_screw_d + 2;
encl_mnt_inset_x = (encl_width - gcore_width)/2 + gcore_mnt_hole_inset;
encl_mnt_inset_y = (encl_depth - gcore_depth)/2 + gcore_mnt_hole_inset;
encl_mnt_x = [encl_mnt_inset_x, encl_width - encl_mnt_inset_x, encl_mnt_inset_x, encl_width - encl_mnt_inset_x];
encl_mnt_y = [encl_mnt_inset_y, encl_mnt_inset_y, encl_depth - encl_mnt_inset_y, encl_depth - encl_mnt_inset_y];
encl_mnt_base_h = wall_thickness + encl_open_space_height;
encl_mnt_screw_cutout_h = encl_mnt_base_h - (screw_length - gcore_height - (gcore_lcd_height - top_wall_thickness));

// tCam-Mini Mounting posts
mini_x1 = encl_mnt_inset_x + mini_x1_from_gcore_x1;
mini_y1 = encl_mnt_inset_y + mini_y1_from_gcore_y1;
encl_mnt_mini_x = [mini_x1, mini_x1, mini_x1 + mini_x_delta, mini_x1 + mini_x_delta];
encl_mnt_mini_y = [mini_y1, mini_y1 + mini_y_delta, mini_y1, mini_y1 + mini_y_delta];
encl_mnt_mini_h = wall_thickness + mini_standoff_h;
encl_mnt_mini_screw_cutout_h = screw_length - mini_height;
encl_mnt_mini_base_d = 7;
encl_mnt_lep_x = encl_mnt_inset_x + mini_lep_from_gcore_x1;
encl_mnt_lep_y = encl_mnt_inset_y + mini_lep_from_gcore_y1;


// tCam-Mini Lepton hole

// Base IO Assy mounting dimensions
encl_io_assy_tolerance = 0.25;
encl_io_assy_thickness = 2 + 2 * encl_io_assy_tolerance;
encl_io_assy_x_offset = 1;
encl_io_assy_y_offset = encl_depth - encl_io_assy_thickness - 1 - encl_io_assy_tolerance;
encl_io_assy_z_offset = 1;

// IO Assembly Dimensions (taken from gCore)
// This is a block extending the depth of gCore, above
// and below the PCB with cutouts for the USB connector,
// Micro-SD card and power button cap/cutout.  In addition it
// provides a very thin wall for the charge LED to light
// through.  A cutout should be made in the outside
// enclosure starting at the top of the wall to access
// this assembly.
io_assy_x_offset = encl_io_assy_x_offset + encl_io_assy_tolerance;
io_assy_y_offset = encl_io_assy_y_offset + encl_io_assy_tolerance;
io_assy_z_offset = 1;
io_assy_width = encl_width - 2 * encl_io_assy_x_offset - 2 * encl_io_assy_tolerance;
io_assy_height = encl_height - io_assy_z_offset - encl_io_assy_tolerance;
io_assy_depth = encl_io_assy_thickness - 2 * encl_io_assy_tolerance;
io_assy_btn_center_x = 13 + (encl_width - gcore_width)/2 - io_assy_x_offset;
io_assy_btn_center_y = 0;
io_assy_btn_center_z = encl_open_space_height + (wall_thickness - encl_io_assy_x_offset) - 1;
io_assy_btn_d = 5;
io_assy_btn_h = 1; // Height above surface
io_assy_btn_gap = 0.5;
io_assy_btn_hole_d = io_assy_btn_d + 2*io_assy_btn_gap;
io_assy_btn_cutout_w = 3;
io_assy_btn_cutout_l = 8;
io_assy_btn_lever_depth = io_assy_depth - 0.5;
io_assy_sd_height = 1.5;
io_assy_sd_width = 12;
io_assy_sd_cyl_d = 9;
io_assy_sd_center_x = 29 + (encl_width - gcore_width)/2 - io_assy_x_offset;
io_assy_sd_center_y = -1;
io_assy_sd_center_z = encl_open_space_height + (wall_thickness - encl_io_assy_x_offset) - 0.75;
io_assy_led_center_x = 46 + (encl_width - gcore_width)/2 - io_assy_x_offset;
io_assy_led_center_y = 0.25; // Window thickness
io_assy_led_center_z = encl_open_space_height + (wall_thickness - encl_io_assy_x_offset) - 0.25;
io_assy_led_hole_d = 3;
io_assy_usb_height = 3.4;
io_assy_usb_width = 9;
io_assy_usb_center_x = 57 + (encl_width - gcore_width)/2 - io_assy_x_offset;
io_assy_usb_center_y = -1;
io_assy_usb_center_z = encl_open_space_height + (wall_thickness - encl_io_assy_x_offset) - 1.75;
io_assy_usb_wall_thick = 1;
io_assy_usb_cutout_height = io_assy_usb_height + 3;
io_assy_usb_cutout_width = io_assy_usb_width + 2.8;

// Small button cutout on bottom
btn_cutout_width = 2.4;
btn_cutout_height = 1.6;
btn_cutout_depth = 0.75;
btn_cutout_offset_x = -(btn_cutout_width/2);
btn_cutout_offset_z = -(btn_cutout_height/2);


// Bezel Dimensions
bezel_width = encl_width;
bezel_depth = encl_depth;
bezel_height = top_wall_thickness;

bezel_cutout_tolerance = 0.25;
bezel_cutout_offset_x = encl_offset_x + gcore_lcd_offset_x - bezel_cutout_tolerance;
bezel_cutout_offset_y = encl_offset_y + gcore_lcd_offset_y - bezel_cutout_tolerance;

// Bezel LCD flex wiring cutout
bezel_flex_offset_x = encl_offset_x + 14;
bezel_flex_offset_y = encl_offset_y + gcore_lcd_offset_y - 3;
bezel_flex_offset_depth = 3;
bezel_flex_offset_width = 43;
bezel_flex_offset_height = bezel_height - 0.6;

// Bezel Mounting posts
bezel_mnt_post_d = gcore_mnt_hole_d + 2;
bezel_mnt_drill_d = screw_diameter - 0.25; //gcore_mnt_hole_d;
bezel_mnt_post_h = gcore_lcd_height - bezel_height;
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

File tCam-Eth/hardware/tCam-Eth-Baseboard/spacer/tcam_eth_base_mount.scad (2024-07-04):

//
// tCam-Eth baseboard mounting bracket
//

// Outer dimensions
mnt_w = 1.25 * 25.4;
mnt_l = 1.5 * 25.4;
mnt_h = 2.5;

// Wall width
wall_w = 4;

// Mounting hole locations
hole_center_x = 0.1 * 25.4;
hole_center_y = 0.1 * 25.4;
post_d = 3;
hole_d = 1.5;

difference() {
    union() {
        difference() {
            cube([mnt_w, mnt_l, mnt_h]);
            
            translate([wall_w, wall_w, -0.1]) {
                cube([mnt_w - 2*wall_w, mnt_l - 2*wall_w, mnt_h + 0.2]);
            }
        }
        
        // Mount posts
        translate([hole_center_x, hole_center_y, 0]) {
            cylinder(d = post_d, h = 2*mnt_h, $fn=120);
        }

        translate([mnt_w - hole_center_x, hole_center_y, 0]) {
            cylinder(d = post_d, h = 2*mnt_h, $fn=120);
        }
        
        translate([hole_center_x, mnt_l - hole_center_y, 0]) {
            cylinder(d = post_d, h = 2*mnt_h, $fn=120);
        }
        
        translate([mnt_w - hole_center_x, mnt_l - hole_center_y, 0]) {
            cylinder(d = post_d, h = 2*mnt_h, $fn=120);
        }
    }
    
    // Mounting screw guides
    translate([hole_center_x, hole_center_y, -0.1]) {
        cylinder(d = hole_d, h = 2*mnt_h + 0.2, $fn=120);
    }
    
    translate([mnt_w - hole_center_x, hole_center_y, -0.1]) {
        cylinder(d = hole_d, h = 2*mnt_h + 0.2, $fn=120);
    }
    
    translate([hole_center_x, mnt_l - hole_center_y, -0.1]) {
        cylinder(d = hole_d, h = 2*mnt_h + 0.2, $fn=120);
    }
    
    translate([mnt_w - hole_center_x, mnt_l - hole_center_y, -0.1]) {
        cylinder(d = hole_d, h = 2*mnt_h + 0.2, $fn=120);
    }
}

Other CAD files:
tCam-Mini/enclosure/tcam_mini_basic/tcam_mini_basic/tcam_mini_rev4_encl.stl
tCam-Mini/enclosure/tcam_mini_basic/tcam_mini_basic/tcam_mini_rev2_encl.stl
tCam-Eth/hardware/tCam-Eth/spacer/tcam_eth_mount.scad
tCam-Mini/enclosure/tcam_mini_basic/openscad_libraries/smooth_prim.scad
tCam-Mini/enclosure/tcam_mini_basic/openscad_libraries/tcam_mini.scad
tCam-Mini/enclosure/tcam_mini_basic/tcam_mini_basic/tcam_mini_basic_encl.scad
tCam-Mini/enclosure/tcam_mini_basic/tcam_mini_basic/tcam_mini_gp_mount.scad
tCam-Mini/enclosure/zeke_gustafson/tCam-mini enclosure.f3d
tCam/enclosure/tcam_fdm/openscad_libraries/gcore.scad
tCam/enclosure/tcam_fdm/openscad_libraries/smooth_prim.scad

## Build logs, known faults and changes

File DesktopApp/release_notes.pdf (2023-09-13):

tcam Desktop Application
Release Notes

Version 3.2.0
1. Min/Max Markers for radiometric cameras (may be included in graphs)
2. Export mp4 video [Mac platform only] from tmjsn files
3. Fixed bugs in export picture that would misplace markers for image size other than 320x240 pixels
4. Reformat export picture format to include marker temperatures
5. Improved rendering performance

Version 3.1.0
1. Support 63 character WiFi passwords with all tCam firmware and tCam-Mini firmware 3.1 and beyond
2. Disabled Graph when connected to a camera with a Lepton 3.0
3. Display “RAW” and “AGC” in color palette bar when connected to a camera with a Lepton 3.0
4. Worked around Xojo bug where pull-down menus didn't work properly in Linux builds (starting with version 3.0.0)

Version 3.0.0
1. New IsoTherm palette
2. Added ability to change palettes by clicking the top or bottom of the color bar
3. Added support to identify new Ethernet camera model
4. Added Camera Info window (opened by new Camera->Camera Info... menu item)
5. Application no longer displays firmware version of connected camera in main window
6. Added new Discover function for bonjour discovery of cameras from Preferences Window
7. Wifi/Network Settings tab understands Ethernet camera model and disables irrelevent controls
8. Added Help window accessed through Application->Documentation menu
9. Added ability to check for updated application automatically at startup or from Application Menu
10. Added ability to check for new tcam/tCamMini firmware versions from Camera Menu based on connected camera type
11. Enabled close button on About window
12. Main Window toolbar connect button toggles between "Connect" and "Disconnect" captions
13. Improved error message when application can't connect to camera
14. Internal changes with window management in preparation for multi-camera sessions
15. Signed Mac version with Apple developer ID

Version 2.1.1
1. Fixed, yet again, AGC display of spot meter information…*sigh*

Version 2.1.0
1. Optimize compilation and add preference item to disable bilinear interpolation if desired to increase performance on slow computers and when the image has been resized. This fixes the issue where the UI seemed frozen while streaming.
2. Add check for minimum 8-character password when setting Wifi.
3. Fix bug where spot meter info is displayed when AGC enabled on a camera with a Lepton 3.5.
4. Fixed bugs in displaying garbage metadata when exporting images from a camera with a Lepton 3.0.
5. Fixed bug where application could crash when exporting an image to a protected directory.
6. Increased the width of some labels to display fully on Linux.

Version 2.0.0
1. Added support for Lepton 3.0 (non-radiometric) in tCam-Mini
2. Resized display window to 480x320 pixels and allow resizing main window
3. Added support for Over-the-air firmware updates for tCam-Mini (FW 2.0) and tCam
4. Modified Log Window to be able to shorten any long json packet (instead of just images)
5. Added Banded, Black Hot and Sepia color palettes
6. Improved accuracy of FPS display (now based on image timestamp data)
7. Misc bug fixes

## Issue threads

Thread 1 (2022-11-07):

Proposed changes

mlpzaq9998, 2022-11-07:
core can use esp32-s3 with full usb support
Add lepton2 2.5 support

danjulio, 2022-11-09:
Thank you for the suggestions.

ESP32-S3 is very exciting chip and I will use it in the future.  However built-in USB port is very cool but cannot exist alone on a dev board because the code driving it can be deleted.  You see that in Espressif's boards - two USB connectors (native and traditional USB-UART chip connected to HW serial).  A board with a single native USB port is probably best for a dedicated device that isn't expected to have code overwritten.  I'm still trying to figure out what I would do with S3.

I'd like to provide Lepton 2/2.5 support but it would require significant changes in all code bases - having to do with resolution and spotmeter mapping - so it is a big deal, plus I don't have either core so unfortunately it's probably pretty low on the realistic priority list.  Sorry about that.

Closed 2022-11-09.

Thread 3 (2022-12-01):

Lepton CCI communication failed (I2C interface)

alejandrolri, 2022-12-01:
I´m getting 4 red blinks in my tCam-mini which means Lepton CCI communication failed (I2C interface). How can I fix this issue?

danjulio, 2022-12-01:
Probably the Lepton is loose in the socket.  Very carefully press it down into the socket.  You should hear a click as it settles into place.  If this does not work then attach the camera to a serial monitor (Arduino Serial Monitor, CoolTerm, screen or the like) at 115200 and copy the start-up log information here for me to debug.

alejandrolri, 2022-12-01:
The Lepton is loose. Problem solved. Thank you.

Closed 2022-12-01.

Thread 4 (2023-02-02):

Add length in response data

zhaocundang, 2023-02-02:
hi dan， why not add 16-bit length of  response json data ？ for example， I send requst cmd  “get_image” ，then  device reponse 0x02 ｛json length｝｛json｝0x03

danjulio, 2023-02-02:
Hello!  I think using the out-of-band delimiters allows for a more reliable stream parser.  They allow you to a) easily cut out the json string to hand to a parser and b) allow fast stream recovery in case there is data corruption (e.g. with the serial link).

I appreciate that some people use a length field followed by data but the existing OOB system works and there is already a bunch of software built around it.  Adding the length would break everything and cause me a huge amount of work so I must respectfully decline this feature request.

Regards, Dan

Closed 2023-02-02.

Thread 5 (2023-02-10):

TCAM run crash

zhaocundang, 2023-02-10:
hi, dan:
            tcam run crash sometimes , two led off,  request cmd no response,  when I press EN BUTTON it reboot run ok. so  why not add watch dog  in  code, I see no it  in your code .

zhaocundang, 2023-02-10:
two led off , TCP not connected!

Closed 2023-02-17.

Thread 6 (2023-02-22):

Desktop-App Fedora user

lambcutlet, 2023-02-22:
Hi,
Hardware, tcam-mini rev2, lepton 3.0.
I have just downloaded the latest Desktop-App Linux64_3_1_0. Running on Fedora37.
The latest firmware has been uploaded to tcam-mini.
Stream, the image for streaming is not present until i change window focus by clicking on another app. The image briefly appears and disappears. The graph on the right is active and changes when passing your hand over the lepton.
Get is similar but the image persists after changing window focus.
Tried the same setup with Windows and all works.
Is there anything i need to install in Linux for the image to appear when streaming?

danjulio, 2023-02-22:
I'm sorry you're having trouble.  Unfortunately debugging issues on Linux is very hard because of limited visibility into the mounds of software between my app and your display plus all the variation in the Linux ecosystem.  It's probably a mismatch between the Linux libraries Xojo tested with when they created the release I used to compile the program for Linux and the libraries on your Fedora 37 system.

What I can offer is to try to build you a version of the app using the latest Xojo release and see if that changes things any.

lambcutlet, 2023-02-22:
Hi Dan,
That would be great. I'd happily test it.
Thank for the very fast response.

lambcutlet, 2023-02-22:
The problem may be related to Wayland. Switching over to Xorg and streaming is now visible, however S, M1, M2, M3, M4 buttons don't seem to have a function or at least don't seem to action anything. FFC does work.
Also no temperature value appears in the area above the streaming window. I see RAW at the bottom of the colour scale.  Is this to do with using a Lepton 3.0?
fps updates at about 8.8fps.

danjulio, 2023-02-22:
I don't think Xojo tests with Wayland.   But I'll still try to build a test version with the latest release.  Might take a day or two.

The Lepton 3.0 does not generate radiometric data so all functions related to that, including the spot meter and markers, are disabled in the application.  The "RAW" indicator indicates this is just raw data from the bolometer that the app is scaling and colorizing.  Answering this issue makes me realize I never tested what happens with the graph.  It might be completely bonkers.

FPS of 8.8 is the maximum the Lepton is capable of so that's good.

lambcutlet, 2023-02-22:
Looking at the Xojo forums it does appear that it doesn't play nice with Wayland.
Thanks for the clarity on S, M1, etc.
Switching from RAW to AGC doesn't change the S, M1, etc. button functions either. I get it, the Lepton 3.0 is not radiometric.
OK I'll wait in anticipation to test the latest Xojo version. But at least I know your program works in Xorg which i can live with if Xojo is still not happy.

danjulio, 2023-02-23:
Yes, it seems Wayland isn't supported.  I guess a completely different rendering model than old-school X11.  There must be some backward compatibility support but perhaps it has some issues.

https://documentation.xojo.com/resources/system_requirements_for_current_release.html

Enclosed is a build using Xojo 2022 Release 4.  I don't expect it to work for you but you can check it out.

[tcam_linux86_3_1_1.zip](https://github.com/danjulio/tCam/files/10809605/tcam_linux86_3_1_1.zip)

lambcutlet, 2023-02-23:
Hi, I tested the code on Wayland and it behaves in the same manner as before.
Thankyou for trying.
You may close this issue and I'll wait until Xojo catches up with Wayland. Some time in the future :).

Closed 2023-02-24.

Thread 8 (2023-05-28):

Enclosure errors

zharijs, 2023-05-28:
tCam-mini v4 boards from Digikey does not fit the enclosure correctly. Both - USB connector and sensor holes have a gross offset.

danjulio, 2023-05-29:
What specific STL files did you use?  There are files also for the v2 boards and Zeke's enclosure was also for v2.  The v4 files have been printed successfully quite a lot...

zharijs, 2023-05-29:
I made my own, but took these as base for hole locations:
https://github.com/danjulio/tCam/tree/main/tCam-Mini/enclosure/tcam_mini_basic/tcam_mini_basic

To be honest, I might have used the "bezel" file in 180 degree rotation. Not sure about that. But still, USB hole seems to be 1mm offset.

Anyway - you can add link or just copy my files to your repo. Just tested - all holes in place and it's GoPro compatible. Also has STEP and original Rhino project:

https://github.com/zharijs/Enclosures/tree/main/tCam%20enclosure

H.

danjulio, 2023-07-10:
Harry,

I finally had a minute and I updated the repo and hackaday.io project entry to show off your fantastic enclosures and give you a shout-out.  Much better than mine.  Thank you so much for sharing these.

Regards, Dan

zharijs, 2023-09-26:
Glad to give back to community :)

Closed 2023-06-21.

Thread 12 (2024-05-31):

Windows Desktop App - Discovery of Camera not working on my system.

malansk, 2024-05-31:
With the default configuration of the tcam-mini as Access Point, I can connect to the camera and change "Camera Settings / WiFi" to disable AP mode and set SSID and PW of my WiFi network.

"Preferences / Discover" in the Windows Desktop App however does not find a camera (the small circle animation runs for approx. 12s but no result).

I have "Bonjour" installed and also tried the provided "Bonjour SDK" as well as running the Desktop App in Administrator mode to no avail.

If look in my routers network device list for the ESPRESSIF device IP address and put that manually in the app then the camera is working.

By the way, the Android app is able to discover the camera.

danjulio, 2024-06-03:
Sorry you're having this trouble.  Are you running Windows 11?  I did some googling and it appears something Windows 11 does stops Bonjour.  I am no expert in anything windows but maybe start up Services and look to see if Bonjour is running.  According to the links I read you might be able to start it there.  Here are a couple of pages in Microsoft forums that talk about this

https://answers.microsoft.com/en-us/windows/forum/all/bonjour-service-being-disabled-and-not-starting-in/503b37b8-5146-4339-9418-74e7a81e7e72

https://answers.microsoft.com/en-us/windows/forum/all/windows-11-disabling-bonjour/4e6a8a12-a715-46c2-8ce6-1eaef57da888

If it does have to do with some incompatibility with Windows 11 then, unfortunately, there is probably little I - a lowly app developer, caught between titans - can do to fix this.  Sorry I don't have a better answer.  Let me know what you find in Services.

malansk, 2024-06-05:
Im am running Microsoft Windows [Version 10.0.19045.4412]
Windows 10 Home 64-Bit Version running on Intel i7-6700 with 8GB Ram
I will look for the service status in a few days when I'm back at home.

malansk, 2024-06-27:
I can confirm it was an issue with the Bonjour Service, after Restart Discovery was working.

Closed 2024-06-27.

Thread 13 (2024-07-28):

Red LED always on and tCam will not start up after charging. Dead EFM8SB20F32G?

dudeitssm, 2024-07-28:
Hi Dan.

I was using my tCam normally. Once the battery ran low, I shut down the tCam. At this point, the LED was off.
When I plugged it into my USB-C charger, the red LED came on, and I went on with my day.
This is the charger I have used many times before without issues: a [DeWalt 65W USB-C charger](https://www.homedepot.com/p/DEWALT-20V-MAX-Charger-and-USBC-Adaptor-Kit-DCB094K/318666174).

After a couple hours, I checked up on it and the red LED was still on.
I unplugged it from the charger and... the red LED still remained lit.

I pressed the power button and it wouldn't start up.
I pressed and held the power button for over 1 minute and it still would not start up, and the red LED remains lit.

Looking through the [gcore schematic](https://github.com/danjulio/gCore/blob/main/Documentation/Documents/gCore_schem.pdf), it seems the LEDs are controlled by the EFM8SB20F32G. I could be mistaken though -- my second guess would be the ESP32 has died.

I would open up the tcam and probe it for troubleshooting, but unfortunately, I do not have the tiny allen key required to open it. I will order a set online so I can in a few days.

Any pointers would be appreciated in the mean time.
Thank you!

danjulio, 2024-07-28:
Probably what happened was that the EFM8 crashed or hung-up.  So, unfortunately, you will have to disassemble it to disconnect and then reconnect the battery to reset it.  You can leave it plugged in to the charger to prevent the battery from being over-discharged as the actual charger is a separate IC.

When it’s up and running check to see what version of firmware the EFM8 is running (under the Settings/Info button you’ll see RTC/PMIC version).  You might update the firmware if it is running version 1.1 (there are instructions how at the link below).

https://github.com/danjulio/gCore/tree/main/Firmware <https://github.com/danjulio/gCore/tree/main/Firmware>

Let me know if you have any other questions.

Regards, Dan

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

dudeitssm, 2024-07-28:
Thank you, Dan.

I will let you know once I have the allen keys to disassemble and disconnect/reconnect the battery.

dudeitssm, 2024-08-02:
Yup, disconnecting and reconnecting the battery revived the tcam. That's a relief.

In case anyone is curious, here's the version info:

```
FW Version: 0.20
SDK Version: v4.4.4-268-ge47aaa7088
tCam-Mini Version: 3.1
RTC/PMIC Version: 1.1
```

danjulio, 2024-08-02:
I’m glad that fixed it for you!

I have a question for you if you don’t mind: Was tCam on or off when the EFM8 locked up?

I released version 1.2 of the firmware for the EFM8 (RTC/PMIC). Mainly it fixed some issues that slowed down the RTC but it also fixed a potential lock-up.  However I think that lock-up required the ESP32 to be accessing the EFM8 via the I2C bus.  You can use a dev board like a ESP32, Teensy or RP2040 programmed via the Arduino IDE to load it if you want.  Instructions are in the firmware subdirectory of the repo.

Otherwise there might still be some rare bug lurking in that code.

Regards, Dan

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

dudeitssm, 2024-08-02:
Hi Dan.

> I have a question for you if you don’t mind: Was tCam on or off when the EFM8 locked up?

I turned the tcam off before charging.

I'll think about flashing the updated PMIC firmware at another time. Especially since this problem seems to appear once in a blue moon (first time in, eh, 2 years or so?).

The [instructions](https://github.com/danjulio/gCore/tree/main/Firmware#local-firmware-update) provided are easy to follow (to those familiar with hardware flashing, which I am).

Thanks again :+1:

Closed 2024-07-28.

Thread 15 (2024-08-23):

Disable ETH

yevhenboichuk, 2024-08-23:
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
I use esp32 devkit (4MB flash), how can i disable eth, and use only WiFi(i use firmware tCam-mini)

danjulio, 2024-08-23:
Check GPIO2.  It must be left floating so a pull-up can pull it high.  The firmware supports two board types: tCam-Mini and tCam-Eth.  It uses GPIO2 to select the board type.  When it thinks it is running on tCam-Eth it will try to initialize the ethernet driver which will fail as you see if there is no ethernet.   You want the firmware to think it is running on a tCam-Mini board.

You can look at the tCam-Mini schematics or the firmware/main/system_config.h file to see what the connections should be.

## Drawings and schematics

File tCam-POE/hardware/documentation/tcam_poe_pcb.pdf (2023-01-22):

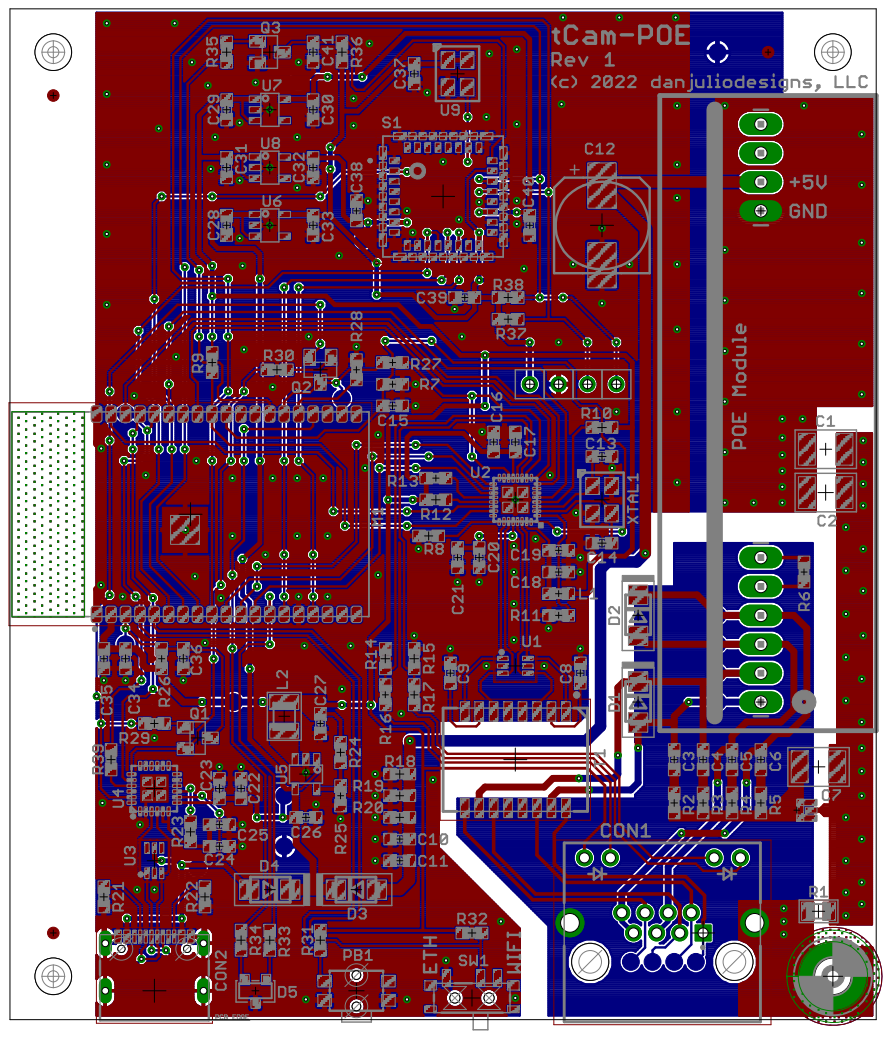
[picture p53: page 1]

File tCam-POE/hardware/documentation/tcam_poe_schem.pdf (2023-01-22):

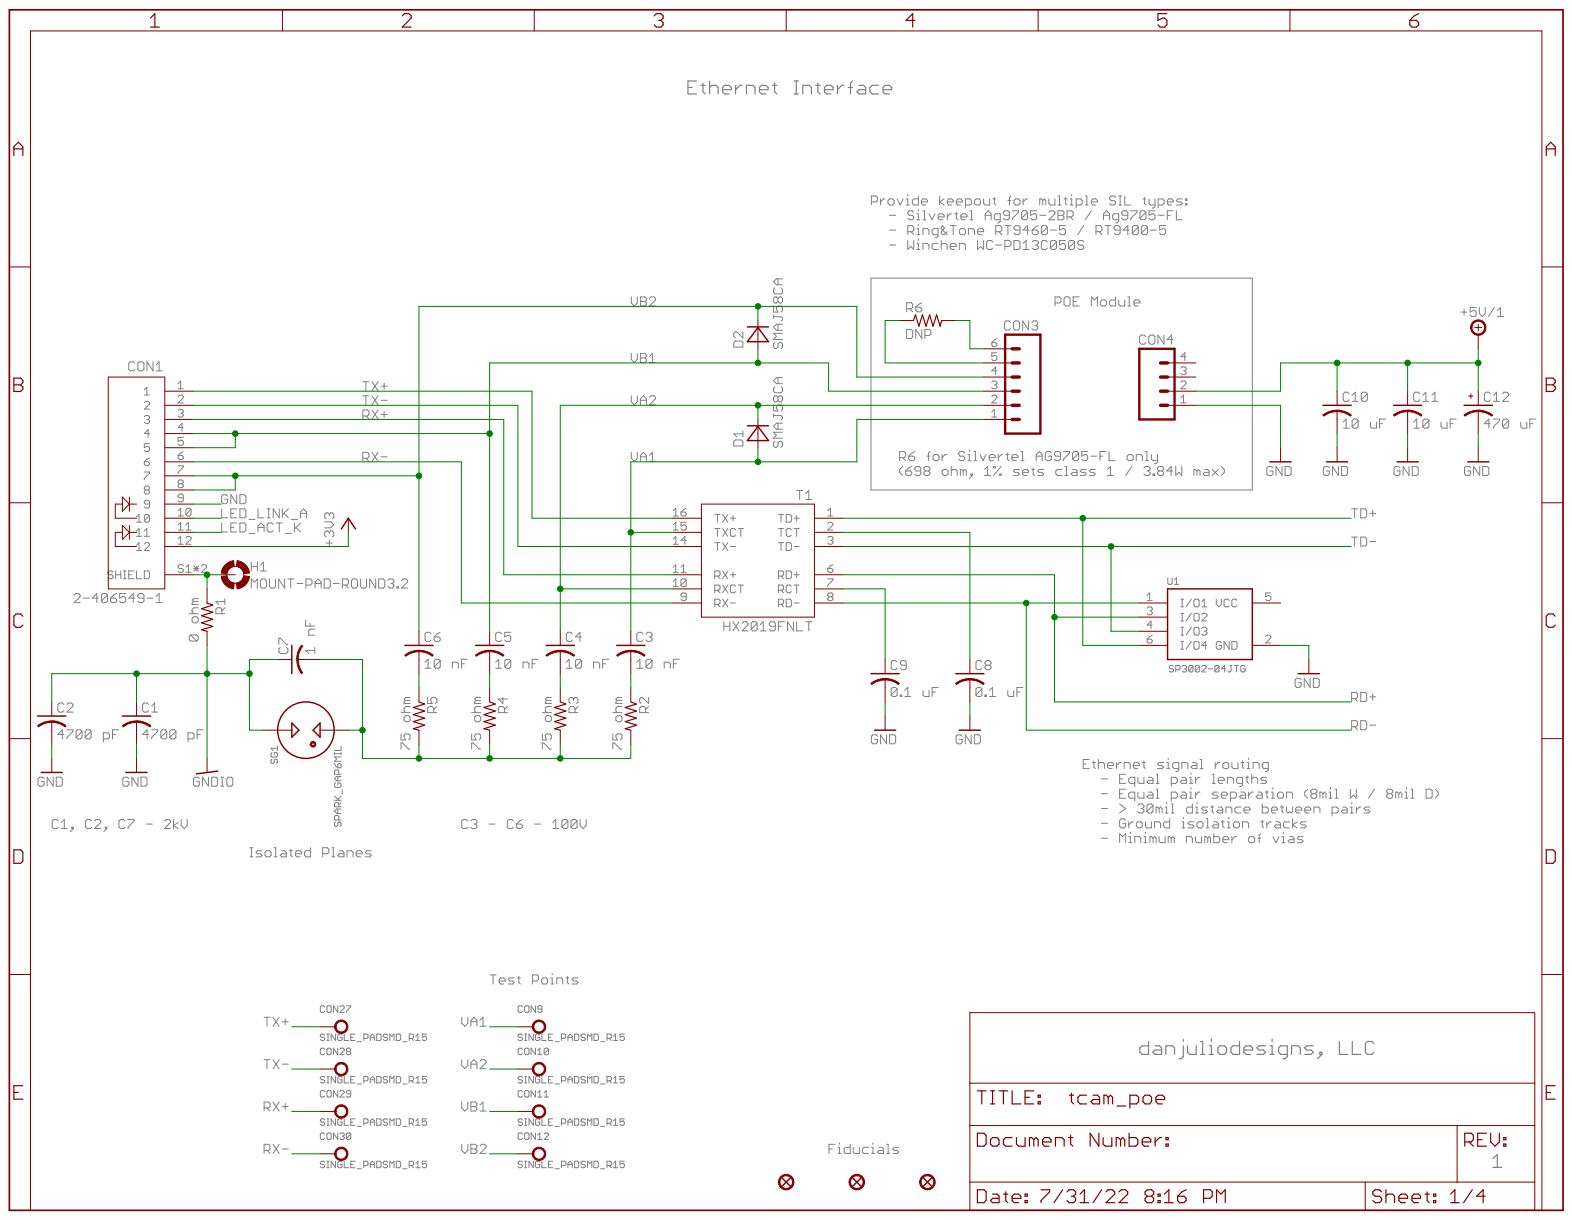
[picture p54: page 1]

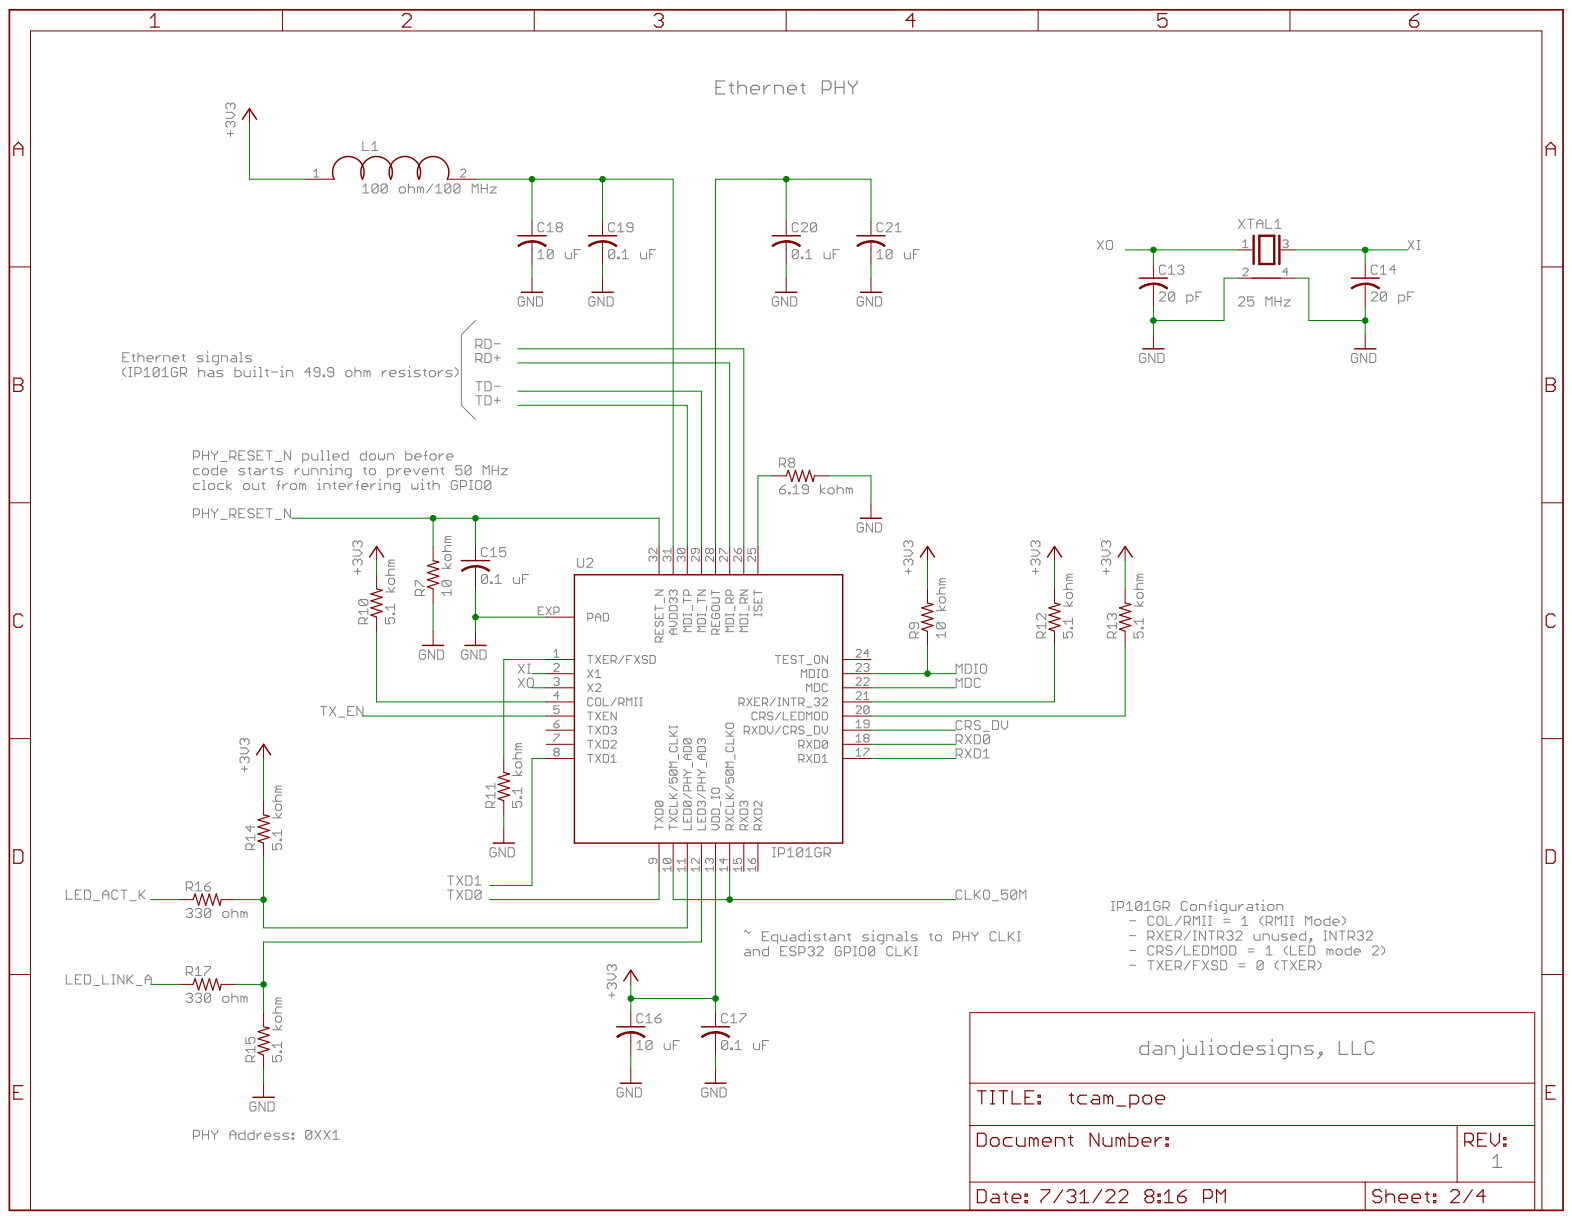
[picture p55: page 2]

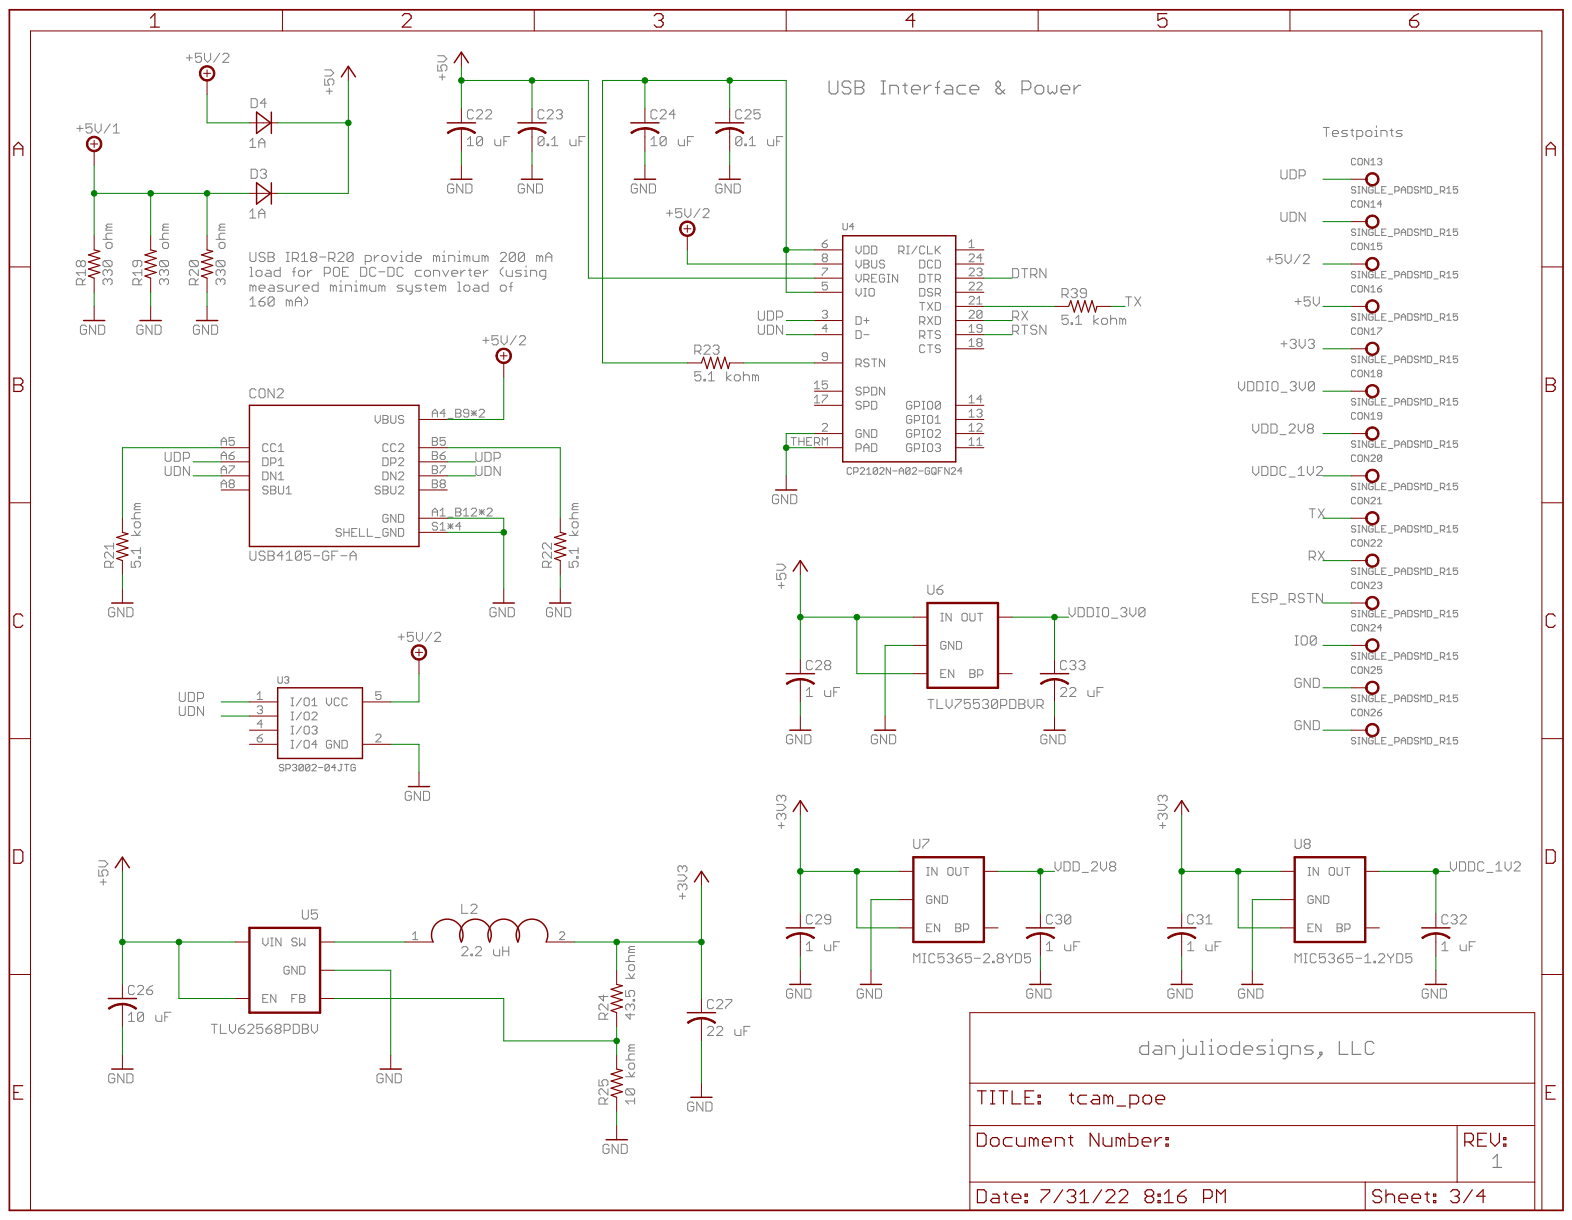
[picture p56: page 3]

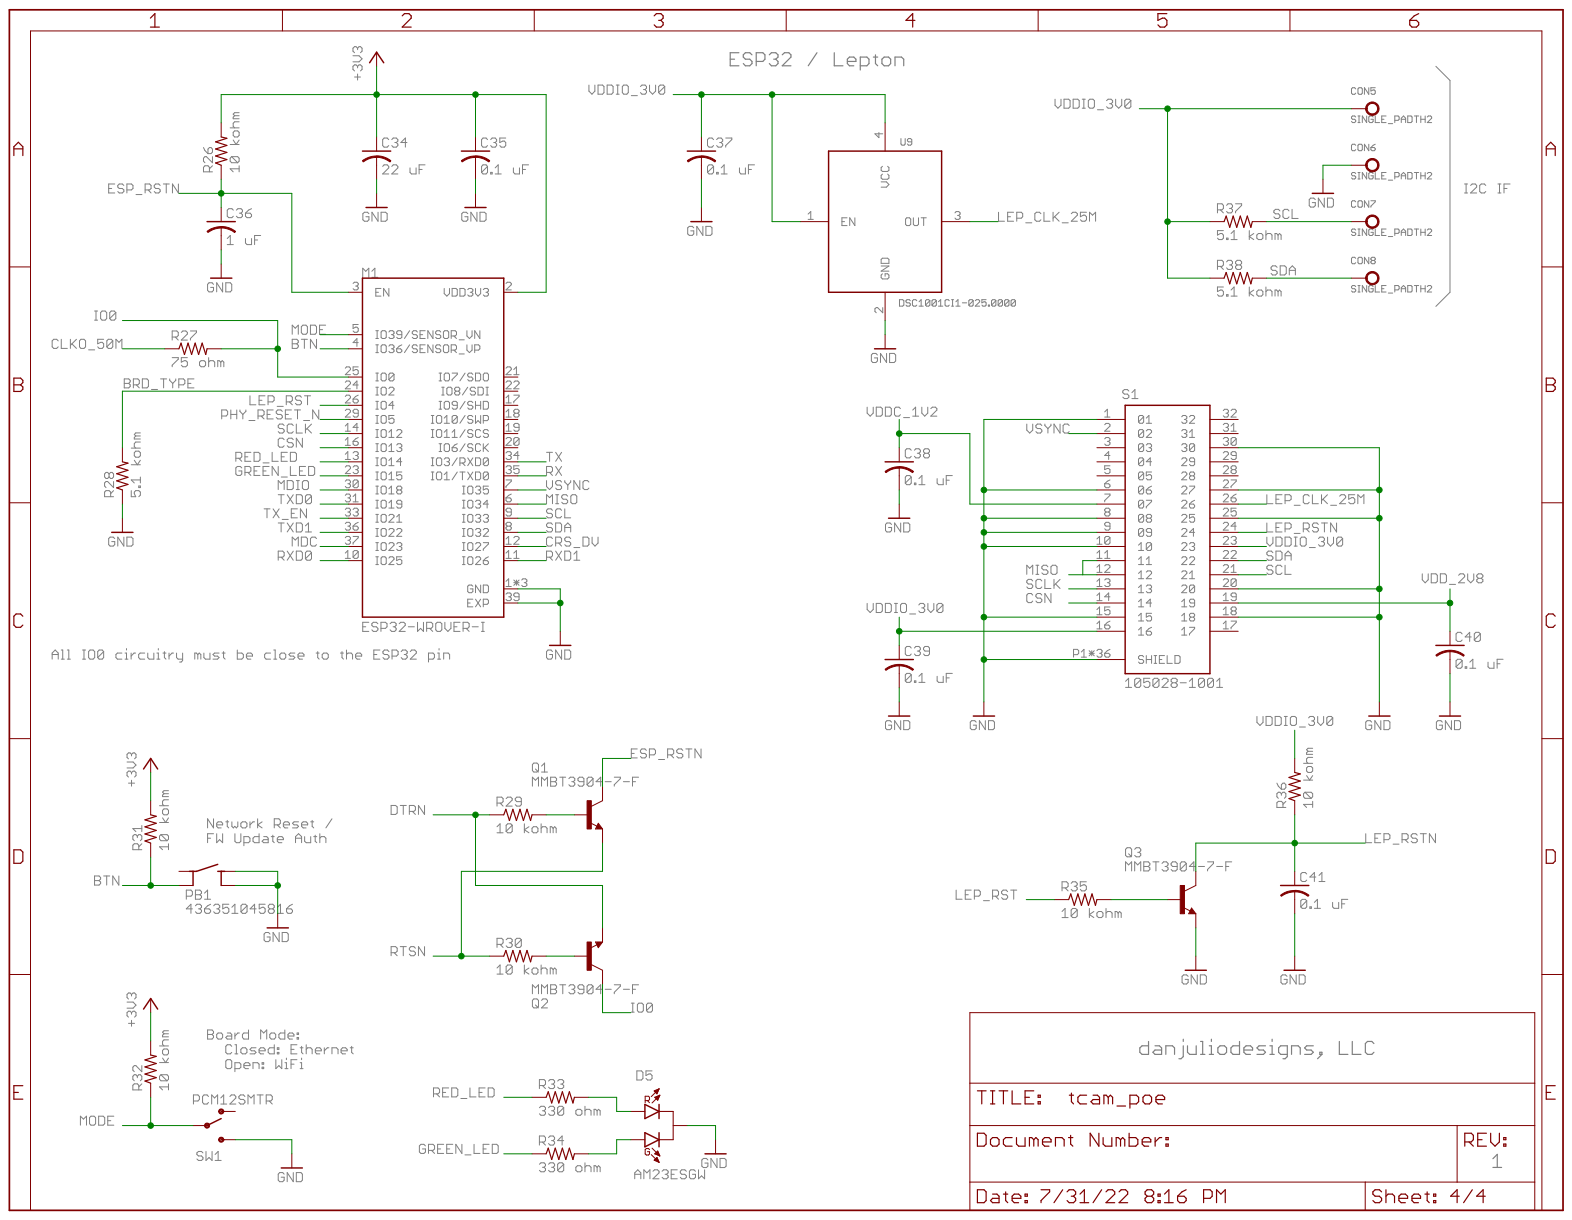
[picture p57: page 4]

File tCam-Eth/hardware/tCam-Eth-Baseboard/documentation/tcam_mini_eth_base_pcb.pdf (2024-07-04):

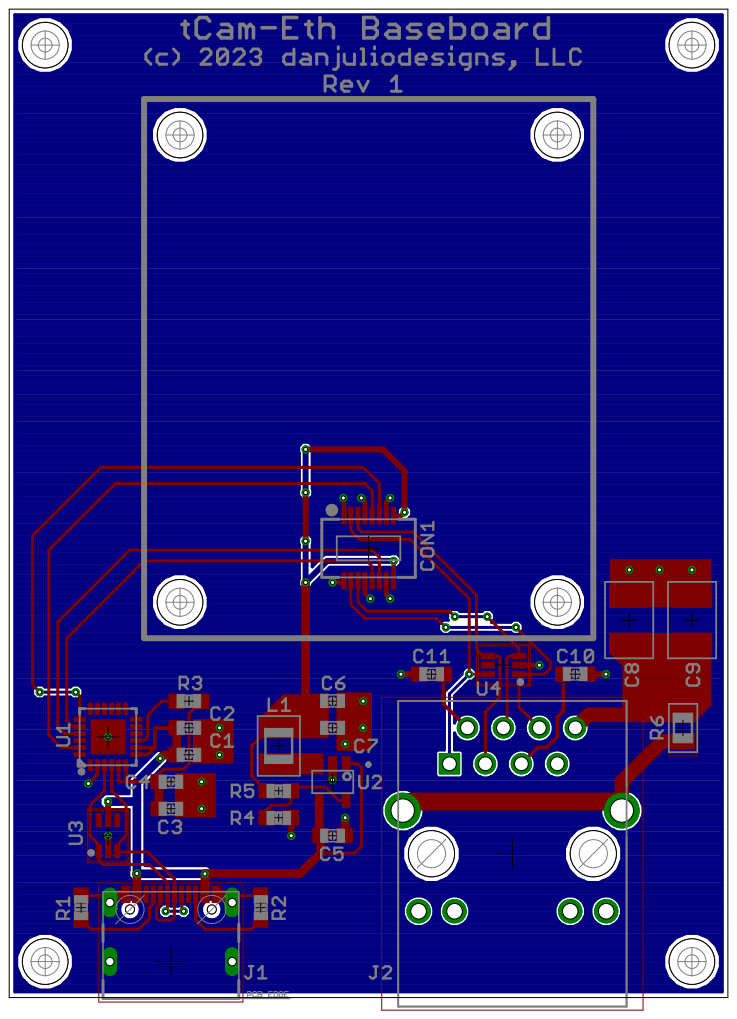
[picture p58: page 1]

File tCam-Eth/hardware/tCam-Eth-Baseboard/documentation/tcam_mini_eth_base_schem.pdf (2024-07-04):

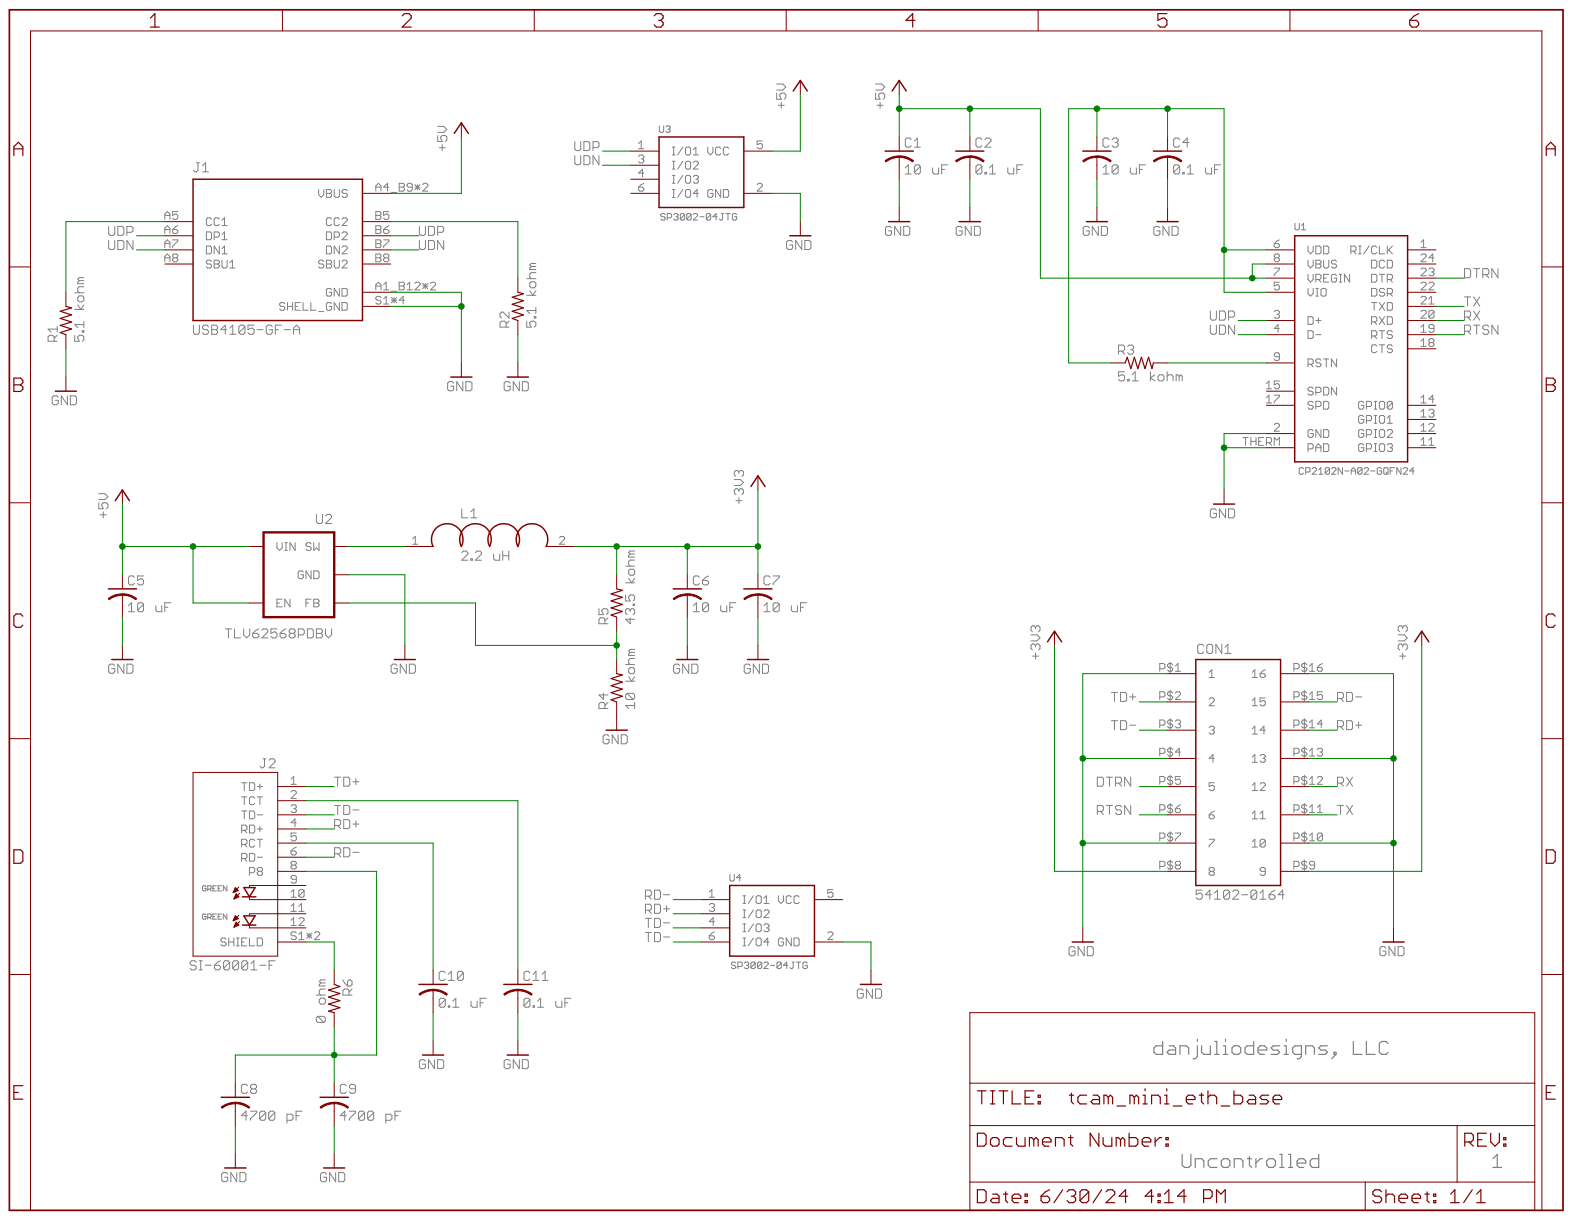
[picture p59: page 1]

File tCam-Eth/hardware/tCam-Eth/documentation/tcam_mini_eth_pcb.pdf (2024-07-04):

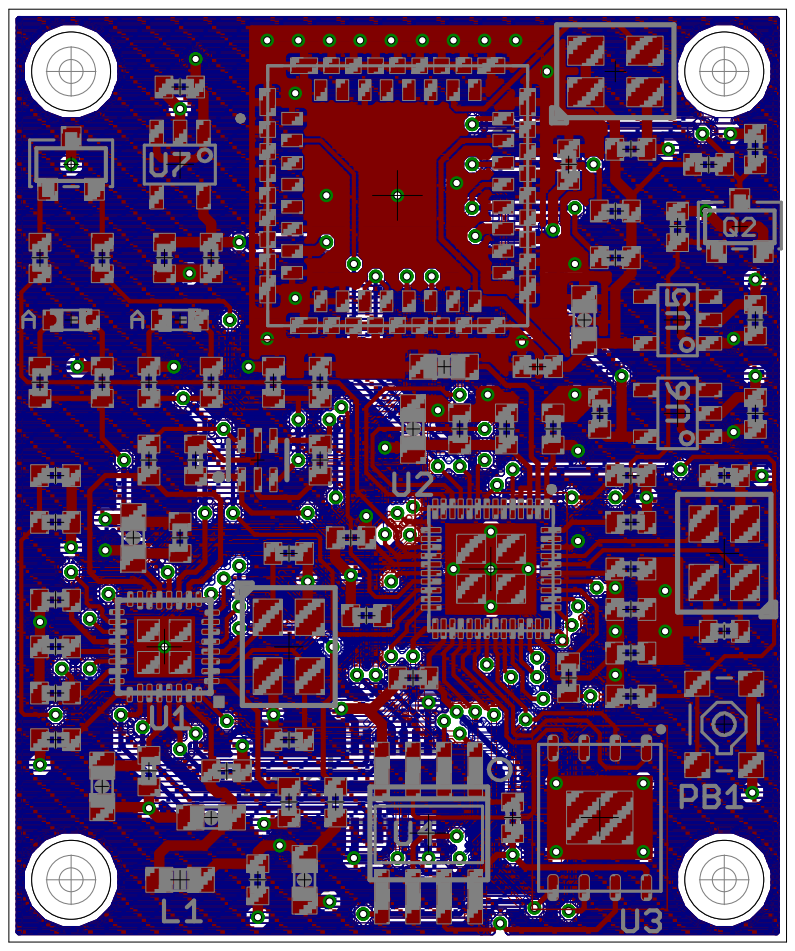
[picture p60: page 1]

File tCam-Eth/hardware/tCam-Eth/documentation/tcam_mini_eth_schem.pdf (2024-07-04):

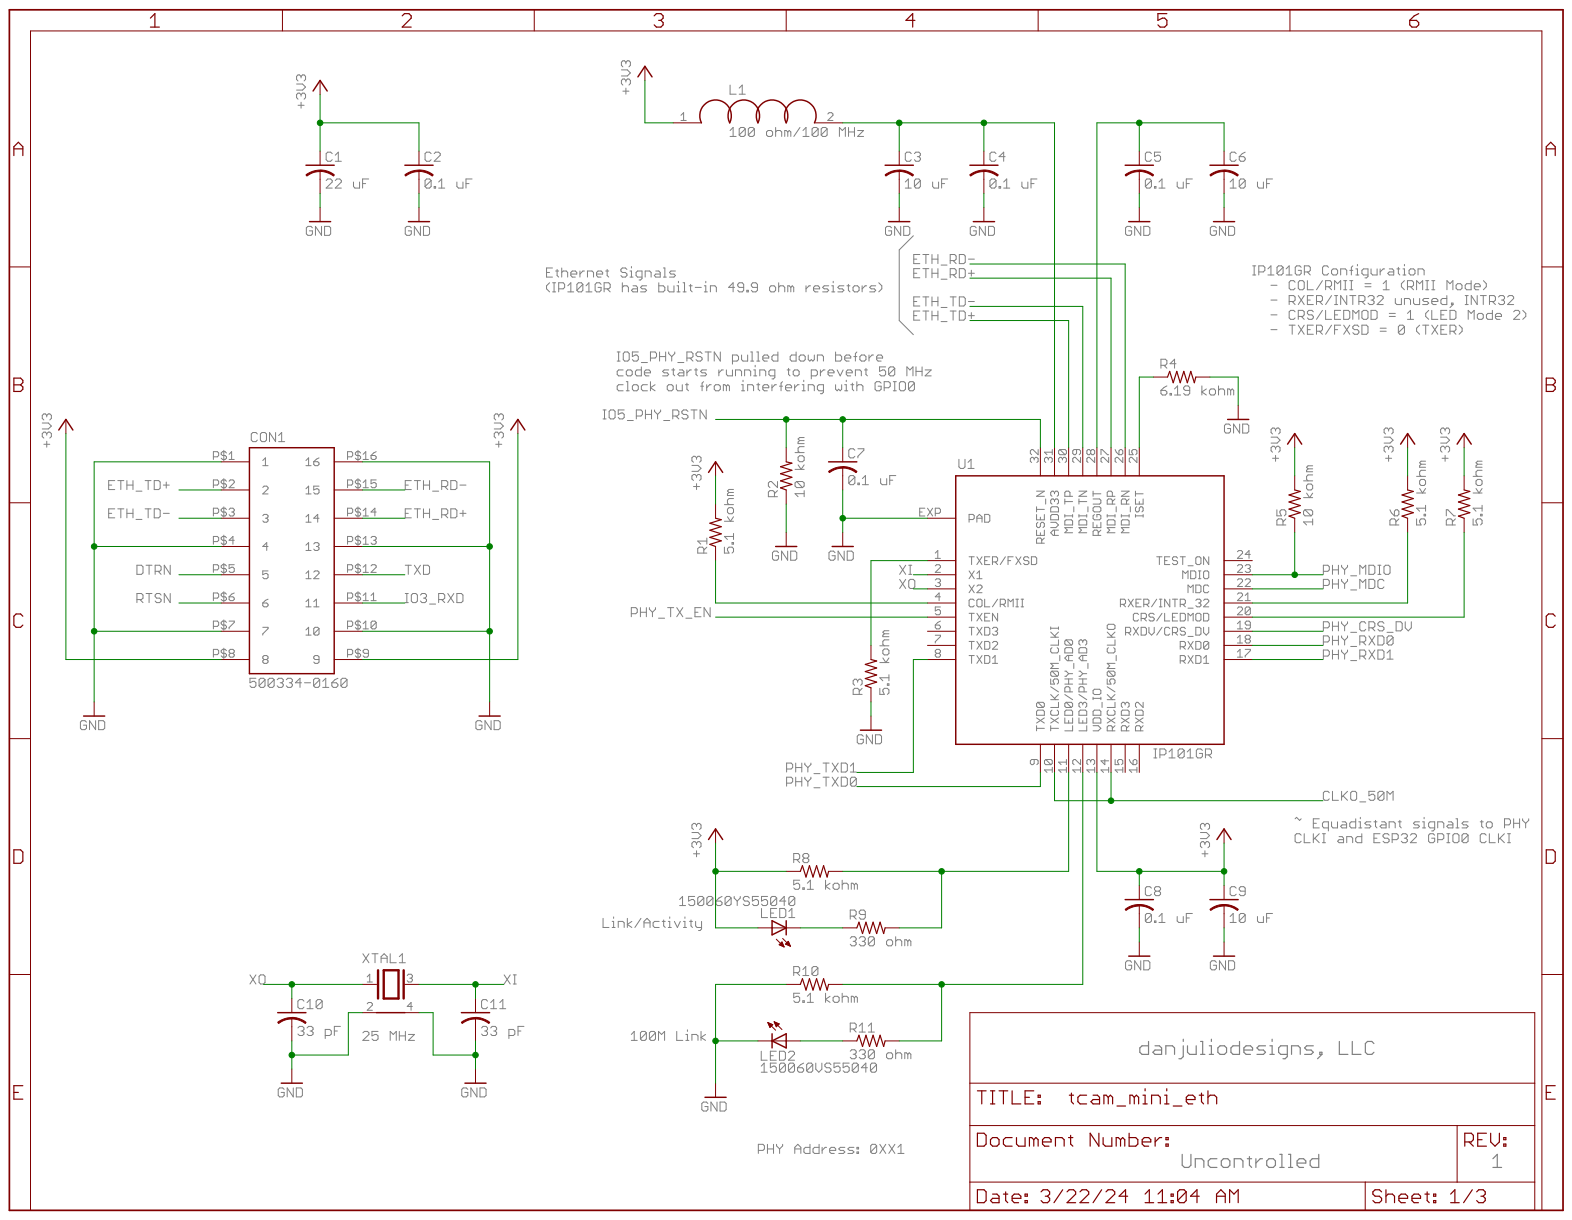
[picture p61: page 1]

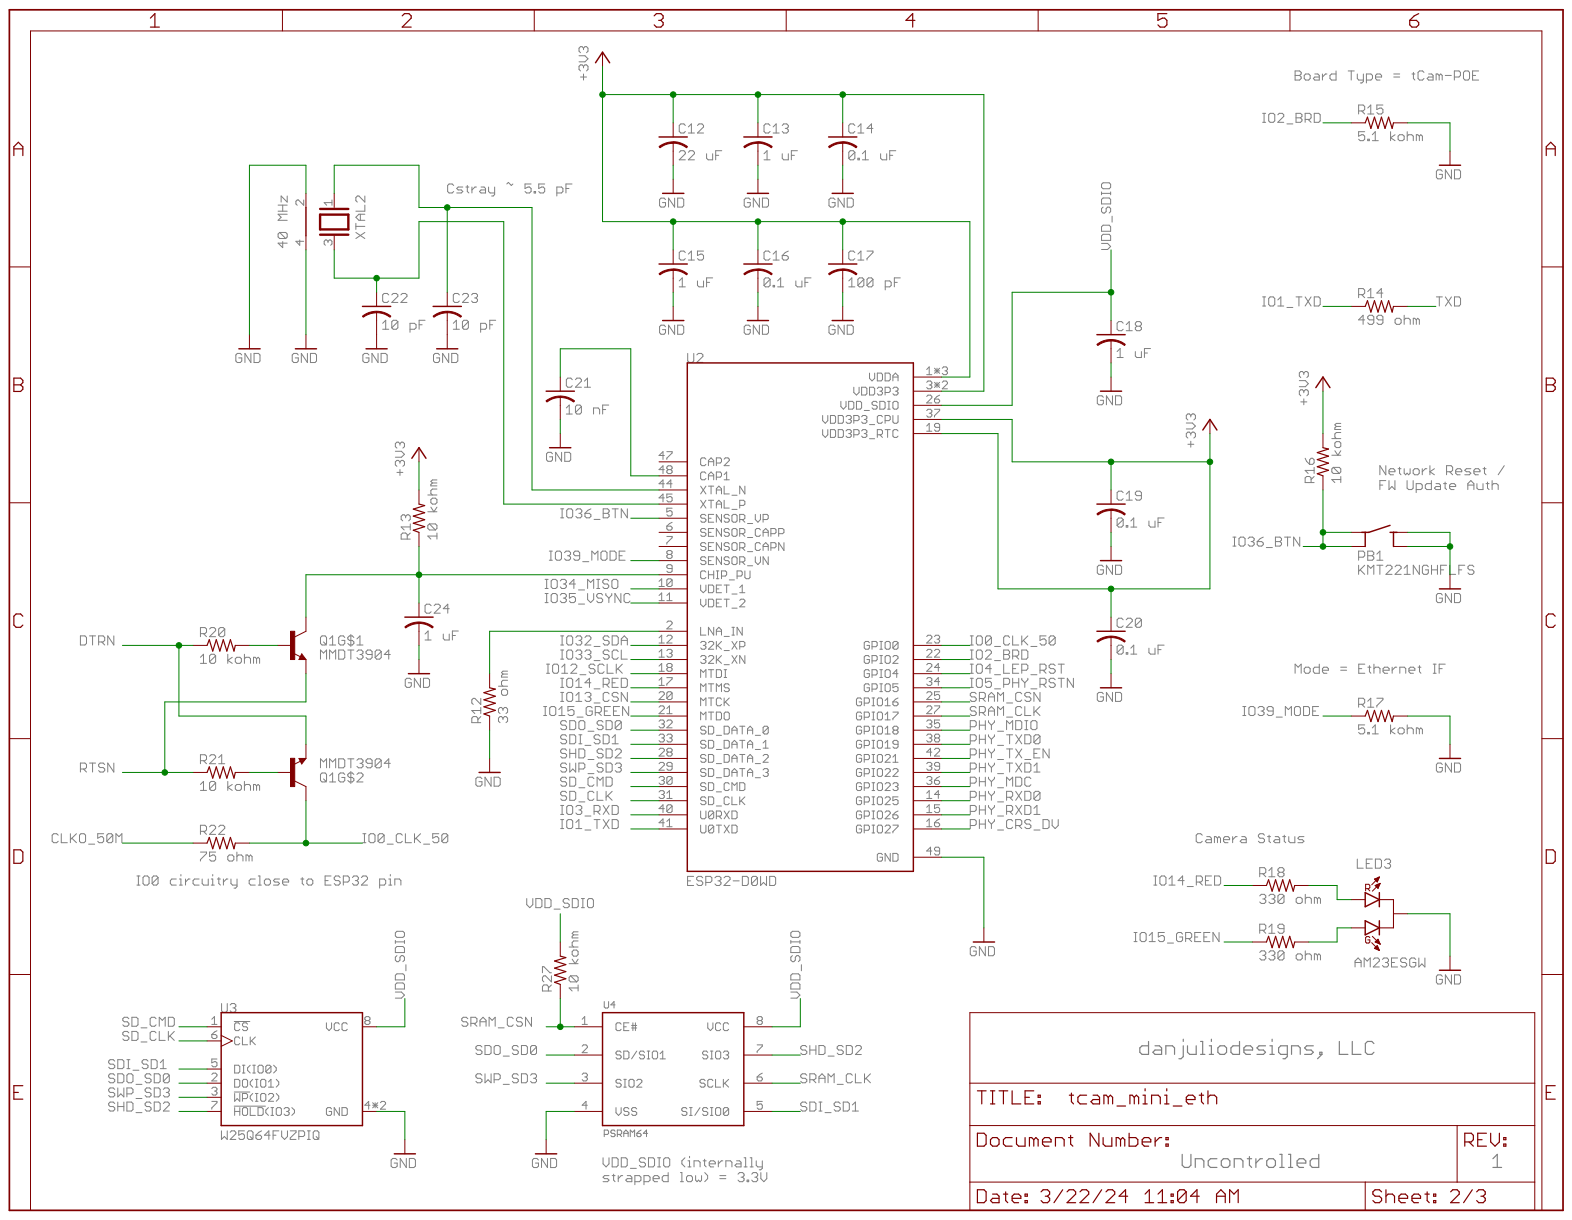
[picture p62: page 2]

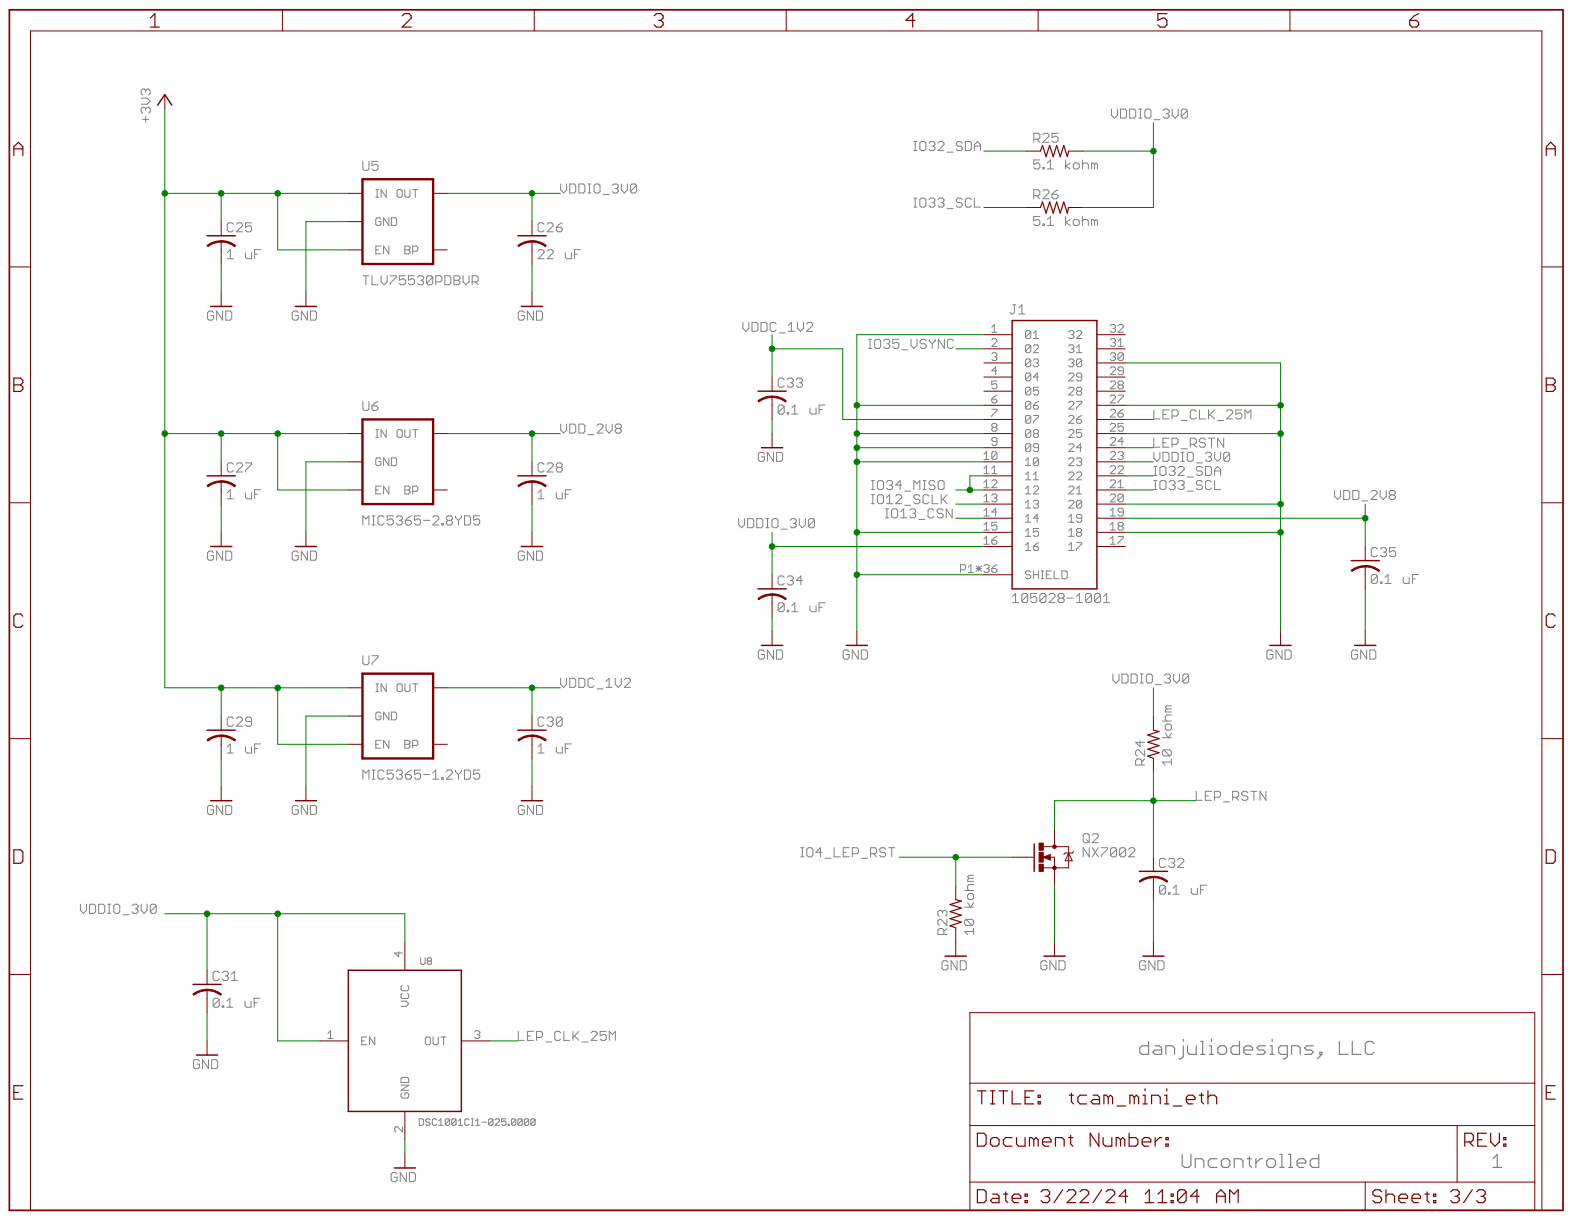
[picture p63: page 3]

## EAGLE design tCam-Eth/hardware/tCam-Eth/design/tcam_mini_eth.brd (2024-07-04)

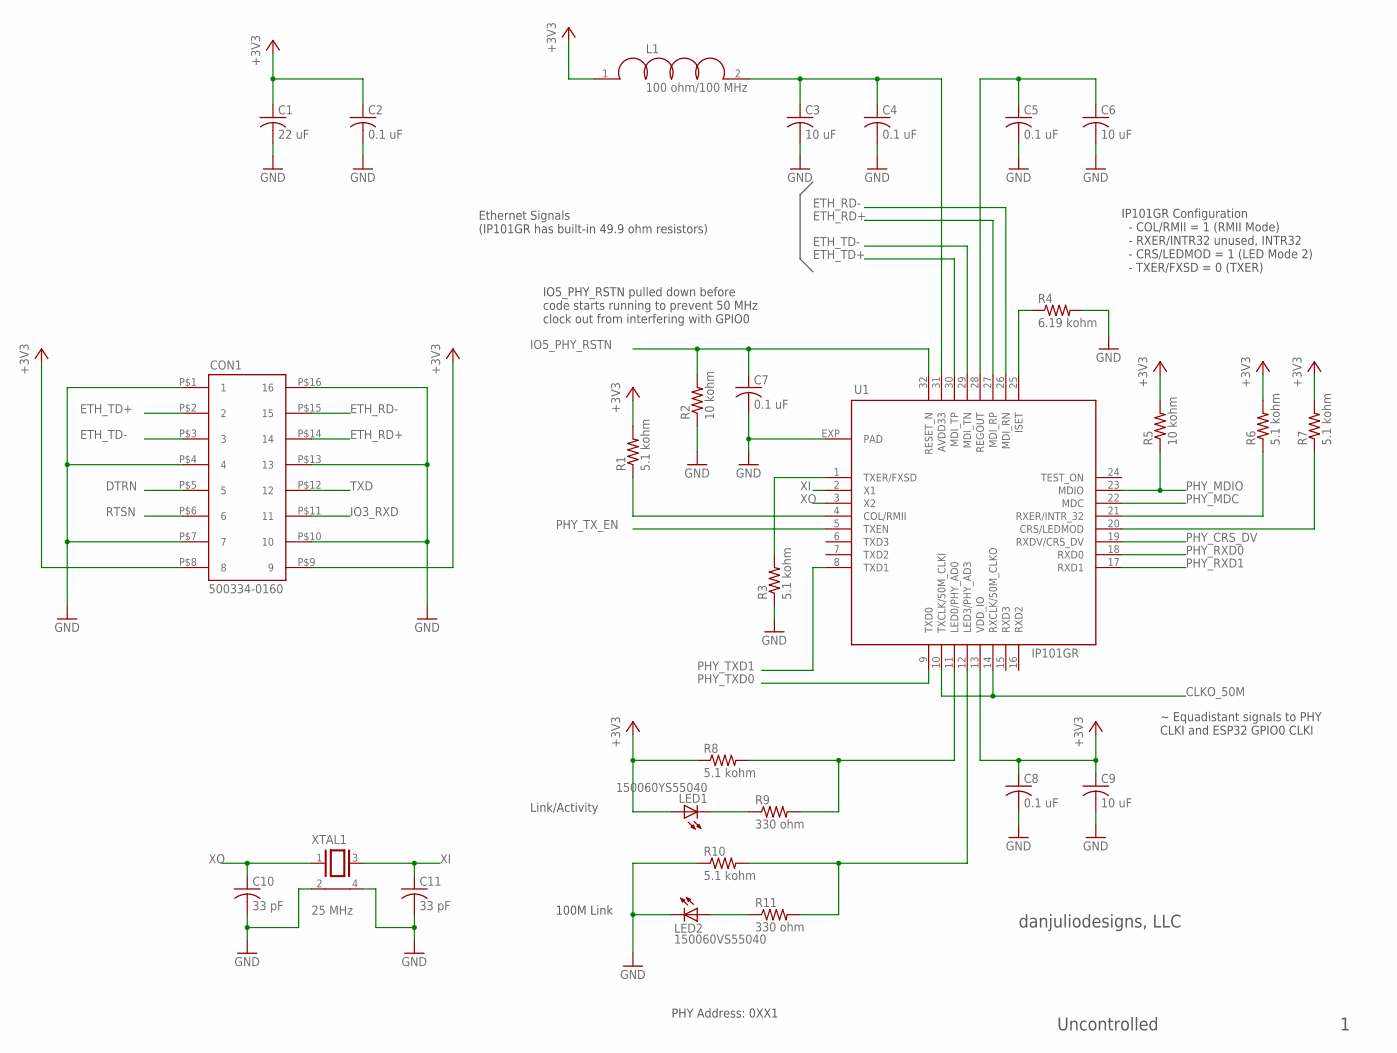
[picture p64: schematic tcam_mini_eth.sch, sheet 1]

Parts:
C1: 22 uF; C0603
C2, C4, C5, C7, C8: 0.1 uF; C0402
C3, C6, C9: 10 uF; C0603
C10, C11: 33 pF; C0402
CON1: 500334-0160; MOLEX_500334_0160
L1: 100 ohm/100 MHz; L0603
LED1: 150060YS55040; CHIPLED_0603
LED2: 150060VS55040; CHIPLED_0603
R1, R3, R6, R7, R8, R10: 5.1 kohm; R0402
R2, R5: 10 kohm; R0402
R4: 6.19 kohm; R0402
R9, R11: 330 ohm; R0402
U1: IP101GR; QFN32_4X4
XTAL1: 25 MHz; CRYSTAL-3225

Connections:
+3V3: C1.1, C2.1, C8.1, C9.1, CON1.P$8 (8), CON1.P$9 (9), L1.1, LED1.A, R1.2, R5.2, R6.2, R7.2, R8.1, U1.13 (VDD_IO); also elsewhere on the board
CLKO_50M: U1.10 (TXCLK/50M_CLKI), U1.14 (RXCLK/50M_CLKO); also elsewhere on the board
DTRN: CON1.P$5 (5); also elsewhere on the board
ETH_RD+: CON1.P$14 (14), U1.27 (MDI_RP)
ETH_RD-: CON1.P$15 (15), U1.26 (MDI_RN)
ETH_TD+: CON1.P$2 (2), U1.30 (MDI_TP)
ETH_TD-: CON1.P$3 (3), U1.29 (MDI_TN)
GND: C1.2, C2.2, C3.2, C4.2, C5.2, C6.2, C7.2, C8.2, C9.2, C10.2, C11.2, CON1.P$1 (1), CON1.P$4 (4), CON1.P$7 (7), CON1.P$10 (10), CON1.P$13 (13), CON1.P$16 (16), LED2.C, R2.1, R3.1, R4.2, R10.1, U1.EXP (PAD), XTAL1.2, XTAL1.4; also elsewhere on the board
IO3_RXD: CON1.P$11 (11); also elsewhere on the board
IO5_PHY_RSTN: C7.1, R2.2, U1.32 (RESET_N); also elsewhere on the board
unnamed: C3.1, C4.1, L1.2, U1.31 (AVDD33)
unnamed: R4.1, U1.25 (ISET)
unnamed: R6.1, U1.21 (RXER/INTR_32)
unnamed: R1.1, U1.4 (COL/RMII)
unnamed: R3.2, U1.1 (TXER/FXSD)
unnamed: R7.1, U1.20 (CRS/LEDMOD)
unnamed: R8.2, R9.2, U1.11 (LED0/PHY_AD0)
unnamed: R10.2, R11.2, U1.12 (LED3/PHY_AD3)
unnamed: LED2.A, R11.1
unnamed: LED1.C, R9.1
PHY_CRS_DV: U1.19 (RXDV/CRS_DV); also elsewhere on the board
PHY_MDC: U1.22 (MDC); also elsewhere on the board
PHY_MDIO: R5.1, U1.23 (MDIO); also elsewhere on the board
PHY_RXD0: U1.18 (RXD0); also elsewhere on the board
PHY_RXD1: U1.17 (RXD1); also elsewhere on the board
PHY_TXD0: U1.9 (TXD0); also elsewhere on the board
PHY_TXD1: U1.8 (TXD1); also elsewhere on the board
PHY_TX_EN: U1.5 (TXEN); also elsewhere on the board
REGOUT: C5.1, C6.1, U1.28 (REGOUT)
RTSN: CON1.P$6 (6); also elsewhere on the board
TXD: CON1.P$12 (12); also elsewhere on the board
XI: C11.1, U1.2 (X1), XTAL1.3
XO: C10.1, U1.3 (X2), XTAL1.1

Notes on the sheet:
IO5_PHY_RSTN pulled down before code starts running to prevent 50 MHz clock out from interfering with GPIO0
Ethernet Signals (IP101GR has built-in 49.9 ohm resistors)
~ Equadistant signals to PHY CLKI and ESP32 GPIO0 CLKI
IP101GR Configuration - COL/RMII = 1 (RMII Mode) - RXER/INTR32 unused, INTR32 - CRS/LEDMOD = 1 (LED Mode 2) - TXER/FXSD = 0 (TXER)
PHY Address: 0XX1
100M Link
Link/Activity
danjuliodesigns, LLC
Uncontrolled

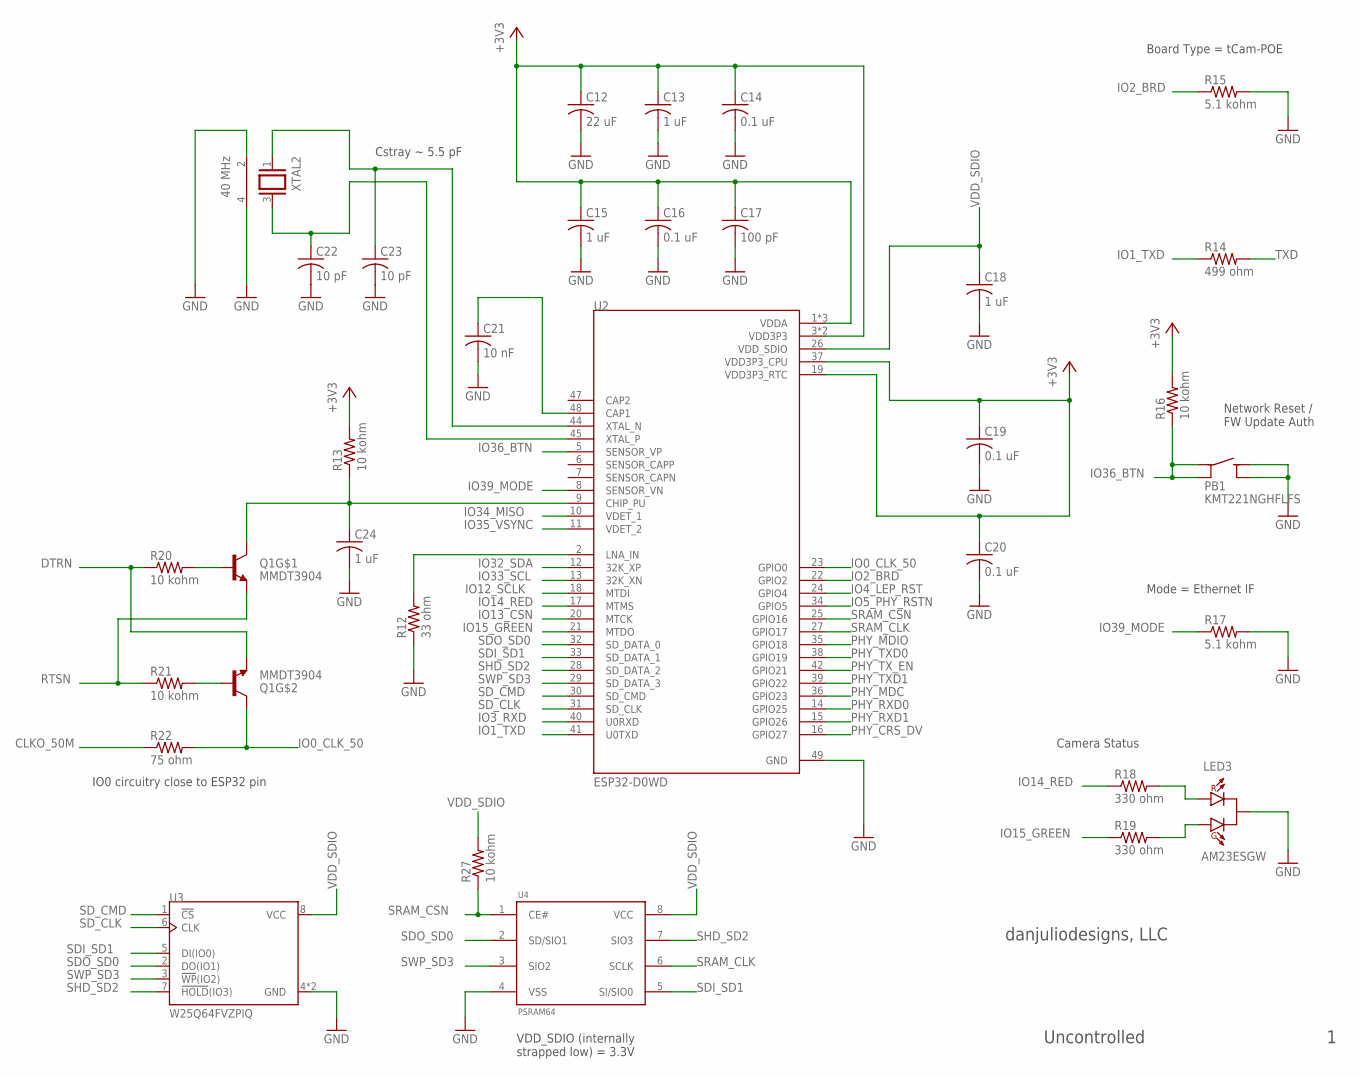
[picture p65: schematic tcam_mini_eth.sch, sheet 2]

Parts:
C12: 22 uF; C0603
C13, C15, C18, C24: 1 uF; C0402
C14, C16, C19, C20: 0.1 uF; C0402
C17: 100 pF; C0402
C21: 10 nF; C0402
C22, C23: 10 pF; C0402
LED3: AM23ESGW; SOT23-3
PB1: KMT221NGHFLFS; CK_KMT2
Q1: MMDT3904; SOT363
R12: 33 ohm; R0603
R13, R16, R20, R21, R27: 10 kohm; R0402
R14: 499 ohm; R0402
R15, R17: 5.1 kohm; R0402
R18, R19: 330 ohm; R0402
R22: 75 ohm; R0402
U2: ESP32-D0WD; QFN35P500X500X90-49N
U3: W25Q64FVZPIQ; SON127P600X500X80-9N
U4: PSRAM64; SO8
XTAL2: 40 MHz; CRYSTAL-3225

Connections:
+3V3: C12.1, C13.1, C14.1, C15.1, C16.1, C17.1, C19.1, C20.1, R13.2, R16.2, U2.1 (VDDA), U2.3 (VDD3P3), U2.4 (VDD3P3), U2.19 (VDD3P3_RTC), U2.37 (VDD3P3_CPU), U2.43 (VDDA), U2.46 (VDDA); also elsewhere on the board
CLKO_50M: R22.1; also elsewhere on the board
DTRN: Q1.1 (E), R20.1; also elsewhere on the board
GND: C12.2, C13.2, C14.2, C15.2, C16.2, C17.2, C18.2, C19.2, C20.2, C21.2, C22.2, C23.2, C24.2, LED3.3 (C), PB1.3, PB1.4, R12.1, R15.2, R17.2, U2.49 (GND), U3.4 (GND), U3.9 (GND), U4.4 (VSS), XTAL2.2, XTAL2.4; also elsewhere on the board
IO0_CLK_50: Q1.6 (C), R22.2, U2.23 (GPIO0)
IO1_TXD: R14.1, U2.41 (U0TXD)
IO2_BRD: R15.1, U2.22 (GPIO2)
IO3_RXD: U2.40 (U0RXD); also elsewhere on the board
IO4_LEP_RST: U2.24 (GPIO4); also elsewhere on the board
IO5_PHY_RSTN: U2.34 (GPIO5); also elsewhere on the board
IO12_SCLK: U2.18 (MTDI); also elsewhere on the board
IO13_CSN: U2.20 (MTCK); also elsewhere on the board
IO14_RED: R18.1, U2.17 (MTMS)
IO15_GREEN: R19.1, U2.21 (MTDO)
IO32_SDA: U2.12 (32K_XP); also elsewhere on the board
IO33_SCL: U2.13 (32K_XN); also elsewhere on the board
IO34_MISO: U2.10 (VDET_1); also elsewhere on the board
IO35_VSYNC: U2.11 (VDET_2); also elsewhere on the board
IO36_BTN: PB1.1, PB1.2, R16.1, U2.5 (SENSOR_VP)
IO39_MODE: R17.1, U2.8 (SENSOR_VN)
unnamed: C23.1, U2.44 (XTAL_N), XTAL2.1
unnamed: C22.1, U2.45 (XTAL_P), XTAL2.3
unnamed: LED3.1 (RA), R18.2
unnamed: C24.1, Q1.3 (C), R13.1, U2.9 (CHIP_PU)
unnamed: R12.2, U2.2 (LNA_IN)
unnamed: C21.1, U2.48 (CAP1)
unnamed: LED3.2 (GA), R19.2
unnamed: Q1.2 (B), R21.2
unnamed: Q1.5 (B), R20.2
PHY_CRS_DV: U2.16 (GPIO27); also elsewhere on the board
PHY_MDC: U2.36 (GPIO23); also elsewhere on the board
PHY_MDIO: U2.35 (GPIO18); also elsewhere on the board
PHY_RXD0: U2.14 (GPIO25); also elsewhere on the board
PHY_RXD1: U2.15 (GPIO26); also elsewhere on the board
PHY_TXD0: U2.38 (GPIO19); also elsewhere on the board
PHY_TXD1: U2.39 (GPIO22); also elsewhere on the board
PHY_TX_EN: U2.42 (GPIO21); also elsewhere on the board
RTSN: Q1.4 (E), R21.1; also elsewhere on the board
SDI_SD1: U2.33 (SD_DATA_1), U3.5 (DI(IO0)), U4.5 (SI/SIO0)
SDO_SD0: U2.32 (SD_DATA_0), U3.2 (DO(IO1)), U4.2 (SD/SIO1)
SD_CLK: U2.31 (SD_CLK), U3.6 (CLK)
SD_CMD: U2.30 (SD_CMD), U3.1 (!CS)
SHD_SD2: U2.28 (SD_DATA_2), U3.7 (!HOLD!(IO3)), U4.7 (SIO3)
SRAM_CLK: U2.27 (GPIO17), U4.6 (SCLK)
SRAM_CSN: R27.1, U2.25 (GPIO16), U4.1 (CE#)
SWP_SD3: U2.29 (SD_DATA_3), U3.3 (!WP!(IO2)), U4.3 (SIO2)
TXD: R14.2; also elsewhere on the board
VDD_SDIO: C18.1, R27.2, U2.26 (VDD_SDIO), U3.8 (VCC), U4.8 (VCC)

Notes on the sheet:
Board Type = tCam-POE
VDD_SDIO (internally strapped low) = 3.3V
Network Reset / FW Update Auth
Mode = Ethernet IF
Camera Status
IO0 circuitry close to ESP32 pin
Cstray ~ 5.5 pF
danjuliodesigns, LLC
Uncontrolled

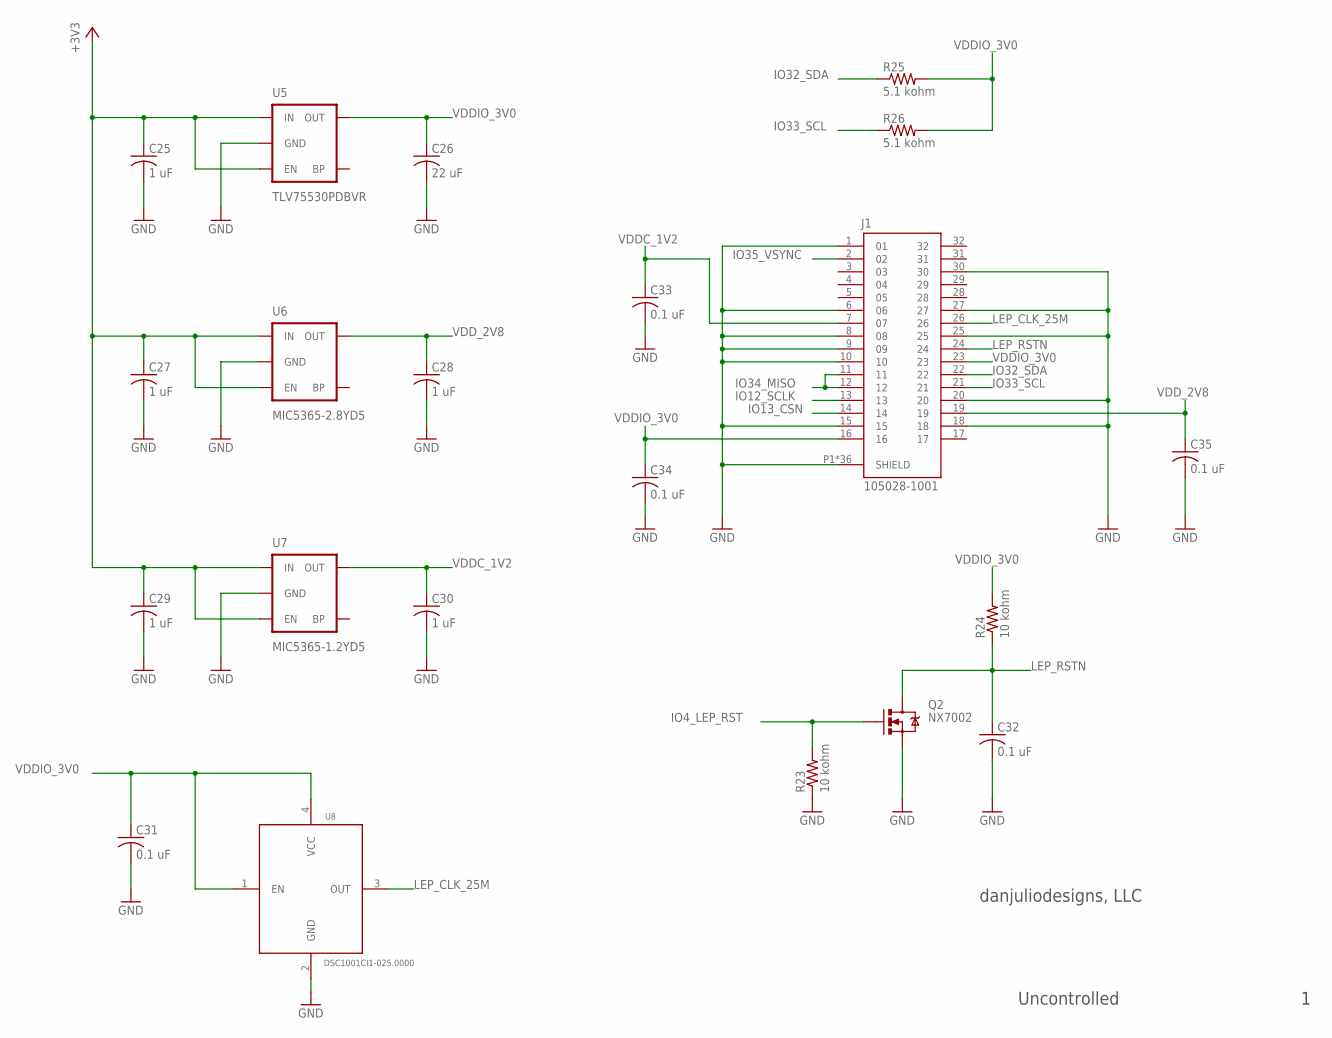
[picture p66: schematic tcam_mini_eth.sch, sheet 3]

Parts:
C25, C27, C28, C29, C30: 1 uF; C0402
C26: 22 uF; C0603
C31, C32, C33, C34, C35: 0.1 uF; C0402
J1: 105028-1001; MOLEX_105028-1001
Q2: NX7002; SOT23-3
R23, R24: 10 kohm; R0402
R25, R26: 5.1 kohm; R0402
U5: TLV75530PDBVR; SOT23-5
U6: MIC5365-2.8YD5; SOT23-5
U7: MIC5365-1.2YD5; SOT23-5
U8: DSC1001CI1-025.0000; CRYSTAL-3225

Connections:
+3V3: C25.1, C27.1, C29.1, U5.1 (IN), U5.3 (EN), U6.1 (IN), U6.3 (EN), U7.1 (IN), U7.3 (EN); also elsewhere on the board
GND: C25.2, C26.2, C27.2, C28.2, C29.2, C30.2, C31.2, C32.2, C33.2, C34.2, C35.2, J1.1, J1.6, J1.8, J1.9, J1.10, J1.15, J1.18, J1.20, J1.25, J1.27, J1.30, J1.P1 (SHIELD), J1.P2 (SHIELD), J1.P3 (SHIELD), J1.P4 (SHIELD), J1.P5 (SHIELD), J1.P6 (SHIELD), J1.P7 (SHIELD), J1.P8 (SHIELD), J1.P9 (SHIELD), J1.P10 (SHIELD), J1.P11 (SHIELD), J1.P12 (SHIELD), J1.P13 (SHIELD), J1.P14 (SHIELD), J1.P15 (SHIELD), J1.P16 (SHIELD), J1.P17 (SHIELD), J1.P18 (SHIELD), J1.P19 (SHIELD), J1.P20 (SHIELD), J1.P21 (SHIELD), J1.P22 (SHIELD), J1.P23 (SHIELD), J1.P24 (SHIELD), J1.P25 (SHIELD), J1.P26 (SHIELD), J1.P27 (SHIELD), J1.P28 (SHIELD), J1.P29 (SHIELD), J1.P30 (SHIELD), J1.P31 (SHIELD), J1.P32 (SHIELD), J1.P33 (SHIELD), J1.P34 (SHIELD), J1.P35 (SHIELD), J1.P36 (SHIELD), Q2.2 (S), R23.1, U5.2 (GND), U6.2 (GND), U7.2 (GND), U8.2 (GND); also elsewhere on the board
IO4_LEP_RST: Q2.1 (G), R23.2; also elsewhere on the board
IO12_SCLK: J1.13; also elsewhere on the board
IO13_CSN: J1.14; also elsewhere on the board
IO32_SDA: J1.22, R25.1; also elsewhere on the board
IO33_SCL: J1.21, R26.1; also elsewhere on the board
IO34_MISO: J1.11, J1.12; also elsewhere on the board
IO35_VSYNC: J1.2; also elsewhere on the board
LEP_CLK_25M: J1.26, U8.3 (OUT)
LEP_RSTN: C32.1, J1.24, Q2.3 (D), R24.1
VDDC_1V2: C30.1, C33.1, J1.7, U7.5 (OUT)
VDDIO_3V0: C26.1, C31.1, C34.1, J1.16, J1.23, R24.2, R25.2, R26.2, U5.5 (OUT), U8.1 (EN), U8.4 (VCC)
VDD_2V8: C28.1, C35.1, J1.19, U6.5 (OUT)

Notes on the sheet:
danjuliodesigns, LLC
Uncontrolled

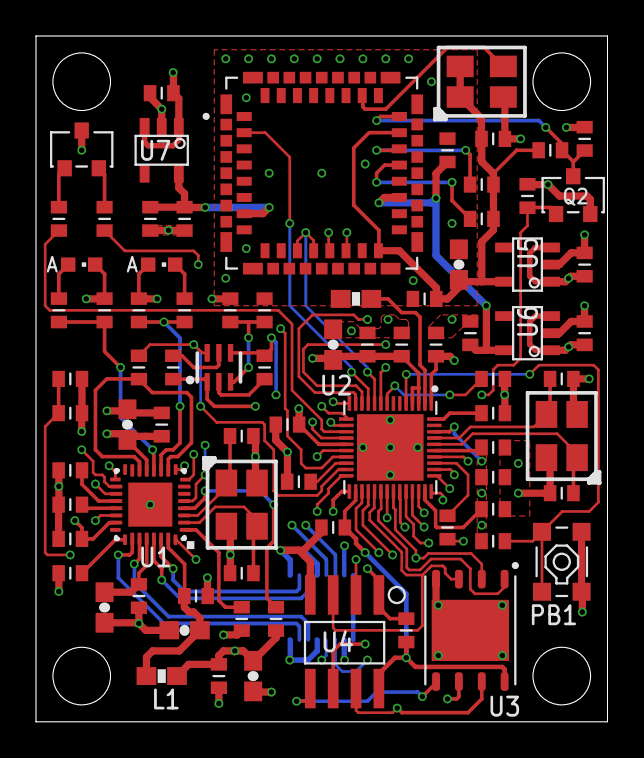
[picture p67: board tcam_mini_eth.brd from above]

Board: 4 copper layers, 31.8 x 38.1 mm, 81 parts (1 on the bottom side), 70 nets.

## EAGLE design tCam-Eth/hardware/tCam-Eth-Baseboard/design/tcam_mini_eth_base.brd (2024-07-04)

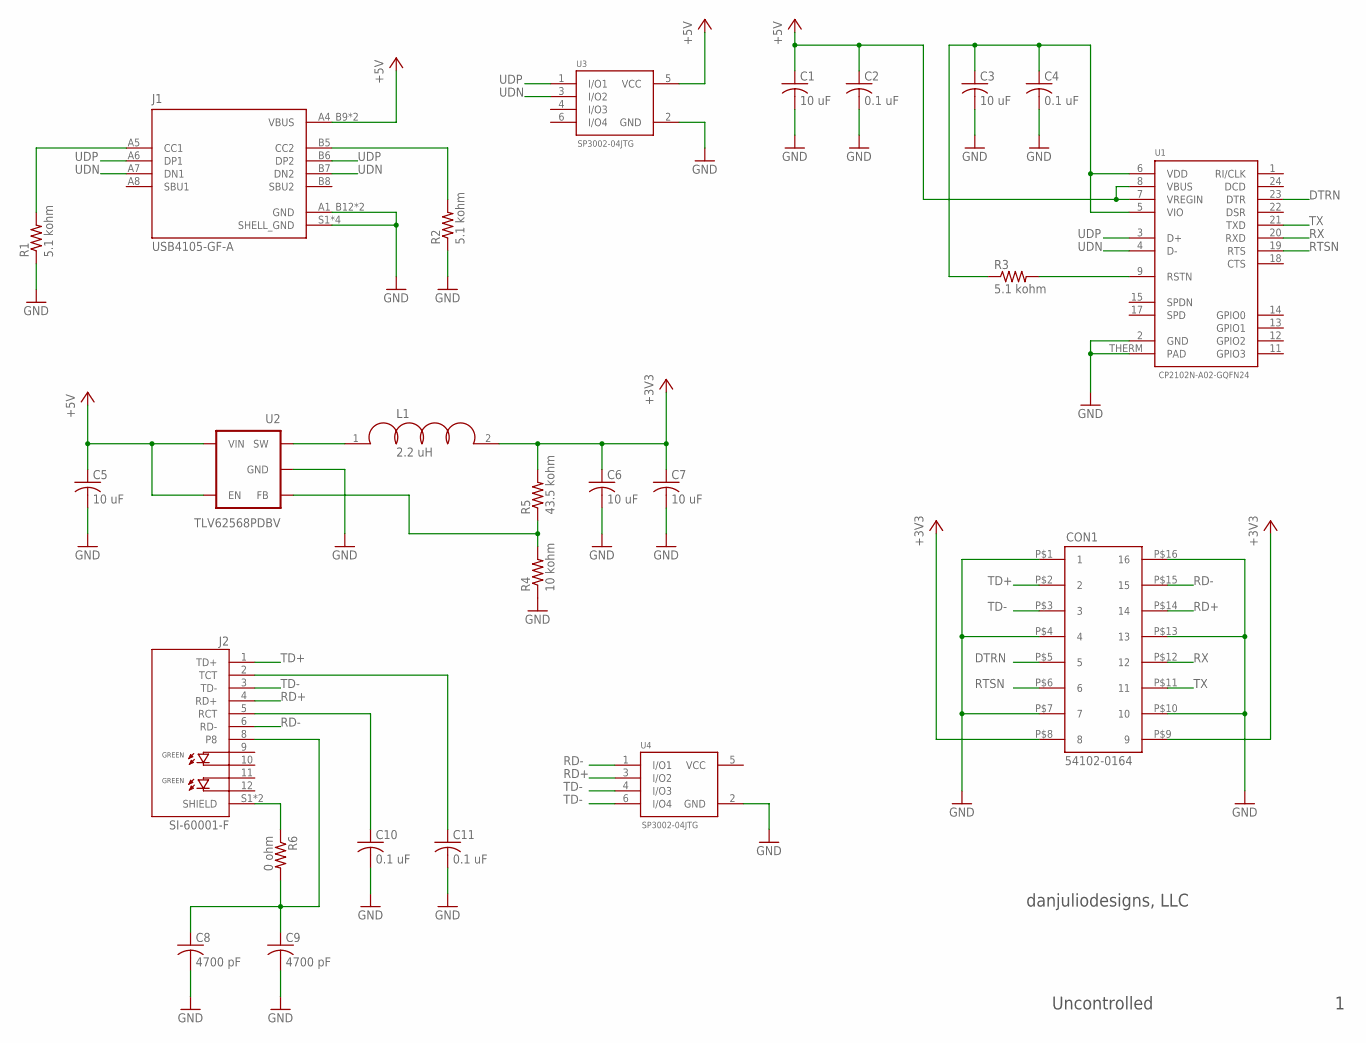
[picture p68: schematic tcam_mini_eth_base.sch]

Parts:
C1, C3, C5, C6, C7: 10 uF; C0603
C2, C4, C10, C11: 0.1 uF; C0603
C8, C9: 4700 pF; C1210
CON1: 54102-0164; MOLEX_54102_0164
J1: USB4105-GF-A; GCT_USB4105-GF-A
J2: SI-60001-F; BEL_SI-60001-F
L1: 2.2 uH; L1008
R1, R2, R3: 5.1 kohm; R0603
R4: 10 kohm; R0603
R5: 43.5 kohm; R0603
R6: 0 ohm; R0805
U1: CP2102N-A02-GQFN24; QFN24
U2: TLV62568PDBV; SOT23-5
U3, U4: SP3002-04JTG; SOT65P220X95-6N

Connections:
+3V3: C6.1, C7.1, CON1.P$8 (8), CON1.P$9 (9), L1.2, R5.2
+5V: C1.1, C2.1, C5.1, J1.A4_B9 (VBUS), J1.B4_A9 (VBUS), U1.7 (VREGIN), U1.8 (VBUS), U2.1 (EN), U2.4 (VIN), U3.5 (VCC)
DTRN: CON1.P$5 (5), U1.23 (DTR)
GND: C1.2, C2.2, C3.2, C4.2, C5.2, C6.2, C7.2, C8.2, C9.2, C10.2, C11.2, CON1.P$1 (1), CON1.P$4 (4), CON1.P$7 (7), CON1.P$10 (10), CON1.P$13 (13), CON1.P$16 (16), J1.A1_B12 (GND), J1.B1_A12 (GND), J1.S1 (SHELL_GND), J1.S2 (SHELL_GND), J1.S3 (SHELL_GND), J1.S4 (SHELL_GND), R1.1, R2.1, R4.1, U1.2 (GND), U1.THERM (PAD), U2.2 (GND), U3.2 (GND), U4.2 (GND)
unnamed: J1.A5 (CC1), R1.2
unnamed: J1.B5 (CC2), R2.2
unnamed: L1.1, U2.3 (SW)
unnamed: R4.2, R5.1, U2.5 (FB)
unnamed: R3.2, U1.9 (RSTN)
unnamed: C10.1, J2.5 (RCT)
unnamed: C11.1, J2.2 (TCT)
unnamed: J2.S1 (SHIELD), J2.S2 (SHIELD), R6.1
unnamed: C8.1, C9.1, J2.8, R6.2
RD+: CON1.P$14 (14), J2.4 (RD+), U4.3 (I/O2)
RD-: CON1.P$15 (15), J2.6 (RD-), U4.1 (I/O1)
RTSN: CON1.P$6 (6), U1.19 (RTS)
RX: CON1.P$12 (12), U1.20 (RXD)
TD+: CON1.P$2 (2), J2.1 (TD+), U4.6 (I/O4)
TD-: CON1.P$3 (3), J2.3 (TD-), U4.4 (I/O3)
TX: CON1.P$11 (11), U1.21 (TXD)
UDN: J1.A7 (DN1), J1.B7 (DN2), U1.4 (D-), U3.3 (I/O2)
UDP: J1.A6 (DP1), J1.B6 (DP2), U1.3 (D+), U3.1 (I/O1)
VCC: U4.5 (VCC)
VDD: C3.1, C4.1, R3.1, U1.5 (VIO), U1.6 (VDD)

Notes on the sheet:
danjuliodesigns, LLC
Uncontrolled

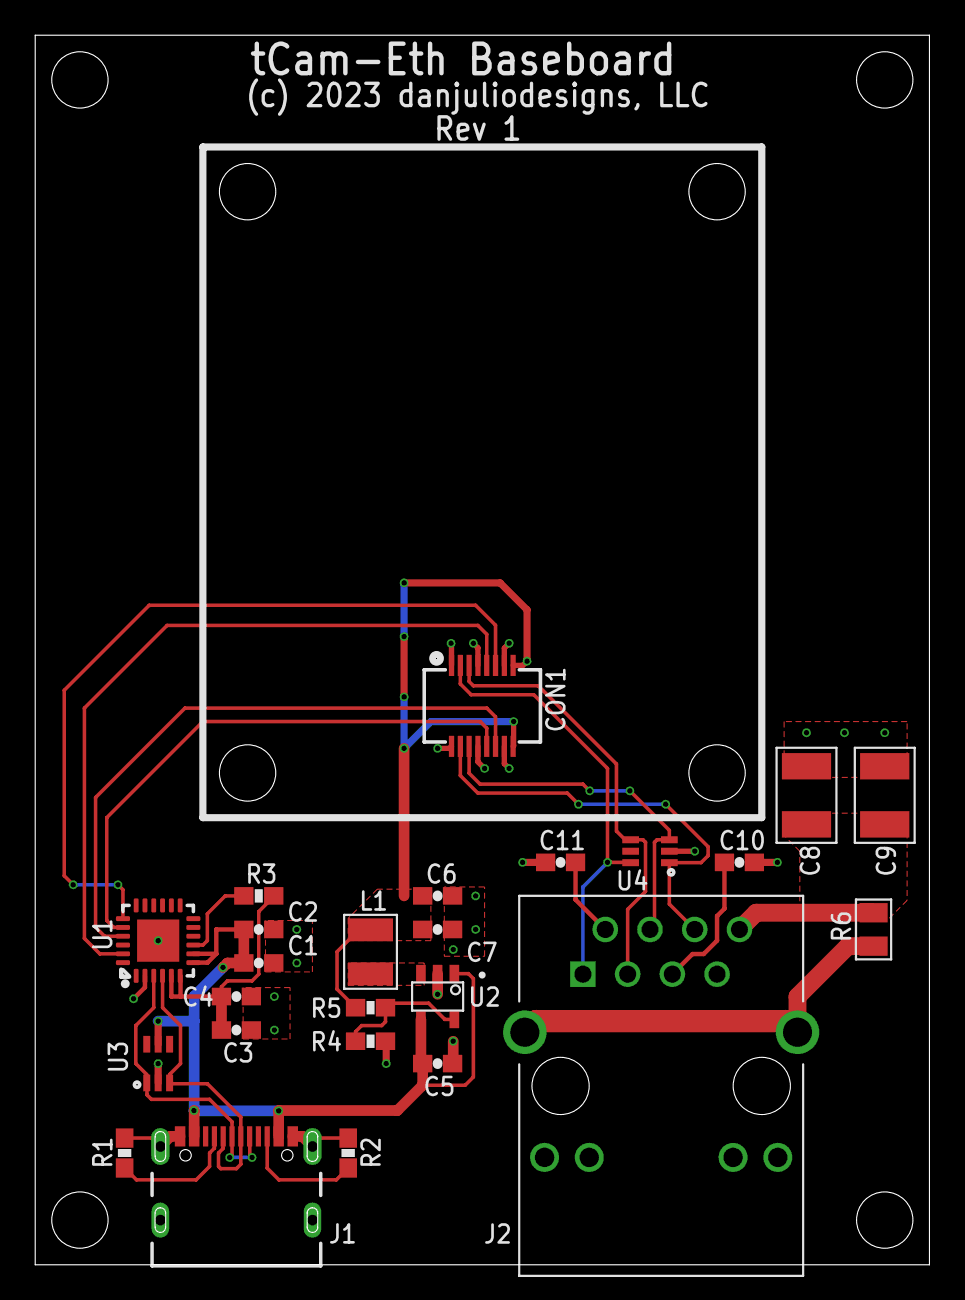
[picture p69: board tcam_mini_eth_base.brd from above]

Board: 2 copper layers, 50.8 x 69.8 mm, 25 parts (0 on the bottom side), 23 nets.

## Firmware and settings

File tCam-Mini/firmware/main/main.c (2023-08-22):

/*
 * tCam-Mini Main
 *
 *
 * Copyright 2020-2022 Dan Julio
 *
 * This file is part of tCam.
 *
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
 * You should have received a copy of the GNU General Public License
 * along with tCam.  If not, see <https://www.gnu.org/licenses/>.
 */
#include <stdio.h>
#include <stdbool.h>
#include "freertos/FreeRTOS.h"
#include "freertos/task.h"
#include "esp_log.h"
#include "net_cmd_task.h"
#include "sif_cmd_task.h"
#include "ctrl_task.h"
#include "lep_task.h"
#include "mon_task.h"
#include "rsp_task.h"
#include "system_config.h"
#include "sys_utilities.h"



static const char* TAG = "main";

void app_main(void)
{
	int brd_type;
	int if_mode;
	
    ESP_LOGI(TAG, "tCamMini starting");
    
    // Start the control task to light the red light immediately
    // and to determine what kind of interface we will be using
    xTaskCreatePinnedToCore(&ctrl_task, "ctrl_task", 2176, NULL, 1, &task_handle_ctrl, 0);
    
    // Allow task to start and determine operating mode
    vTaskDelay(pdMS_TO_TICKS(50));
    ctrl_get_if_mode(&brd_type, &if_mode);
    
    // Initialize the SPI and I2C drivers
    if (!system_esp_io_init(brd_type, if_mode)) {
    	ESP_LOGE(TAG, "ESP32 init failed");
    	ctrl_set_fault_type(CTRL_FAULT_ESP32_INIT);
    	while (1) {vTaskDelay(pdMS_TO_TICKS(100));}
    }
    
    // Initialize the camera's peripheral devices
    if (!system_peripheral_init(brd_type, if_mode)) {
    	ESP_LOGE(TAG, "Peripheral init failed");
    	ctrl_set_fault_type(CTRL_FAULT_PERIPH_INIT);
    	while (1) {vTaskDelay(pdMS_TO_TICKS(100));}
    }
    
    // Pre-allocate big buffers
    if (!system_buffer_init()) {
    	ESP_LOGE(TAG, "Memory allocate failed");
    	ctrl_set_fault_type(CTRL_FAULT_MEM_INIT);
    	while (1) {vTaskDelay(pdMS_TO_TICKS(100));}
    }
    
    // Delay for Lepton internal initialization on power-on (max 950 mSec)
    vTaskDelay(pdMS_TO_TICKS(900));
    
    // Notify control task that we've successfully started up
    xTaskNotify(task_handle_ctrl, CTRL_NOTIFY_STARTUP_DONE, eSetBits);
    
    // Start tasks
    //  Core 0 : PRO - everything but lepton task
    //  Core 1 : APP - lepton task
    if (if_mode == CTRL_IF_MODE_SIF) {
    	xTaskCreatePinnedToCore(&sif_cmd_task, "sif_cmd_task",  3072, NULL, 1, &task_handle_cmd,  0);
    	xTaskCreatePinnedToCore(&rsp_task, "rsp_task",  2816, NULL, 19, &task_handle_rsp,  0);
    	xTaskCreatePinnedToCore(&lep_task, "lep_task",  2304, NULL, 18, &task_handle_lep,  1);
    } else {
    	xTaskCreatePinnedToCore(&net_cmd_task, "net_cmd_task",  3072, NULL, 1, &task_handle_cmd,  0);
    	xTaskCreatePinnedToCore(&rsp_task, "rsp_task",  2816, NULL, 19, &task_handle_rsp,  0);
    	xTaskCreatePinnedToCore(&lep_task, "lep_task",  2304, NULL, 19, &task_handle_lep,  1);
    }

#ifdef INCLUDE_SYS_MON
	xTaskCreatePinnedToCore(&mon_task, "mon_task",  2048, NULL, 1, &task_handle_mon,  0);
#endif
}

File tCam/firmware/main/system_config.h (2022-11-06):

/*
 * System Configuration File
 *
 * Contains system definition and configurable items.
 *
 * Copyright 2020-2022 Dan Julio
 *
 * This file is part of tCam.
 *
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
 */
#ifndef SYSTEM_CONFIG_H
#define SYSTEM_CONFIG_H

#include "esp_system.h"


// ======================================================================================
// System debug
//

// Undefine to include the system monitoring task (included only for debugging/tuning)
//#define INCLUDE_SYS_MON



// ======================================================================================
// System hardware definitions
//

//
// IO Pins
//   LCD uses VSPI (no MISO)
//   Lepton uses HSPI (no MOSI)
//

#define I2C_MASTER_SDA_IO 21
#define I2C_MASTER_SCL_IO 22

#define LCD_SCK_IO        18
#define LCD_CSN_IO        5
#define LCD_DC_IO         27
#define LCD_MOSI_IO       23

#define LEP_TX_IO         0
#define LEP_RX_IO         19
#define LEP_SCK_IO        32
#define LEP_CSN_IO        26
#define LEP_MISO_IO       25


//
// Hardware Configuration
//
// I2C
#define I2C_MASTER_NUM     1
#define I2C_MASTER_FREQ_HZ 100000

// SPI
//   Lepton uses HSPI (no MOSI)
//   LCD and TS use VSPI
#define LCD_SPI_HOST    VSPI_HOST
#define LEP_SPI_HOST    HSPI_HOST
#define LCD_DMA_NUM     1
#define LEP_DMA_NUM     2
#define LCD_SPI_FREQ_HZ 80000000
#define LEP_SPI_FREQ_HZ  7000000
#define LCD_SPI_MODE    0
#define LEP_SPI_MODE    0



// ======================================================================================
// System configuration
//

// Camera model number - tCam is model 1
#define CAMERA_MODEL_NUM 1

// tCam capabilities mask 
//   Bit  7: 0: Camera model number
//   Bit  9: 8: Lepton Type (set during run time)
//        0  0 - Lepton 3.5
//        0  1 - Lepton 3.0
//        1  0 - Lepton 3.1
//        1  1 - Reserved
//   Bit 13:12: Interface Type
//        0  0 - WiFi (set)
//        0  1 - Serial/SPI interface
//        1  0 - Ethernet
//        1  1 - Reserved
//   Bit     16: Has Battery (set)
//   Bit     17: Has Filesystem (set)
//   Bit     18: Has OTA Firmware Updates (set)
#define CAMERA_CAP_MASK_CORE    0x00070000
#define CAMERA_CAP_MASK_LEP3_5  0x00000000
#define CAMERA_CAP_MASK_LEP3_0  0x00000100
#define CAMERA_CAP_MASK_LEP3_1  0x00000200
#define CAMERA_CAP_MASK_LEP_UNK 0x00000300
#define CAMERA_CAP_MASK_LEP_MSK 0x00000300


// Maximum number of images in a video
//   Each image requires slightly less than JSON_MAX_IMAGE_TEXT_LEN bytes
#define MAX_VIDEO_IMAGES    8192


// Uncomment to include the screen-dump code
//#define SYS_SCREENDUMP_ENABLE


// Little VGL buffer update size
#define LVGL_DISP_BUF_SIZE (480 * 10)

// Theme hue (0-360)
#define GUI_THEME_HUE       240


// Lepton displayed image size
#define LEP_IMG_WIDTH  320
#define LEP_IMG_HEIGHT 240
#define LEP_IMG_PIXELS (LEP_IMG_WIDTH * LEP_IMG_HEIGHT)


// Image (Lepton + Telemetry + Metadata) json object text size
// Based on the following items:
//   1. Base64 encoded Lepton image size: (160x120x2)*4 / 3 = 51200
//   2. Base64 encoded Lepton telemetry size: (80x3x2)*4 / 3 = 640
//   3. Metadata text size: 1024
//   4. Json object overhead (child names, formatting characters, NLs): 128
// Manually calculate this and round to 4-byte boundary
#define JSON_MAX_IMAGE_TEXT_LEN (1024 * 53)

// Maximum firmware update chunk request size
#define FW_UPD_CHUNK_MAX_LEN    (1024 * 8)

// Max command response json object text size
#define JSON_MAX_RSP_TEXT_LEN   2048

// Max Lepton command json object text size
#define JSON_MAX_LEP_CMD_TEXT_LEN 2048

// Command Response Buffer Size (large enough for several responses)
#define CMD_RESPONSE_BUFFER_LEN (JSON_MAX_RSP_TEXT_LEN * 4)

// Lepton Command Buffer Size (large enough for several commands)
#define LEP_COMMAND_BUFFER_LEN (JSON_MAX_LEP_CMD_TEXT_LEN * 4)

// Maximum incoming command json string length
// Large enough for longest command: fw_segment
//    1. Base64 encoded firmware chunk: FW_UPD_CHUNK_MAX_LEN * 4 / 3
//    2. Json object overhead: 128
// Manually calculate this and round to a 4-byte boundary
#define JSON_MAX_CMD_TEXT_LEN   (12 * 1024)

// TCP/IP listening port
#define CMD_PORT 5001

// Serial port baud rate
#define CMD_BAUD_RATE 230400

// Maximum serial port receive buffer (sized to hold a command)
#define SIF_RX_BUFFER_SIZE JSON_MAX_LEP_CMD_TEXT_LEN

// Maximum serial port transmit buffer (sized to hold a non-image response)
#define SIF_TX_BUFFER_SIZE JSON_MAX_RSP_TEXT_LEN

// Filesystem Information Structure buffer (catalog)
//   Holds records for directories (~36 bytes/each) and files in those directories
//   (~32 bytes/each).  This buffer should be sized larger than the most files and
//   directories ever expected to be seen by the system.
#define FILE_INFO_BUFFER_LEN (1024 * 512) 

// Maximum number of names stored in a comma separated catalog listing
#define FILE_MAX_CATALOG_NAMES 150
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

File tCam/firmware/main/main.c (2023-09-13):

/*
 * tCam Main
 *
 *
 * Copyright 2020-2021 Dan Julio
 *
 * This file is part of tCam.
 *
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
 * You should have received a copy of the GNU General Public License
 * along with tCam.  If not, see <https://www.gnu.org/licenses/>.
 */
#include <stdio.h>
#include "freertos/FreeRTOS.h"
#include "freertos/task.h"
#include "esp_log.h"
#include "app_task.h"
#include "cmd_task.h"
#include "file_task.h"
#include "gcore_task.h"
#include "gui_task.h"
#include "lep_task.h"
#include "mon_task.h"
#include "rsp_task.h"
#include "system_config.h"
#include "sys_utilities.h"



static const char* TAG = "main";

void app_main(void)
{
    ESP_LOGI(TAG, "tCam starting");
    
    // Initialize the ESP32 IO pins, set PWR_EN to keep us powered up and initialize
    // the shared SPI and I2C drivers
    if (!system_esp_io_init()) {
    	ESP_LOGE(TAG, "tCam ESP32 init failed - shutting off");
    	system_shutoff();
    }
    
    // Initialize the camera's peripheral devices: RTC, persistent storage, Wifi, file system
    if (!system_peripheral_init()) {
    	ESP_LOGE(TAG, "tCam Peripheral init failed - shutting off");
    	system_shutoff();
    }
    
    // Pre-allocate big buffers
    if (!system_buffer_init()) {
    	ESP_LOGE(TAG, "tCam memory allocate failed - shutting off");
    	system_shutoff();
    }
    
    // Start tasks
    //   Core 0 : PRO
    //   Core 1 : APP
	
	// Create app_task so its handle exists for all other tasks
	xTaskCreatePinnedToCore(&app_task,  "app_task",  2560, NULL, 1, &task_handle_app,  1);
	
    // Start the GUI next (initializing the display takes some time)
    xTaskCreatePinnedToCore(&gui_task,  "gui_task",  2560, NULL, 3, &task_handle_gui,  0);
    
    // Delay to allow tCam-Mini to come up
    vTaskDelay(pdMS_TO_TICKS(1250));
    
    // Start remaining tasks
    xTaskCreatePinnedToCore(&cmd_task,    "cmd_task",    3584, NULL, 2, &task_handle_cmd,    0);
    xTaskCreatePinnedToCore(&file_task,   "file_task",   3072, NULL, 3, &task_handle_file,   1);
    xTaskCreatePinnedToCore(&gcore_task,  "gcore_task",  2048, NULL, 1, &task_handle_gcore,  0);
    xTaskCreatePinnedToCore(&rsp_task,    "rsp_task",    2560, NULL, 2, &task_handle_rsp,    1);
    xTaskCreatePinnedToCore(&lep_task,    "lep_task",    2560, NULL, 3, &task_handle_lep,    1);
#ifdef INCLUDE_SYS_MON
	xTaskCreatePinnedToCore(&mon_task,    "mon_task",    2048, NULL, 1, &task_handle_mon,    1);
#endif
}

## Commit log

2023-01-22 Added tCam-POE
    [tcam_poe_centroid.csv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]
2023-02-10 Updated battery info
2023-03-07 Added note about protecting Lepton when soldering to tCam-Mini
2023-07-10 Added link to zharijs' enclosures
2023-08-17 Added link to CP210X drivers for tCam Family Serial Updater
2023-08-22 Officially support Lepton 3.1R
    Correctly identify Lepton 3.1R production model. tCam-Mini firmware environment moved to IDF 4.4.4. Add 3.1 identification field to camera status Lepton Type.
    [lepton_utilities.c, main.c]
2024-07-04 Added tCam-Eth
    [tcam_eth_base_mount.scad, tcam_eth_base_mount.stl, tcam_eth_baseboard_base.scad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]

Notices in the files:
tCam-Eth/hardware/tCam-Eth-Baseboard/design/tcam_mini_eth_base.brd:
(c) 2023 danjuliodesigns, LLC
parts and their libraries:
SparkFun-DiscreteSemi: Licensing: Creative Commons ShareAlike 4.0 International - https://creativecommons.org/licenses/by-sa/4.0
